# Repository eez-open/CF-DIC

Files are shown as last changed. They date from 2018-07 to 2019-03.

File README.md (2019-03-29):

Current-fed dual inductor converter (CF-DIC) project files

Inspired by article Filho, Barbi (1996), *[A comparison between two current-fed push-pull DC-DC converters-analysis, design and experimentation](https://www.researchgate.net/publication/3673781_A_comparison_between_two_current-fed_push-pull_DC-DC_converters-analysis_design_and_experimentation)* and made with great assistance of Dragoljub Aleksijević (aka *Macola*).

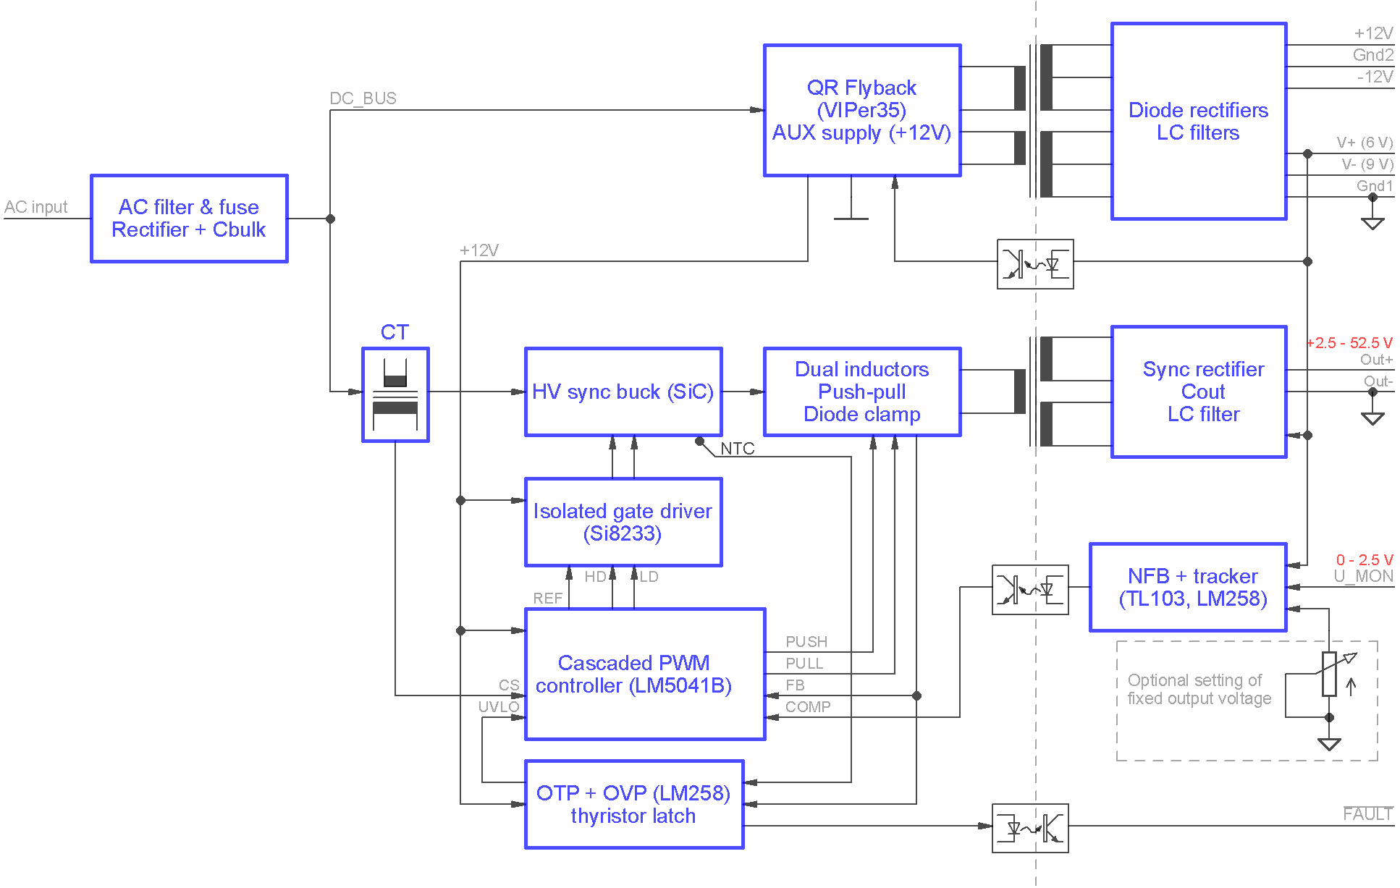
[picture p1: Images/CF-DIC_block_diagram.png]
Block diagram


### Feature list

* Wide range input: 85 – 265 Vac, 120 – 380 Vdc
* Wide range output: 2.5 – 52.5 Vdc 
* Max. current 3 A continuously, or 5 A with forced-air cooling (max. power up to ~260 W)
* Output voltage controlled by tracker circuit or optionally with multiturn trimpot if fixed output voltage is required
* Cascaded PWM Controller LM5041B (sync buck + push-pull stage)
* Isolated HV power ground and signal ground for improved noise immunity
* HV buck section with high performance SiC MOSFET switches
* High performance Vitroperm 500F core material for power transformer
* Synchronous rectifier with low R(ds,on) MOSFET switches
* Over-voltage (OVP), short circuit protection and over-temperature protection (OTP) with latched shutdown and opto-isolated open-collector "Fault" output
* Over-current protection (OCP)
* QR flyback as bias power supply (VIPer35)
* Four bias power supply outputs: +6.5 V, -8 V and "floating" +12 V / -12 V that can be further regulated with LDOs
* Compact size: 157 x 92 x 45 mm
* Weight (with enclosure): 0.49 kg

### r5B6 prototype

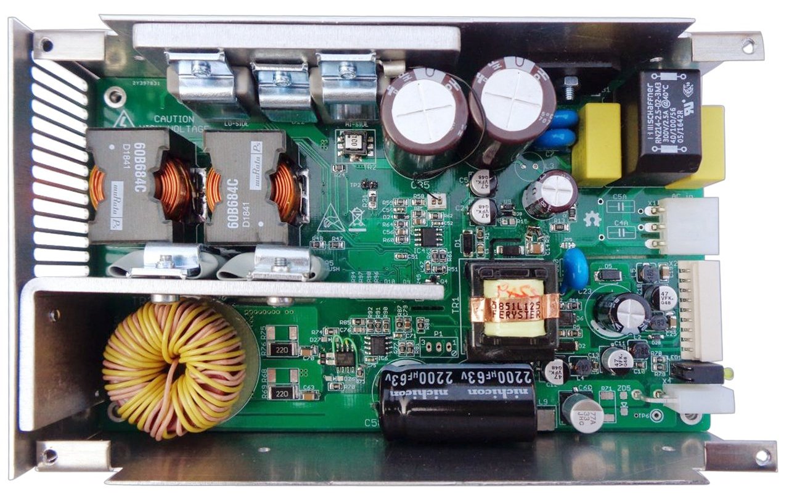
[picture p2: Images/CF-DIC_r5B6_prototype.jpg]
prototype


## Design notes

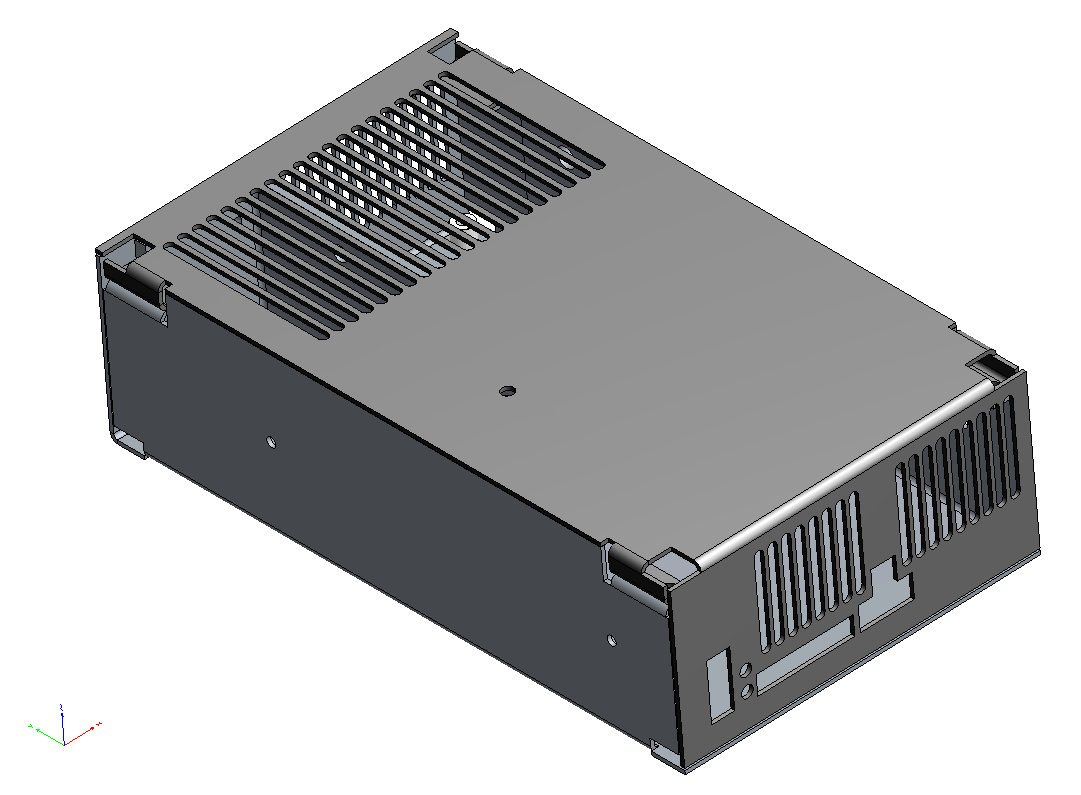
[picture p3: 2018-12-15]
Mechanical/EEZ CF-DIC enclosure prototype.png

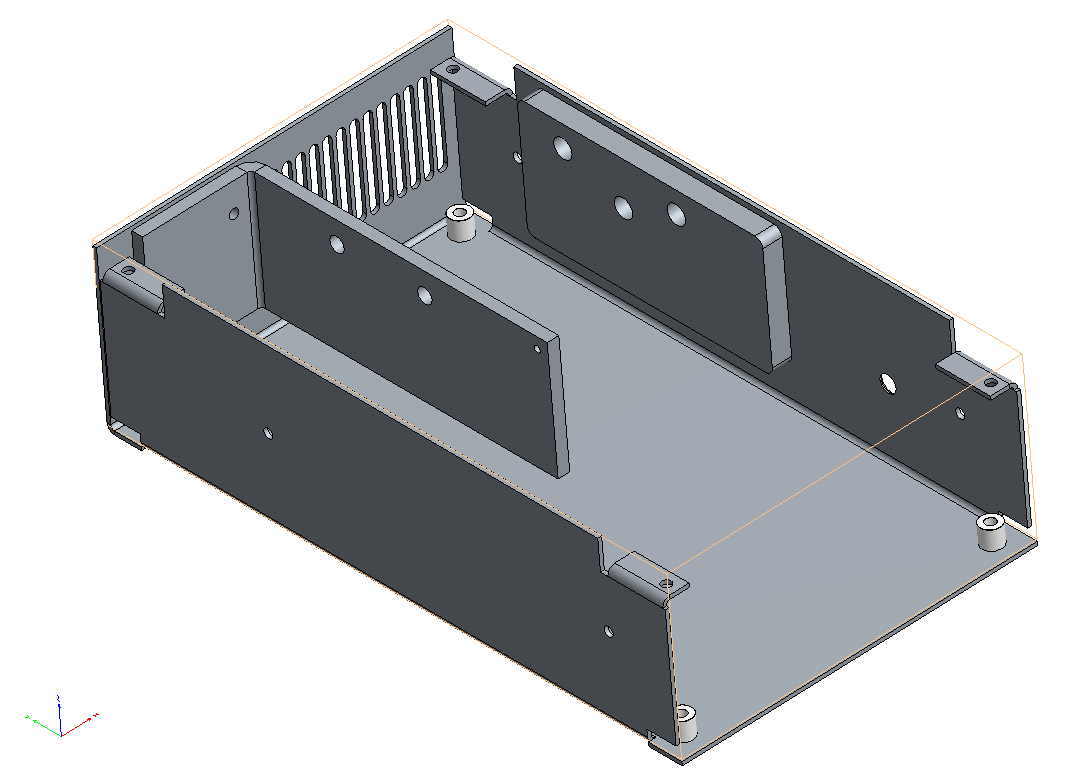
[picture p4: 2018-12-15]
Mechanical/EEZ CF-DIC enclosure prototype (without cover).png

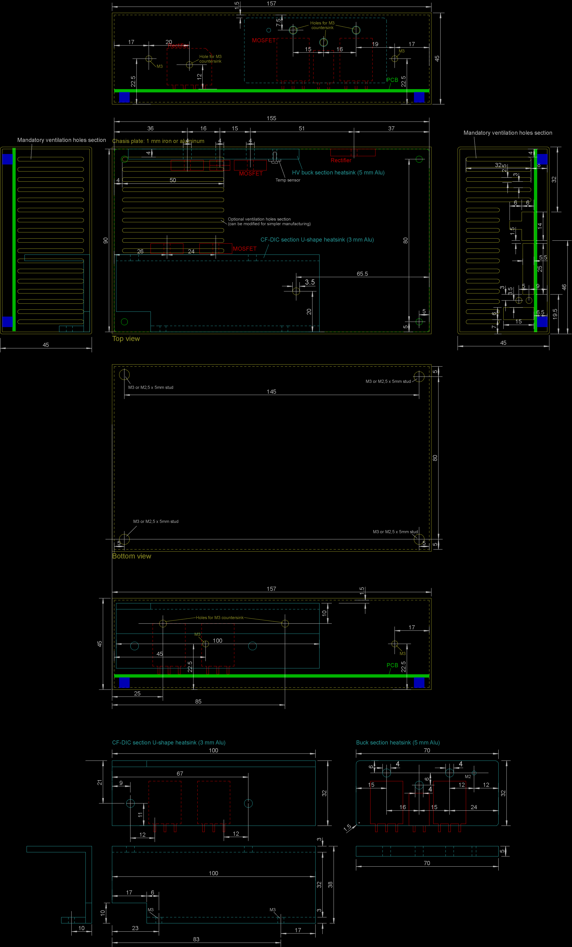
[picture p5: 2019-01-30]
Mechanical/CF-DIC enclosure r5B6.png

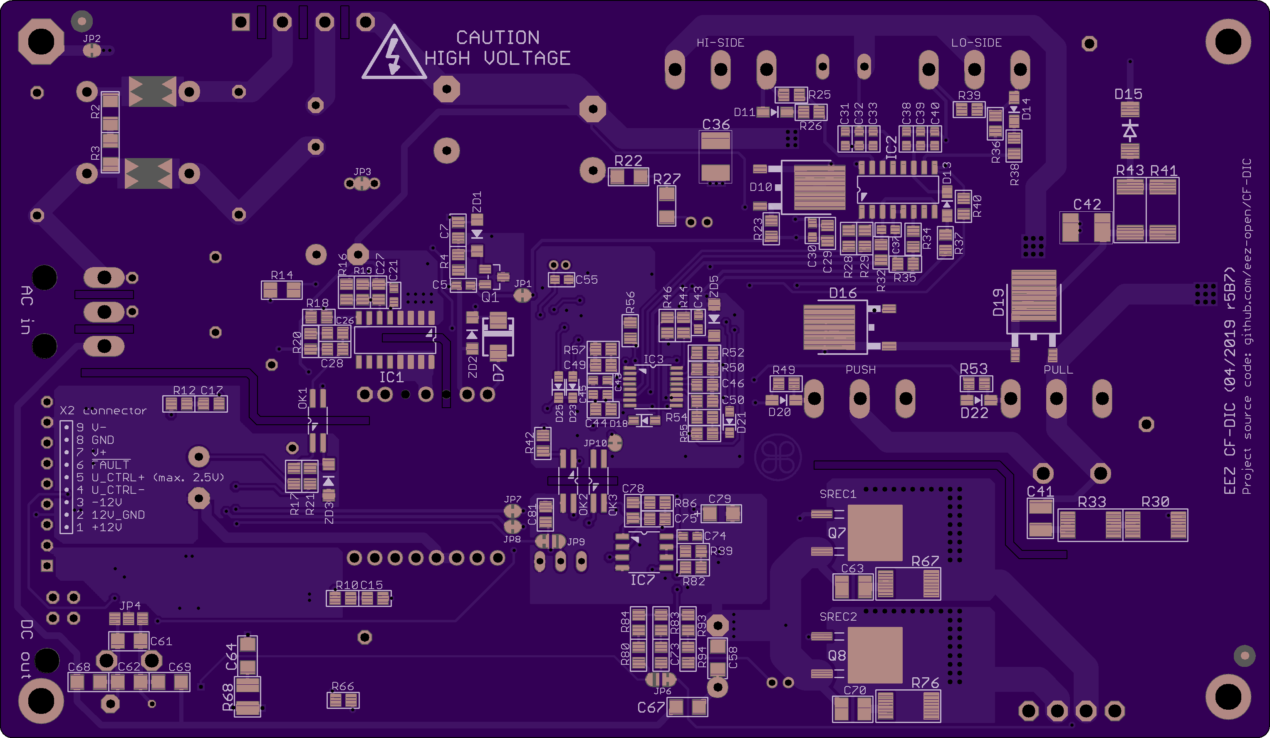
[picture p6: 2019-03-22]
Images/CF-DIC_PCB_bottom_layer.png

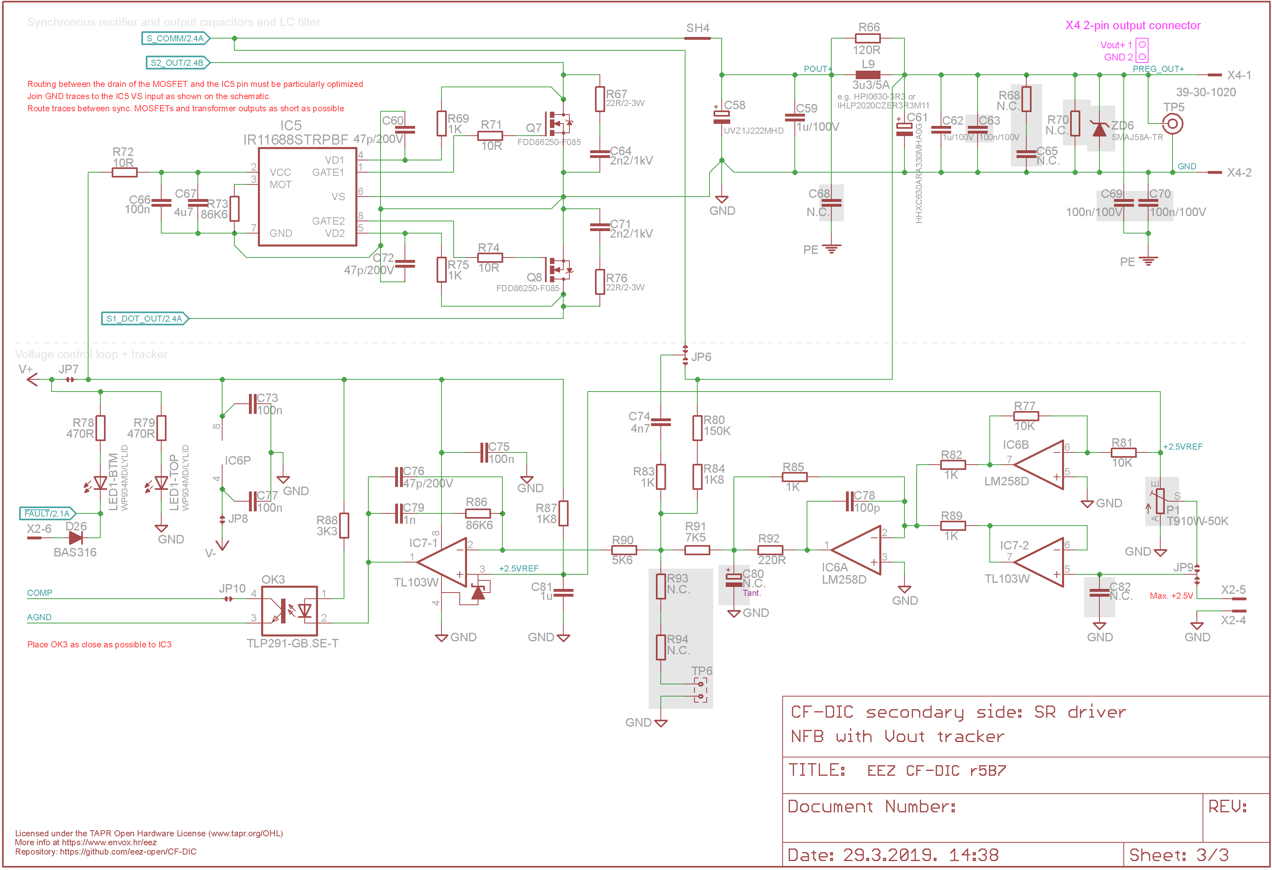
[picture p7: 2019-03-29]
EEZ CF-DIC r5B7 Sheet3of3.png

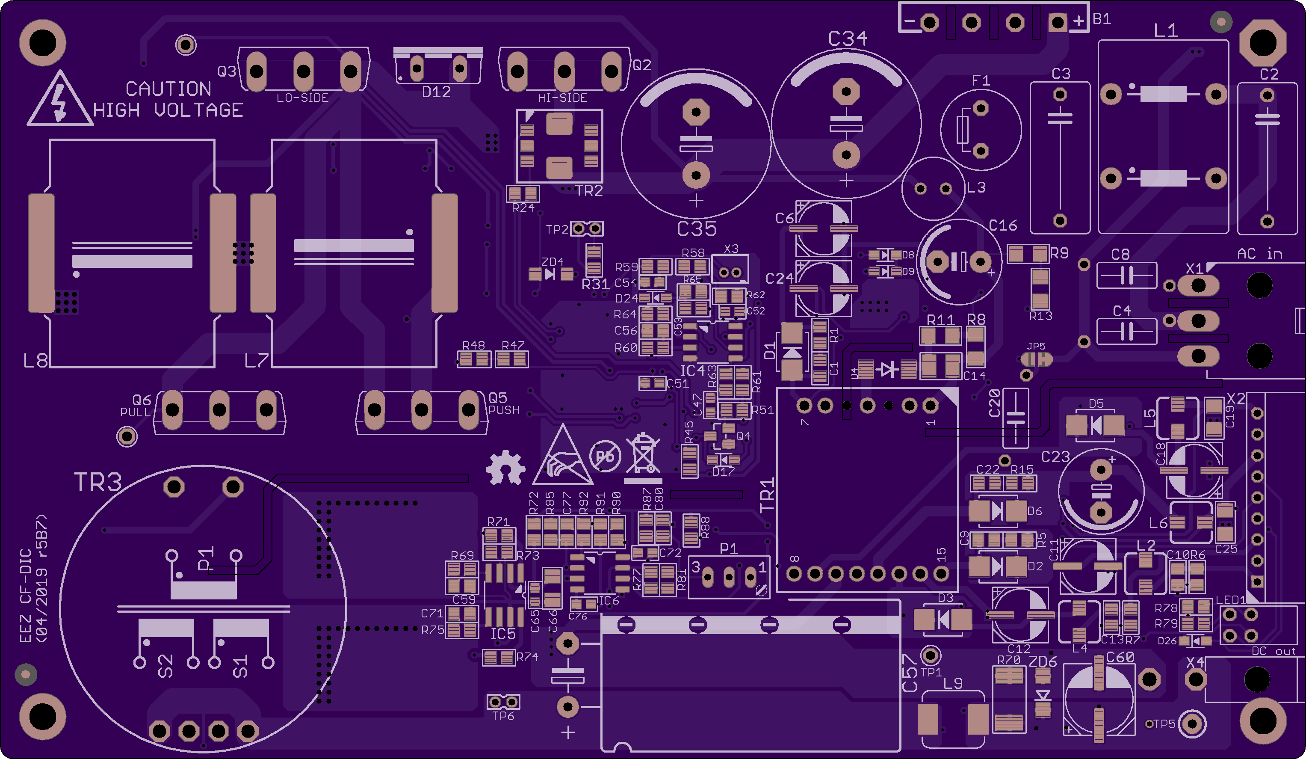
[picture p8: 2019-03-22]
Images/CF-DIC_PCB_top_layer.png

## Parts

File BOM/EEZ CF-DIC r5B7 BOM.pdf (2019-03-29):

EEZ CF-DIC BOM (r5B7, 2019-03-29) Project source code at https://github.com/eez-open/CF-DIC
Farnell / Element14 # Qty Part name Package Reference designator Code Part Number Unit price MOQ € | Digi-Key Part Number Unit price MOQ € | Mouser Part Number Unit price MOQ €
| ND
VJ0805Y332KXAC W1BC | | 80-C0805C332K5R
| | 885342209006
400BXC6R8MEFC 10X16 | | 647-UCY2G6R8MPD
| | 963-EMK316B7475M L-T
THT, PP X2, 18 x 12 x 6 mm, RM 15 | | 80-R463I322050L2K
| | 80-C0603C104M4R
16PK470MEFC8X1 1.5 | | 647-UVZ1C471MPD1 TD
| | 77-VJ0805Y333JXA PBC
| | 710-885342007006
| | 77-VJ0805Y222KXB AC
C0603C103K5RAC 7081 | | 80-C0603C103M5R 3121
| | 647-UPH2G151MHD
C1812C104KBRAC TU | | 810-C4532X7R2J104 M
| | 80-C941U472MYVD BAP
1210 or 1206 MC1210B222K102 CT | | 710-885342208019
| | 710-885012007038
THT, Ø18 x 35.5mm, RM 7.5 | | 647-UVZ1J222MHD
| | 963-HMK316B7105M LHT
Ø6.3 x 5.8 mm | | 667-EEE-FK1V470P
1 | 1 GBU4K | B1 | 2889169 | GBU4K-E3/45 | 1,150 | 5 | 0,750 | 1 | 833-GBU4K-BP | 0,748 | 1
2 | 5 3n3 | 0805 | C1, C9, C15, C17, C22 | 2896578 | 0,025 10 | 1276-1260-1-ND | 0,039 | 10 | 0,024 10
3 | 1 1n/1kV | C14 | 2812601 | 885342209006 | 0,580 | 5 | 732-12116-1-ND | 0,380 | 1 | 0,357 | 1
4 | 1 UCY2G6R8MPD | THT, Ø10.5mm, RM 5 | C16 | 1831309 | 0,868 | 1 | 493-13319-1-ND | 0,730 | 1 | 0,629 | 1
5 | 3 4u7 | 1206 | C19, C25, C67 | 1907356 | 0,240 | 5 | 1276-2970-1-ND | 0,199 | 10 | 0,129 10
6 | 2 MKP-X2-220NR15/310 | C2, C3 | 2446244 | R463I322050L2K | 0,337 | 1 | 399-12681-ND | 0,600 | 1 | 0,600 | 1
7 | 16 100n | 0603 | 2522597 | 0,011 10 | 490-4774-1-ND | 0,029 100 | 0,007 100
8 | 1 470u/16V | THT; Ø8; RM3.5 | C23 | 2346502 | 0,206 | 5 | 493-1286-ND | 0,215 | 10 | 0,194 10
9 | 1 33n | 0805 | C26 | 1414688 | 0,051 10 | 1276-1796-1-ND | 0,068 | 10 | 0,020 50
10 | 4 47p/200V | 0805, C0G | C27, C60, C72, C76 | 2812527 | 885342007006 | 0,081 10 | 885342007006 | 0,058 | 10 | 0,055 10
11 | 1 2n2 | 0805 | C28 | 2896572 | 0,028 10 | 720-1604-1-ND | 0,063 | 10 | 0,032 50
12 | 4 10n | 0603 | C31, C38, C47, C52 | 2522596 | 0,042 10 | 399-1092-1-ND | 0,040 | 10 | 0,031 10
13 | 2 UPH2G151MHD6 | THT, Ø18mm, RM 7.5 | C34, C35 | - | 493-16993-ND | 3,550 | 1 | 3,550 | 1
14 | 2 100n/500V | 1812 | C36, C41 | 2676599 | 0,600 | 1 | 445-2300-1-ND | 0,453 | 10 | 0,408 10
15 | 3 CY1Y-4N7 | C4, C8, C20 | 2440246 | 0,772 | 1 | 399-9504-1-ND | 0,293 | 10 | 0,215 10
16 | 4 2n2/1kV | C44, C48, C64, C71 | 1855965 | 0,496 | 5 | 490-12018-1-ND | 0,502 | 10 | 0,121 10
17 | 2 470p | 0805, C0G | C50, C51 | 1759217 | 0,061 10 | 732-7837-1-ND | 0,059 | 10 | 0,056 10
18 | 1 UVZ1J222MHD | C58 | 1822575 | UVZ1J222MHD | 3,430 | 1 | 493-1360-ND | 2,370 | 1 | 2,490 | 1
19 | 2 1u/100V | 1206 | C59, C62 | 2491179 | 0,374 | 5 | 1276-3094-1-ND | 0,240 | 10 | 0,306 10
20 | 5 EEEFK1V470P | C6, C11, C12, C18, C24 | 9695850 | EEEFK1V470P | 0,344 | 1 | PCE3842CT-ND | 0,312 | 10 | 0,238 10
THT, bridge rectifier 800V, 4A | GBU4K-BPMS-
1210 or 1206 | 710-

C3216X7R1E475K
160AC

C21, C30, C32, C33, C37,
C39, C40, C42, C45, C49,
C53, C55, C66, C73, C75,
C77

C0603C104K4RAC
7081

C0805C333K5RAC
TU

VJ0805Y222KXAC
W1BC
THT, Ceramic Y1, RM 10 | C951U472MVVDB A7317

MC0805N471J500
CT

C1206C105K1RAC
TU

# Qty Part name | RS Components | TME | Price calculation for 1 set

Code Part Number Unit price MOQ € | Code / Part Number Unit price MOQ € | THT SMD

1 1 GBU4K

2 5 3n3

3 1 1n/1kV

4 1 UCY2G6R8MPD

5 3 4u7

6 2 MKP-X2-220NR15/310

7 16 100n

8 1 470u/16V

9 1 33n

10 4 47p/200V

11 1 2n2

12 4 10n

13 2 UPH2G151MHD6

14 2 100n/500V

15 3 CY1Y-4N7

16 4 2n2/1kV

17 2 470p

18 1 UVZ1J222MHD

19 2 1u/100V

20 5 EEEFK1V470P

700-5437 GBU4K-E3/45 | 1,448 | 5 | GBU4K | 0,355 | 3 | 1 | TME | 0,355 € | 1 | 0,355
237-7009 | 0,060 50 | 0,023 100 | 5 | TME | 0,023 € | 5 | 0,116
500-2499 | 0,880 | 5 | 1210B102K102CT | 0,343 10 | 1 | TME | 0,343 € | 1 | 0,343
739-4551 UCA2G6R8MPD | 1,008 | 1 | UCY2G6R8MPD | 0,240 | 5 | 1 | TME | 0,240 € | 1 | 0,240
691-1221 | 0,232 25 | 0,381 10 | 3 | Mouser | 0,129 € | 3 | 0,387
875-2257 | 0,372 25 | MKP-X2-220NR15/310 | 0,116 10 | 2 | TME | 0,116 € | 2 | 0,231
393-6952 | 0,069 25 | CL10B104KA8NNNC | 0,098 100 | 16 | Mouser | 0,007 € 16 | 0,112
845-4666 UVZ1C471MPD | 0,215 25 | UVZ1C471MPD | 0,140 | 5 | 1 | TME | 0,140 € | 1 | 0,140
652-0982 | 0,066 25 | CL21B333KBANNNC | 0,035 100 | 1 | Mouser | 0,020 € | 1 | 0,020
535-2873 | 0,039 50 | 0805N470J201CT | 0,031 100 | 4 | TME | 0,031 € | 4 | 0,123
264-4359 | 0,031 25 | 0,020 100 | 1 | TME | 0,020 € | 1 | 0,020
264-4595 | 0,035 25 | C0603X103K5RACTU | 0,080 100 | 4 | Mouser | 0,031 € | 4 | 0,124
- | | | UPH2G151MHD6 | 1,950 | 1 | 2 | TME | 1,950 € | 2 | 3,900
371-6887 C4532JB2J104K | 0,460 10 | 1812B104K501CT | 0,663 10 | 2 | Mouser | 0,408 € | 2 | 0,816
- | CY1Y-4N7 | 0,153 10 | 3 | TME | 0,153 € | 3 | 0,458
723-6492 | 0,246 25 | 1206B222K102CT | 0,030 50 | 4 | TME | 0,030 € | 4 | 0,118
378-700 | 0,040 25 | 0,024 100 | 2 | TME | 0,024 € | 2 | 0,048
862-1759 UVZ1J222MHD | 2,440 | 1 | UVZ1J222MHD | 1,209 | 2 | 1 | TME | 1,209 € | 1 | 1,209
916-2977 | 0,290 20 | CL31B105KCHSNNE | 0,211 10 | 2 | TME | 0,211 € | 2 | 0,422
537-0657 EEEFK1V470P | 0,394 | 5 | EEEFK1V470P | 0,130 | 5 | 5 | TME | 0,130 € | 5 | 0,650

Best
Supplier

Lowest
unit price
€

Order
Qty Line Cost €

GRM216R71H3
32KA01D

VJ0805Y333KXACW1
BC
C1210C102JDG
ACTU

C1206C475K3R
ACTU

GCM31CR71E475KA5 5L

| R463I322050M2 K

VJ0603Y104KXJ
AT

VJ0805Y333KX
AAT

VJ0805A470JX CAC

| VJ0805Y222KXACW1 BC

C0603C103K5R ACTU

C0805C222K5R
ACTU

GRM31BR73A2 22KW01L

| CC0805JRNPO9BN47 1

0805CG471J9B
B

C3216X7R2A10
5K160AM

# Qty Part name Package Reference designator Code Part Number Unit price MOQ € | Part Number Unit price MOQ € | Part Number Unit price MOQ €

| | 0MHA0G
VJ0805Y104KXBT W1BC | | 810-C2012X7R2A104 K
| | 603-CC805MKX7R7B B105
24 | 1 4n7 0804 C74
| | | 80-C0805C101J5G
| VJ0805A102JXAC W1BC | | 710-885012007040
21 | 1 | C61 | - | 565-4788-1-ND | 0,890 | 1 | 0,770 | 1
22 | 1 100n/100V | 1206 | C63 | 2896560 | 0,070 10 | 1276-6840-1-ND | 0,068 | 10 | 0,065 10
23 | 9 1u | 0805 | 2896566 | 0,084 | 5 | 587-1283-1-ND | 0,090 | 10 | 0,062 10
25 | 1 100p | 0805, C0G | C78 | 2896466 | 0,041 10 | 399-1121-1-ND | 0,061 | 10 | 0,022 10
26 | 1 1n | 0805, C0G | C79 | 2896470 | 0,044 10 | 732-7858-1-ND | 0,055 | 10 | 0,052 10
27 | 6 SS110B | SMB | D1, D2, D3, D5, D6, D7 | 1861422 | SS110B | 0,097 | 5 | SS110-TPCT-ND | 0,350 | 1 | 833-SS110FL-TP | 0,323 | 1
28 | 3 C3D02065E | TO-252 (DPAK) | D10, D16, D19 | - | | | | C3D02065E-ND | 0,860 | 1 | 941-C3D02065E | 0,859 | 1
29 | 1 C3D03060A | THT, TO-220 | D12 | - | | | | C3D03060A-ND | 1,250 | 1 | 941-C3D03060A | 1,240 | 1
30 | 1 1N5819HW-7-F | SOD-323 | D13 | 2306459 | 1N5819HW-7-F | 0,183 10 | 0,310 | 10 | 0,281 10
31 | 2 US1K-DIO | DO-214AA | D4, D15 | 2306342 | US1K-13-F | 0,146 | 1 | US1K-FDICT-ND | 0,340 | 1 | 621-US1K-F | 0,366 | 1
32 | 9 BAS316 | SOD-323 | | 8734275 | BAS316,115 | 0,193 | 5 | 1727-7370-1-ND | 0,120 | 1 | 771-BAS316-T/R | 0,179 | 1
33 | 1 0031.7601 | | F1 | 4591999 | 0031.7601 | 0,628 | 1 | 486-1244-ND | 0,830 | 1 | 693-0031.7601 | 0,840 | 1
34 | 1 VIPer35L | SOIC-16 | IC1 | 2612169 | VIPER35LD | 1,130 | 1 | 497-16075-5-ND | 1,040 | 1 | 511-VIPER35LD | 1,040 | 1
35 | 1 SI8233BB-D-IS1 | SOIC-16 | IC2 | 2423138 | SI8233BB-D-IS1 | 2,460 | 1 | 336-3066-ND | 2,050 | 1 | | 2,410
36 | 1 LM5041B | TSSOP-16 | IC3 | - | | | | | 3,110 | 1 | | 3,090 | 1
37 | 2 LM258D | SOIC-8 | IC4, IC6 | 2323288 | LM258D | 0,274 | 5 | 296-14591-1-ND | 0,271 | 10 | 595-LM258DR | 0,248 10
38 | 1 IR11688STRPBF | SOIC-8 | IC5 | 2780950 | IR11688STRPBF | 1,520 | 1 | | 1,680 | 1 | | 1,550 | 1
39 | 1 TL103W | SOIC-8 | IC7 | 1755223 | TL103WID | 0,665 | 1 | 296-18862-1-ND | 0,610 | 1 | 595-TL103WID | 0,706 | 1
40 | 1 RN214-2.5-02-3M3 | | L1 | - | | | | 817-2186-ND | 1,550 | 1 | | 1,460 | 1
41 | 4 DLG-0403-180 | 0403 inductor | L2, L4, L5, L6 | SDR0403-180M | 0,404 | 5 | 0,424 | 10 | 0,272 10
42 | 2 60B684C | | L7, L8 | 2290311 | 60B684C | 5,140 | 1 | 811-2466-ND | 2,540 | 1 | 580-60B684C | 2,520 | 1
43 | 1 3u3/5A | | L9 | 1741325 | | 1,940 | 5 | 541-1237-1-ND | 2,040 | 1 | | 2,140 | 1
44 | 1 WP934MD/LYLID | THT, dual 3 mm LED | LED1 | - | | | | 754-2008-ND | 0,980 | 1 | | 0,800 | 1
45 | 3 TLP291-GB.SE-T | SOIC-4 | OK1, OK2, OK3 | 2524307 | TLP291(GB,SE | 0,196 | 1 | - | | | -
46 | 1 MMBT5551 | SOT-23 | Q1 | 1459109 | MMBT5551LT1G | 0,154 | 5 | | 0,180 | 1 | | 0,170 | 1
47 | 2 C3M0280090D | THT, TO-247 | Q2, Q3 | 2630827 | C3M0280090D | 3,710 | 1 | | 3,110 | 1 | | 2,950 | 1
48 | 1 NYC0102BLT1G | SOT-23 | Q4 | 2533159 | NYC0102BLT1G | 0,360 | 5 | | 0,430 | 1 | | 0,472 | 1

HHXC630ARA330MHA0
G
Ø8 x 10 mm | HHXC630ARA33

C7, C10, C13, C29, C43,
C46, C54, C57, C81

VJ0805Y105KXXT
W1BC

VJ0805A101JXAC
W1BC

1N5819HW-FDICT-ND

621-1N5819HW-F

D8, D9, D17, D18, D21, D23, D24, D25, D26
THT, TR5 fuse holder

634-SI8233BB-D-IS1

LM5041BMTC/N OPB-ND | 926-LM5041BMTC/N OPB

IR11688STRPBF
CT-ND

942-
IR11688STRPBF
THT, Common Mode Choke | | 631-RN214-2.5-02-3M3
| SDR0403-180MLCT-ND | 652-SDR0403-180ML

Murata power inductor 6000B
| | 70-IHLP2020CZER3 R3M1
| | 604-WP934MDLYLID

SDR0403-
180ML
Vishay power inductor | IHLP2020CZER3R 3M11
MMBT5551LT1G OSCT-ND | 863-MMBT5551LT1G
C3M0280090D-ND | 941-C3M0280090D
NYC0102BLT1G OSCT-ND | 863-NYC0102BLT1G

# Qty Part name

21 1

22 1 100n/100V

23 9 1u

24 1 4n7
| | VJ0805A101JXACW1 BC
| GRM2195C1H1 02JA01D

25 1 100p

26 1 1n

27 6 SS110B
28 3 C3D02065E
29 1 C3D03060A
30 1 1N5819HW-7-F

31 2 US1K-DIO
32 9 BAS316

33 1 0031.7601
34 1 VIPer35L
35 1 SI8233BB-D-IS1

36 1 LM5041B

37 2 LM258D
38 1 IR11688STRPBF

39 1 TL103W
40 1 RN214-2.5-02-3M3

41 4 DLG-0403-180

42 2 60B684C
43 1 3u3/5A

44 1 WP934MD/LYLID

45 3 TLP291-GB.SE-T

46 1 MMBT5551

47 2 C3M0280090D

48 1 NYC0102BLT1G

HHXC630ARA330MHA0
G
Code Part Number Unit price MOQ € | Code / Part Number Unit price MOQ € | THT SMD

Best
Supplier

Lowest
unit price
€

Order
| | | | | | | Qty | Line Cost €
- | | - | | 1 | Mouser | 0,770 € | 1 | 0,770
| 0,047 100 | CL21B104KCFSFNE | 0,071 10 | 1 | RS | 0,047 € | 1 | 0,047
451-5770 | 0,028 25 | CL21B105KOFNNNE | 0,010 100 | 9 | TME | 0,010 € | 9 | 0,094
461-3997 | 0,017 25 | 0,024 100 | 1 | RS | 0,017 € | 1 | 0,017
723-6408 | 0,031 100 | CL21C102JBCNNNC | 0,026 100 | 1 | TME | 0,026 € | 1 | 0,026
743-5992 SS110 R3 | 0,154 25 | SS110-JGD | 0,053 | 5 | 6 | TME | 0,053 € | 6 | 0,319
915-8846 C3D02065E | 0,869 10 | C3D02065 | 0,620 | 3 | 3 | TME | 0,620 € | 3 | 1,860
702-7447 C3D03060A | 1,260 | 1 | C3D03060A | 0,850 | 2 | 1 | TME | 0,850 € | 1 | 0,850
708-2197 1N5819HW-7-F | 0,252 25 | 1N5819HW-7-F | 0,086 10 | 1 | TME | 0,086 € | 1 | 0,086
751-5130 US1K-13-F | 0,106 25 | US1K-DIO | 0,067 10 | 2 | TME | 0,067 € | 2 | 0,135
397-2914 BAS316,115 | 0,122 50 | BAS316,115 | 0,026 25 | 9 | TME | 0,026 € | 9 | 0,238
866-4790 0031.7601 | 0,442 50 | 0031.7601 | 0,281 | 5 | 1 | TME | 0,281 € | 1 | 0,281
124-1146 VIPER35LDTR | 1,544 | 5 | - | 1 | Digikey | 1,040 € | 1 | 1,040
- | - | 1 | Digikey | 2,050 € | 1 | 2,050
- | - | 1 | Mouser | 3,090 € | 1 | 3,090
660-9555 LM258DGKR | 0,244 10 | LM258D-ST | 0,114 | 5 | 2 | TME | 0,114 € | 2 | 0,227
- | IR11688STRPBF | 1,580 | 1 | 1 | Farnell | 1,520 € | 1 | 1,520
809-5334 TL103WID | 0,692 | 5 | - | 1 | Digikey | 0,610 € | 1 | 0,610
133-6257 | 1,742 | 1 | - | | | 1 | Mouser | 1,460 € | 1 | 1,460
798-0938 | 0,336 | DLG-0403-180 | 0,129 10 | 4 | TME | 0,129 € | 4 | 0,514
749-6427 60B684C | 2,650 | 1 | - | 2 | Mouser | 2,520 € | 2 | 5,040
- | HPI0630-3R3 | 0,335 | 1 | 1 | TME | 0,335 € | 1 | 0,335
- | | | - | | | 1 | Mouser | 0,800 € | 1 | 0,800
144-5264 | 0,116 50 | TLP291-GB.SE-T | 0,126 | 5 | 3 | RS | 0,116 € | 3 | 0,348
545-0400 | 0,146 10 | MMBT5551 | 0,024 25 | 1 | TME | 0,024 € | 1 | 0,024
915-8842 C3M0280090D | 3,100 | 2 | - | | | 2 | Mouser | 2,950 € | 2 | 5,900
808-3993 NYC0102BLT1G | 0,268 50 | NYC0102BLT1G-LF | 0,166 | 3 | 1 | TME | 0,166 € | 1 | 0,166

C2012X7R2A10
4M125AA

C0805C105K4R
ACTU

CC0805JRNP09
BN101

RN214-2.5-02-
3M3
SDR0403-
180ML

TLP291(GB-TP,SE(T
MMBT5551LT1
G

# Qty Part name Package Reference designator Code Part Number Unit price MOQ € | Part Number Unit price MOQ € | Part Number Unit price MOQ €

| IRFP4332PBF-ND | 942-IRFP4332PBF
Option #1: FDD86250-F085 | FDD86250-F085OSCT-ND | 863-FDD86250-F085
| SUD80460E-GE3-ND | 78-SUD80460E-GE3
MCWR08X1200FT L | RMCF0805FT12 0RCT-ND | 71-CRCW0805120R FKEAC
| | 603-RC0805FR-0730KL
R17, R21, R40, R42, R56, R61, R64, R65, R69, R75, R82, R83, R85, R89 | RC0805FR-071KL | 603-RC0805FR-071KL
| RHM470KPCT-ND | 603-RV1206FR-07470KL
MCWR08X4702FT L | RHM47KKCT-ND | 603-RC0805FR-0747KL
| 311-10.0CRCT-ND | 603-RC1206FR-0710RL
RC0805FR-0710KL | 311-10.0KCRCT-ND | 603-RC0805FR-0710KL
| 311-100CRCT-ND | RC0805FR-07100RL
49 | 2 IRFP4332PBF | THT, TO-247 | Q5, Q6 | 1436966 | IRFP4332PBF | 3,820 | 1 | 4,280 | 1 | 3,670 | 1
50 | 2 | TO-252 (DPAK) | Q7, Q8 | 2895710 | FDD86250-F085 | 1,510 | 5 | 1,590 | 1 | 1,280 | 1
0 | TO-252 (DPAK) | Q7, Q8 | 2708325 | SUD80460E-GE3 | 1,010 | 5 | 0,970 | 1 | 0,840 | 1
51 | 6 120R | 0805 | R1, R5, R10, R12, R15, R66 2447561 | 0,009 10 | 0,020 | 10 | 0,037 10
52 | 3 30K | 0805 | R16, R32, R62 | 2303701 | ERJ6ENF3002V | 0,058 10 | P30.0KCCT-ND | 0,085 | 10 | 0,014 10
53 | 14 1K | 0805 | 1099800 | WCR0805-1K0FI | 0,019 10 | 0,039 | 10 | 0,015 10
54 | 2 470K | R2, R3 | 2826395 | 0,060 10 | 0,115 | 10 | 0,184 10
55 | 2 47K | 0805 | R20, R37 | 2447664 | 0,009 10 | 0,036 | 10 | 0,014 10
56 | 11 10R | 0805 | 9236643 | 0,050 10 | 0,071 | 10 | 0,034 10
57 | 4 10K | 0805 | R24, R63, R77, R81 | 9237755 | 0,022 10 | 0,039 | 10 | 0,014 10
58 | 2 100R | 0805 | R28, R29 | 2447552 | 0,094 10 | 0,039 | 10 | 0,014 10
59 | 3 22R/2-3W | 2512 | R39, R67, R76 | 2116456 | RLP73K3AR22JTE | 0,380 | 5 | A126461CT-ND | 0,409 | 10 | 279-352122RFT | 0,122 10
60 | 6 86K6 | 0805 | 2303750RL ERJ6ENF8662V | 0,058 10 | 0,036 | 10 | 0,056 10
61 | 2 1R | 0805 | R33, R38 | 2447598 | 0,012 10 | 0,071 | 10 | 0,020 10
62 | 4 1K8 | 0805 | R4, R18, R84, R87 | 2447595 | 0,009 10 | A129752CT-ND | 0,028 | 10 | 0,008 10
63 | 1 8K2 | 0805 | R44 | 2447732 | 0,010 10 | 0,037 | 10 | 0,013 10
65 | 1 15K | 0805 | R49 | 1099808 | WCR0805-15KFI | 0,019 10 | A126341CT-ND | 0,041 | 10 | 0,013 10
66 | 1 68K | 0805 | R51 | 2861918 | CRGCQ0805J68K | 0,010 10 | A126382CT-ND | 0,045 | 10 | 0,013 10
67 | 2 220R | 0805 | R52, R92 | 1099795 | WCR0805-220RFI | 0,019 10 | | 0,020 | 10 | 0,020 10
68 | 1 6R2 | 0805 | R55 | 2447714 | | 0,012 10 | | 0,070 | 10 | 0,020 10
69 | 2 7K5 | 0805 | R57, R91 | 2447722 | | 0,010 10 | | 0,040 | 10 | 0,040 10
70 | 2 5K6 | 0805 | R59, R90 | 2447693 | | 0,010 10 | | 0,040 | | 0,027
71 | 5 4K7 | 0805 | R6, R7, R19, R50, R58 | 2861530 | CRGCQ0805F4K7 | 0,012 10 | | 0,040 | 10 | 0,027 10

Option #2: SUD80460E-GE

1206, High Voltage | MCHVR06JTEV47
| 03

R23, R25, R31, R34, R35,
R43, R47, R53, R71, R72,
R74

RC1206FR-0710RL

MCWR08X1000FT
L

R30, R45, R46, R60, R73,
R86
311-86.6KCRCT-ND | 603-RT0805FRE0786 K6L
MCWR08W1R00F TL | 311-1.00CRCT-ND | 603-RC0805FR-131RL
| | 652-CR0805JW-182ELF
MCWR08X8201FT L | 311-8.20KCRCT-ND | 652-CR0805FX-8201ELF
64 | 2 47R/2-3W 2512 R48, R54
| | | 71-CRCW080515K0 FKEBC
| | | 652-CR0805FX-6802ELF
| | RMCF0805FT22 0RCT-ND | 603-RC0805FR-13220RL
| | 311-6.20CRCT-ND | 603-RC0805FR-076R2L
| MCWR08X7501FT L | 311-7.50KCRCT-ND | 667-ERJ-6ENF7501V
| | RC0805FR-075K6L | RC0805FR-075K6L
| | 311-4.70KCRCT-ND | 603-RC0805FR-074K7L

MCWR08X1801FT
L

MCWR08W6R20F
TL

MCWR08X5601FT
L

# Qty Part name

49 2 IRFP4332PBF

50 2

0

51 6 120R

52 3 30K

53 14 1K

54 2 470K

55 2 47K

56 11 10R

57 4 10K

58 2 100R

59 3 22R/2-3W
60 6 86K6

61 2 1R

62 4 1K8

63 1 8K2

64 2 47R/2-3W
65 1 15K

66 1 68K

67 2 220R

68 1 6R2

69 2 7K5

70 2 5K6

71 5 4K7

Option #1: FDD86250-
F085
Option #2: SUD80460E-GE
Code Part Number Unit price MOQ € | Code / Part Number Unit price MOQ € | THT SMD

Best
Supplier

Lowest
unit price
€

Order
Qty | Line Cost €
- | IRFP4332PBF | 1,790 | 1 | 2 | TME | 1,790 € | 2 | 3,580
- | - | 2 | Mouser | 1,280 € | 2 | 2,560
- | - | Mouser | 0,840 € | 0 | 0,000
223-0304 CRG0805F120R | 0,035 50 | SMD0805-120R-1% | 0,022 100 | 6 | Farnell | 0,009 € | 6 | 0,056
- | SMD0805-30K-1% | 0,022 100 | 3 | Mouser | 0,014 € | 3 | 0,042
223-0427 CRG0805F1K0 | 0,017 50 | RC0805FR-071K | 0,022 100 | 14 | Mouser | 0,015 € 14 | 0,210
- | - | 2 | Farnell | 0,060 € | 2 | 0,121
679-1434 | 0,036 50 | RC0805FR-0747K | 0,022 100 | 2 | Farnell | 0,009 € | 2 | 0,019
740-9085 | 0,036 50 | 0,031 100 | 11 | TME | 0,031 € 11 | 0,341
125-1189 CRG0805F10K | 0,002 100 | RC0805FR-0710K | 0,022 100 | 4 | RS | 0,002 € | 4 | 0,008
679-0807 | 0,043 50 | SMD0805-100R-1% | 0,022 100 | 2 | Mouser | 0,014 € | 2 | 0,028
224-0187 352022RJT | 0,128 10 | WF25P-22R-5% | 0,072 50 | 3 | TME | 0,072 € | 3 | 0,215
- | 0,025 100 | 6 | TME | 0,025 € | 6 | 0,150
740-9151 | 0,027 50 | SMD0805-1R-1% | 0,032 100 | 2 | Farnell | 0,012 € | 2 | 0,023
223-0461 CRG0805F1K8 | 0,022 50 | SMD0805-1K8-1% | 0,022 100 | 4 | Mouser | 0,008 € | 4 | 0,032
223-0556 CRG0805F8K2 | 0,021 50 | SMD0805-8K2-1% | 0,014 100 | 1 | Farnell | 0,010 € | 1 | 0,010
2 | Farnell | 0,000 € | 2 | 0,000
223-0584 CRG0805F15K | 0,023 50 | SMD0805-15K | 0,013 100 | 1 | Mouser | 0,013 € | 1 | 0,013
223-0663 CRG0805F68K | 0,027 50 | SMD0805-68K-1% | 0,014 100 | 1 | Farnell | 0,010 € | 1 | 0,010
223-0332 CRG0805F220R | 0,018 50 | SMD0805-220R-1% | 0,022 100 | 2 | RS | 0,018 € | 2 | 0,036
- | RC0805JR-076R2 | 0,034 100 | 1 | Farnell | 0,012 € | 1 | 0,012
679-1686 | 0,038 50 | SMD0805-7K5-1% | 0,023 100 | 2 | Farnell | 0,010 € 10 | 0,097
679-1572 | 0,029 50 | SMD0805-5K6-1% | 0,023 100 | 2 | Farnell | 0,010 € | 2 | 0,019
223-0528 CRG0805F4K7 | 0,023 50 | SMD0805-4K7-1% | 0,023 100 | 5 | Farnell | 0,012 € | 5 | 0,059

CRCW080547K 0FKEA

| CRCW120610R0FKTA BC

CR1206-FX-10R0ELF

CRCW0805100
RFKEA

CRCW080586K6FKTA BC

| CR0805-J/-1R0ELF

CRCW08057K5
0FKEA
CRCW08055K6
0FKEA

# Qty Part name Package Reference designator Code Part Number Unit price MOQ € | Part Number Unit price MOQ € | Part Number Unit price MOQ €

| 311-470CRCT-ND | 71-CRCW0805470R FKEB
1206, High Voltage R8, R9, R11, R13, R14, R22, MCHVR06JTEV10 R27 03 | RHM100KPCT-ND | 603-RV1206FR-07100KL
| 311-150KCRCT-ND | 667-ERJ-6ENF1503V
MCWR08X3301FT L | 311-3.30KCRCT-ND | 652-CR0805-FX3301GLF
72 | 2 470R | 0805 | R78, R79 | 1099798 | WCR0805-470RFI | 0,019 10 | 0,039 | 10 | 0,041 10
73 | 7 100K | 2826380 | 0,060 10 | 0,115 | 10 | 0,217 10
74 | 1 150K | 0805 | R80 | 2447573 | 0,010 10 | 0,037 | 10 | 0,040 10
75 | 1 3K3 | 0805 | R88 | 2447651 | 0,009 10 | 0,039 | 10 | 0,013 10
76 | 1 53100C | TR2 | 2840104 | 53100C | 2,380 | 1 | 811-1193-1-ND | 1,500 | 1 | 580-53100C | 1,500 | 1
77 | 1 39-30-3035 | X1 | 9963545 | 39303035 | 0,572 10 | WM18446-ND | 0,670 | 1 | 538-39-30-3035 | 0,672 | 1
78 | 1 22-05-7095 | X2 | - | WM18907-ND | 1,090 | 1 | 538-22-05-7095 | 0,781 10
79 | 1 B2B-ZR | X3 | 9491775 | B2B-ZR(LF)(SN) | 0,071 100 | 455-1657-ND | 0,150 | 1 | -
80 | 1 39-30-1020 | X4 | 9732080 | 39-28-1023 | 0,367 | 1 | WM3800-ND | 0,530 | 1 | 538-39-28-1023 | 0,530 | 1
81 | 1 BZT52C13 | ZD1 | 2306055 | BZT52C13-7-F | 0,106 10 | 0,178 | 10 | 0,118 10
82 | 1 BZT52C20-DC | ZD2 | 2824935 | | 0,047 | 5 | 1727-8128-1-ND | 0,180 | 1 | | 0,170 | 1
83 | 1 MMSZ5V1T1G | ZD3 | 1431291 | MMSZ5V1T1G | 0,158 | 5 | | 0,140 | 1 | | 0,170 | 1
84 | 1 BZT52C6V2 | ZD4 | 1902438 | BZT52C6V2 | 0,106 25 | 1727-7698-1-ND | 0,166 | 10 | 0,151 10
1 NTCALUG03A103HC | NTC1 | 2885270 | 1,960 | 1 | BC2382-ND | 2,340 | 1 | 1,550 | 1
4 | -
5 | -

3

8 | -
2 | -
1 | TR1

MCWR08X1503FT
L

Murata 5300 current
transformer 1:100
THT, Minifit Jr. 3-pin, right angle
THT, SPOX, socket 9-pin,
right angle
THT, 2-pin, 1.5mm
THT, Minifit Jr. 2-pin, right
angle
Zener SOD-123 | BZT52C13-TPMSCT-ND | 621-BZT52C13-7-F
| | 621-BZT52C20-13-F
Zener SOD-123 | MM3Z5V1ST1G OSCT-ND | 621-DDZ5V1BSF-7
Zener SOD-123 | SZMMSZ5250BT1 G
Zener SOD-123 | 771-BZT52- C6V2X

Custom made components and accessories NTC 10K 3%, mini Lug with
connector

NTCALUG03A103
HC
| 594-NTCALUG03A10 3HC
1 TO-220 insulation cover Insulation cover for D12 --or tube | - | -

TO-247 insulation cover
or tube

Insulation cover for Q2, Q3, Q5, Q6
Heatsink clamp | Clamp with M3 for D12, Q2, Q3, Q5, Q6
Countersunk head screw M3x12mm | Clamp fixing for D12, Q2, Q3
Cheese head screw M3x5 | Clamp fixing for Q5, Q6, spacer sleeve fixing (2 of 4), top cover fixing
Countersunk head screw M3x5mm | L-profile thermnal bridge fixing
Custom QR Flyback | 85-265V AC, AUX+4 outputs, EF-20 bobbin, Feryster TI- EF20-6-7-2x12-8W

http://www.dokumentacja.feryster.pl/rysuj.php?lang=en&indeks=34866d690a7c2963cfec1b9c23eb8bca

# Qty Part name

72 2 470R

73 7 100K

74 1 150K

75 1 3K3

76 1 53100C

77 1 39-30-3035

78 1 22-05-7095

79 1 B2B-ZR
80 1 39-30-1020

81 1 BZT52C13

82 1 BZT52C20-DC

83 1 MMSZ5V1T1G

84 1 BZT52C6V2

1 NTCALUG03A103HC

1

4

5 Heatsink clamp

| M3X12/D965B 0,014 100

8 Cheese head screw M3x5

3

2

1 (http://www.dokumentacja.feryster.pl/rysuj.php?lang=en&indeks=34866d690a7c2963cfec1b9c23eb8bca)

Custom made components and accessories

TO-220 insulation cover
or tube
TO-247 insulation cover
or tube

Countersunk head screw
M3x12mm

Countersunk head screw
M3x5mm
Custom (http://www.dokumentacja.feryster.pl/rysuj.php?lang=en&indeks=34866d690a7c2963cfec1b9c23eb8bca) QR Flyback
Code Part Number Unit price MOQ € | Code / Part Number Unit price MOQ € | THT SMD

Best
Supplier

Lowest
unit price
€

Order
| | | | | | | | | Qty | Line Cost €
223-0376 CRG0805F470R | 0,021 50 | RC0805FR-07470R | 0,022 100 | 2 | Farnell | 0,019 € | 2 | 0,038
- | - | 7 | Farnell | 0,060 € | 7 | 0,422
223-0714 CRG0805F150K | 0,023 50 | SMD0805-150K-1% | 0,023 100 | 1 | Farnell | 0,010 € 10 | 0,097
223-0499 CRG0805F3K3 | 0,027 50 | SMD0805-3K3-1% | 0,022 100 | 1 | Farnell | 0,009 € | 1 | 0,009
715-7037 53100C | 1,480 | 1 | - | 1 | RS | 1,480 € | 1 | 1,480
670-5849 39-30-3035 | 0,536 | 5 | MX-5569-03A4 | 0,555 | 1 | 1 | RS | 0,536 € | 1 | 0,536
687-8118 22-05-7095 | 0,227 10 | - | 1 | RS | 0,227 € | 1 | 0,227
762-0800 | 0,520 | 5 | B2B-ZR | 0,214 | 5 | 1 | Farnell | 0,071 € | 1 | 0,071
484-1883 39-28-102 | 0,354 | 5 | MX-5566-02A | 0,104 | 5 | 1 | TME | 0,104 € | 1 | 0,104
822-2194 BZT52C13-7-F | 0,067 200 | BZT52C13-7-F | 0,022 25 | 1 | TME | 0,022 € | 1 | 0,022
822-2214 BZT52C20S-7-F | 0,093 100 | BZT52C20-DC | 0,052 10 | 1 | Farnell | 0,047 € | 1 | 0,047
544-9753 MMSZ5V1T1G | 0,109 50 | MMSZ5V1T1G | 0,023 25 | 1 | TME | 0,023 € | 1 | 0,023
751-3806 | 0,044 100 | BZT52C6V2-7-F | 0,022 25 | 1 | TME | 0,022 € | 1 | 0,022
23 | 197 | 48,41 €
179-3922 | 1,670 10 | - | Mouser | 1,550 € | 1 | 1,550
- | TO-220 | 0,374 | 1 | TME | 0,374 € | 1 | 0,374
| WSC-247 | 0,290 | 5 | TME | 0,290 € | 4 | 1,160
TRK-2 | 0,114 10 | TME | 0,114 € | 5 | 0,569
M3X5/D7985-A2 | 0,009 100 | TME | 0,009 € | 8 | 0,073
M3X5/D965 | 0,010 100 | TME | 0,010 € | 2 | 0,019
| | Feryster | 2,700 € | 1 | 2,700

B2B-ZR(LF)
(SN)

BZT52C6V2-7-F

NTCALUG03A1
03HC

MOQ | MOQ | MOQ
Qty | Part name | Package | Reference designator | Code | Part Number | Unit price €
Part Number | Unit price
€

Part Number Unit price
€
1 | TR3
1 | -
1 | -
1 37213150431 | - | 9516182 | 37213150431 | 1,070 | 1 | WK6321-ND | 0,770 | 1 | 576-3721315000 | 0,770 | 1
2 100n | 0603 | C5, C56 | 2522597 | 0,011 10 | 490-4774-1-ND | 0,029 100 | 0,007 100
1 N.C. | 1206 | C65, C68
1 4u7 | C80 | 2321209 | T491A475K006AT | 0,421 | 5 | 399-9717-1-ND | 0,259 | 10 | 0,184 10
1 N.C. | 0805 | C82
4 N.C. SOD-323 D11, D14, D20, D22
| ND | 652-RLB0812-471KL

1 T910W-50K THT, multiturn potentiometer P1

1 RLB0812-471KL | L3 | - | 0,136 | 1 | 0,238 | 1
4 N.C. | 0805 | R26, R38, R93, R94
1 N.C. | 1210 | R68
2 N.C. | 2512 | R41, R70
1 Test pin THT, test pin TP1
| OSCT-ND | 621-DDZ5V1BSF-7

1 SMAJ58A-TR DO-214AC ZD6

1 MMSZ5V1T1G | ZD4 | 1431291 | MMSZ5V1T1G | 0,158 | 5 | 0,140 | 1 | 0,170 | 1

Custom CF-DIC
transformer

Dual secondary transformer with VAC T60006-L2025-
W380 core, Feryster TI-RTN-27-28-2X14
PCB 2-layer 155 x 90
mm

ALLPCB.com

Metal enclosure | Custom made enclosure with two heatsink plates 3.15 A subminature TR5 fuse

Not installed / optional
C0603C104K4RAC
7081
| 80-C0603C104M4R

3 N.C. 1206 C63, C69, C70

1206, tant. | 80- T491A475K006A T
SMD; 470 uH | RLB0812-471KL-
Zener SOD-123 | MM3Z5V1ST1G

All prices are net prices (without VAT)

Please note that BOM does not contain ordering number for parts on reels or that which includes re-reeling fee (e.g. Farnell). Take also into account that total cost is higher because min. quantity (MOQ) for many parts is larger then what is needed for single unit.

All resistors are 1% 0805 if not otherwise specified.

# Qty Part name

1

1

1

1 37213150431

2 100n

3 N.C.
1 N.C.
1 4u7

1 N.C.
4 N.C.
1 RLB0812-471KL

1 T910W-50K
4 N.C.
1 N.C.
2 N.C.
1
1 MMSZ5V1T1G

1 SMAJ58A-TR

Custom CF-DIC
transformer

PCB 2-layer 155 x 90
mm
Metal enclosure

Not installed / optional

Test pin

Code Part Number Unit price MOQ € | Code / Part Number Unit price MOQ € | THT SMD

Best
Supplier

Lowest
unit price
€

Order
| | Qty | Line Cost €
Feryster | 5,600 € | 1 | 5,600
| | | | ALLPCB | 4,800 € | 1 | 4,800
| | | | | | 1 | 0,000
- | 37213150431 | 0,480 | 2 | TME | 0,480 € | 1 | 0,480
| | | | | | | 17,32 €
393-6952 | 0,069 25 | CL10B104KA8NNNC | 0,098 100 | 2 | Mouser | 0,007 € | 2 | 0,014
| | | | 3 | Farnell | 0,000 € | 3 | 0,000
| | | | 1 | Farnell | 0,000 € | 1 | 0,000
538-2335 | 0,337 10 | T491A475K006AT | 0,094 10 | 1 | TME | 0,094 € | 1 | 0,094
| | | | 1 | Farnell | 0,000 € | 1 | 0,000
| | | | 4 | Farnell | 0,000 € | | 0,000
- | COIL0608-0.47 | 0,174 10 | 1 | Digikey | 0,136 € | 1 | 0,136
T910W-50K | 0,252 | 5 | 1 | TME | 0,252 € | 0,000
| | | | 4 | Farnell | 0,000 € | 4 | 0,000
| | | | 1
| | | | 2 | Farnell | 0,000 € | 2 | 0,000
TEST-5 | 0,082 10 | 7 | TME | 0,082 € | 0,000
544-9753 MMSZ5V1T1G | 0,109 50 | MMSZ5V1T1G | 0,023 25 | 1 | TME | 0,023 € | 1 | 0,023
| | | | 1 | Farnell | 0,000 € | | 0,000

65,74 €

Varisom

VJ0603Y104KXJ
AT

T491A475K006
AT

Total

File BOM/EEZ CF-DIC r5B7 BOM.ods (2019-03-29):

 |  |  |  |  | Farnell / Element14 |  |  |  | Digi-Key |  |  | Mouser |  |  | RS Components |  |  |  | TME |  |  |  |  | Price calculation for 1 set
# | Qty | Part name | Package | Reference designator | Code | Part Number | Unit price € | MOQ | Part Number | Unit price € | MOQ | Part Number | Unit price € | MOQ | Code | Part Number | Unit price € | MOQ | Code / Part Number | Unit price € | MOQ | THT | SMD | Best Supplier | Lowest unit price € | Order Qty | Line Cost €
1 | 1 | GBU4K | THT, bridge rectifier 800V, 4A | B1 | 2889169 | GBU4K-E3/45 | 1,150 | 5 | GBU4K-BPMS-ND | 0,750 | 1 | 833-GBU4K-BP | 0,748 | 1 | 700-5437 | GBU4K-E3/45 | 1,448 | 5 | GBU4K | 0,355 | 3 | 1 |  | TME | 0,355 € | 1 | 0,355
2 | 5 | 3n3 | 0805 | C1, C9, C15, C17, C22 | 2896578 | VJ0805Y332KXACW1BC | 0,025 | 10 | 1276-1260-1-ND | 0,039 | 10 | 80-C0805C332K5R | 0,024 | 10 | 237-7009 | GRM216R71H332KA01D | 0,060 | 50 | VJ0805Y333KXACW1BC | 0,023 | 100 |  | 5 | TME | 0,023 € | 5 | 0,116
3 | 1 | 1n/1kV | 1210 or 1206 | C14 | 2812601 | 885342209006 | 0,580 | 5 | 732-12116-1-ND | 0,380 | 1 | 710-885342209006 | 0,357 | 1 | 500-2499 | C1210C102JDGACTU | 0,880 | 5 | 1210B102K102CT | 0,343 | 10 |  | 1 | TME | 0,343 € | 1 | 0,343
4 | 1 | UCY2G6R8MPD | THT, Ø10.5mm, RM 5 | C16 | 1831309 | 400BXC6R8MEFC10X16 | 0,868 | 1 | 493-13319-1-ND | 0,730 | 1 | 647-UCY2G6R8MPD | 0,629 | 1 | 739-4551 | UCA2G6R8MPD | 1,008 | 1 | UCY2G6R8MPD | 0,240 | 5 | 1 |  | TME | 0,240 € | 1 | 0,240
5 | 3 | 4u7 | 1206 | C19, C25, C67 | 1907356 | C3216X7R1E475K160AC | 0,240 | 5 | 1276-2970-1-ND | 0,199 | 10 | 963-EMK316B7475ML-T | 0,129 | 10 | 691-1221 | C1206C475K3RACTU | 0,232 | 25 | GCM31CR71E475KA55L | 0,381 | 10 |  | 3 | Mouser | 0,129 € | 3 | 0,387
6 | 2 | MKP-X2-220NR15/310 | THT, PP X2, 18 x 12 x 6 mm, RM 15 | C2, C3 | 2446244 | R463I322050L2K | 0,337 | 1 | 399-12681-ND | 0,600 | 1 | 80-R463I322050L2K | 0,600 | 1 | 875-2257 | R463I322050M2K | 0,372 | 25 | MKP-X2-220NR15/310 | 0,116 | 10 | 2 |  | TME | 0,116 € | 2 | 0,231
7 | 16 | 100n | 0603 | C21, C30, C32, C33, C37, C39, C40, C42, C45, C49, C53, C55, C66, C73, C75, C77 | 2522597 | C0603C104K4RAC7081 | 0,011 | 10 | 490-4774-1-ND | 0,029 | 100 | 80-C0603C104M4R | 0,007 | 100 | 393-6952 | VJ0603Y104KXJAT | 0,069 | 25 | CL10B104KA8NNNC | 0,098 | 100 |  | 16 | Mouser | 0,007 € | 16 | 0,112
8 | 1 | 470u/16V | THT; Ø8; RM3.5 | C23 | 2346502 | 16PK470MEFC8X11.5 | 0,206 | 5 | 493-1286-ND | 0,215 | 10 | 647-UVZ1C471MPD1TD | 0,194 | 10 | 845-4666 | UVZ1C471MPD | 0,215 | 25 | UVZ1C471MPD | 0,140 | 5 | 1 |  | TME | 0,140 € | 1 | 0,140
9 | 1 | 33n | 0805 | C26 | 1414688 | C0805C333K5RACTU | 0,051 | 10 | 1276-1796-1-ND | 0,068 | 10 | 77-VJ0805Y333JXAPBC | 0,020 | 50 | 652-0982 | VJ0805Y333KXAAT | 0,066 | 25 | CL21B333KBANNNC | 0,035 | 100 |  | 1 | Mouser | 0,020 € | 1 | 0,020
10 | 4 | 47p/200V | 0805, C0G | C27, C60, C72, C76 | 2812527 | 885342007006 | 0,081 | 10 | 885342007006 | 0,058 | 10 | 710-885342007006 | 0,055 | 10 | 535-2873 | VJ0805A470JXCAC | 0,039 | 50 | 0805N470J201CT | 0,031 | 100 |  | 4 | TME | 0,031 € | 4 | 0,123
11 | 1 | 2n2 | 0805 | C28 | 2896572 | VJ0805Y222KXACW1BC | 0,028 | 10 | 720-1604-1-ND | 0,063 | 10 | 77-VJ0805Y222KXBAC | 0,032 | 50 | 264-4359 | C0805C222K5RACTU | 0,031 | 25 | VJ0805Y222KXACW1BC | 0,020 | 100 |  | 1 | TME | 0,020 € | 1 | 0,020
12 | 4 | 10n | 0603 | C31, C38, C47, C52 | 2522596 | C0603C103K5RAC7081 | 0,042 | 10 | 399-1092-1-ND | 0,040 | 10 | 80-C0603C103M5R3121 | 0,031 | 10 | 264-4595 | C0603C103K5RACTU | 0,035 | 25 | C0603X103K5RACTU | 0,080 | 100 |  | 4 | Mouser | 0,031 € | 4 | 0,124
13 | 2 | UPH2G151MHD6 | THT, Ø18mm, RM 7.5 | C34, C35 | - |  |  |  | 493-16993-ND | 3,550 | 1 | 647-UPH2G151MHD | 3,550 | 1 | - |  |  |  | UPH2G151MHD6 | 1,950 | 1 | 2 |  | TME | 1,950 € | 2 | 3,900
14 | 2 | 100n/500V | 1812 | C36, C41 | 2676599 | C1812C104KBRACTU | 0,600 | 1 | 445-2300-1-ND | 0,453 | 10 | 810-C4532X7R2J104M | 0,408 | 10 | 371-6887 | C4532JB2J104K | 0,460 | 10 | 1812B104K501CT | 0,663 | 10 |  | 2 | Mouser | 0,408 € | 2 | 0,816
15 | 3 | CY1Y-4N7 | THT, Ceramic Y1, RM 10 | C4, C8, C20 | 2440246 | C951U472MVVDBA7317 | 0,772 | 1 | 399-9504-1-ND | 0,293 | 10 | 80-C941U472MYVDBAP | 0,215 | 10 | - |  |  |  | CY1Y-4N7 | 0,153 | 10 | 3 |  | TME | 0,153 € | 3 | 0,458
16 | 4 | 2n2/1kV | 1210 or 1206 | C44, C48, C64, C71 | 1855965 | MC1210B222K102CT | 0,496 | 5 | 490-12018-1-ND | 0,502 | 10 | 710-885342208019 | 0,121 | 10 | 723-6492 | GRM31BR73A222KW01L | 0,246 | 25 | 1206B222K102CT | 0,030 | 50 |  | 4 | TME | 0,030 € | 4 | 0,118
17 | 2 | 470p | 0805, C0G | C50, C51 | 1759217 | MC0805N471J500CT | 0,061 | 10 | 732-7837-1-ND | 0,059 | 10 | 710-885012007038 | 0,056 | 10 | 378-700 | 0805CG471J9BB | 0,040 | 25 | CC0805JRNPO9BN471 | 0,024 | 100 |  | 2 | TME | 0,024 € | 2 | 0,048
18 | 1 | UVZ1J222MHD | THT, Ø18 x 35.5mm, RM 7.5 | C58 | 1822575 | UVZ1J222MHD | 3,430 | 1 | 493-1360-ND | 2,370 | 1 | 647-UVZ1J222MHD | 2,490 | 1 | 862-1759 | UVZ1J222MHD | 2,440 | 1 | UVZ1J222MHD | 1,209 | 2 | 1 |  | TME | 1,209 € | 1 | 1,209
19 | 2 | 1u/100V | 1206 | C59, C62 | 2491179 | C1206C105K1RACTU | 0,374 | 5 | 1276-3094-1-ND | 0,240 | 10 | 963-HMK316B7105MLHT | 0,306 | 10 | 916-2977 | C3216X7R2A105K160AM | 0,290 | 20 | CL31B105KCHSNNE | 0,211 | 10 |  | 2 | TME | 0,211 € | 2 | 0,422
20 | 5 | EEEFK1V470P | Ø6.3 x 5.8 mm | C6, C11, C12, C18, C24 | 9695850 | EEEFK1V470P | 0,344 | 1 | PCE3842CT-ND | 0,312 | 10 | 667-EEE-FK1V470P | 0,238 | 10 | 537-0657 | EEEFK1V470P | 0,394 | 5 | EEEFK1V470P | 0,130 | 5 |  | 5 | TME | 0,130 € | 5 | 0,650
21 | 1 | HHXC630ARA330MHA0G | Ø8 x 10 mm | C61 | - |  |  |  | 565-4788-1-ND | 0,890 | 1 | HHXC630ARA330MHA0G | 0,770 | 1 | - |  |  |  | - |  |  |  | 1 | Mouser | 0,770 € | 1 | 0,770
22 | 1 | 100n/100V | 1206 | C63 | 2896560 | VJ0805Y104KXBTW1BC | 0,070 | 10 | 1276-6840-1-ND | 0,068 | 10 | 810-C2012X7R2A104K | 0,065 | 10 |  | C2012X7R2A104M125AA | 0,047 | 100 | CL21B104KCFSFNE | 0,071 | 10 |  | 1 | RS | 0,047 € | 1 | 0,047
23 | 9 | 1u | 0805 | C7, C10, C13, C29, C43, C46, C54, C57, C81 | 2896566 | VJ0805Y105KXXTW1BC | 0,084 | 5 | 587-1283-1-ND | 0,090 | 10 | 603-CC805MKX7R7BB105 | 0,062 | 10 | 451-5770 | C0805C105K4RACTU | 0,028 | 25 | CL21B105KOFNNNE | 0,010 | 100 |  | 9 | TME | 0,010 € | 9 | 0,094
24 | 1 | 4n7 | 0804 | C74
25 | 1 | 100p | 0805, C0G | C78 | 2896466 | VJ0805A101JXACW1BC | 0,041 | 10 | 399-1121-1-ND | 0,061 | 10 | 80-C0805C101J5G | 0,022 | 10 | 461-3997 | CC0805JRNP09BN101 | 0,017 | 25 | VJ0805A101JXACW1BC | 0,024 | 100 |  | 1 | RS | 0,017 € | 1 | 0,017
26 | 1 | 1n | 0805, C0G | C79 | 2896470 | VJ0805A102JXACW1BC | 0,044 | 10 | 732-7858-1-ND | 0,055 | 10 | 710-885012007040 | 0,052 | 10 | 723-6408 | GRM2195C1H102JA01D | 0,031 | 100 | CL21C102JBCNNNC | 0,026 | 100 |  | 1 | TME | 0,026 € | 1 | 0,026
27 | 6 | SS110B | SMB | D1, D2, D3, D5, D6, D7 | 1861422 | SS110B | 0,097 | 5 | SS110-TPCT-ND | 0,350 | 1 | 833-SS110FL-TP | 0,323 | 1 | 743-5992 | SS110 R3 | 0,154 | 25 | SS110-JGD | 0,053 | 5 |  | 6 | TME | 0,053 € | 6 | 0,319
28 | 3 | C3D02065E | TO-252 (DPAK) | D10, D16, D19 | - |  |  |  | C3D02065E-ND | 0,860 | 1 | 941-C3D02065E | 0,859 | 1 | 915-8846 | C3D02065E | 0,869 | 10 | C3D02065 | 0,620 | 3 |  | 3 | TME | 0,620 € | 3 | 1,860
29 | 1 | C3D03060A | THT, TO-220 | D12 | - |  |  |  | C3D03060A-ND | 1,250 | 1 | 941-C3D03060A | 1,240 | 1 | 702-7447 | C3D03060A | 1,260 | 1 | C3D03060A | 0,850 | 2 | 1 |  | TME | 0,850 € | 1 | 0,850
30 | 1 | 1N5819HW-7-F | SOD-323 | D13 | 2306459 | 1N5819HW-7-F | 0,183 | 10 | 1N5819HW-FDICT-ND | 0,310 | 10 | 621-1N5819HW-F | 0,281 | 10 | 708-2197 | 1N5819HW-7-F | 0,252 | 25 | 1N5819HW-7-F | 0,086 | 10 |  | 1 | TME | 0,086 € | 1 | 0,086
31 | 2 | US1K-DIO | DO-214AA | D4, D15 | 2306342 | US1K-13-F | 0,146 | 1 | US1K-FDICT-ND | 0,340 | 1 | 621-US1K-F | 0,366 | 1 | 751-5130 | US1K-13-F | 0,106 | 25 | US1K-DIO | 0,067 | 10 |  | 2 | TME | 0,067 € | 2 | 0,135
32 | 9 | BAS316 | SOD-323 | D8, D9, D17, D18, D21, D23, D24, D25, D26 | 8734275 | BAS316,115 | 0,193 | 5 | 1727-7370-1-ND | 0,120 | 1 | 771-BAS316-T/R | 0,179 | 1 | 397-2914 | BAS316,115 | 0,122 | 50 | BAS316,115 | 0,026 | 25 |  | 9 | TME | 0,026 € | 9 | 0,238
33 | 1 | 0031.7601 | THT, TR5 fuse holder | F1 | 4591999 | 0031.7601 | 0,628 | 1 | 486-1244-ND | 0,830 | 1 | 693-0031.7601 | 0,840 | 1 | 866-4790 | 0031.7601 | 0,442 | 50 | 0031.7601 | 0,281 | 5 | 1 |  | TME | 0,281 € | 1 | 0,281
34 | 1 | VIPer35L | SOIC-16 | IC1 | 2612169 | VIPER35LD | 1,130 | 1 | 497-16075-5-ND | 1,040 | 1 | 511-VIPER35LD | 1,040 | 1 | 124-1146 | VIPER35LDTR | 1,544 | 5 | - |  |  |  | 1 | Digikey | 1,040 € | 1 | 1,040
35 | 1 | SI8233BB-D-IS1 | SOIC-16 | IC2 | 2423138 | SI8233BB-D-IS1 | 2,460 | 1 | 336-3066-ND | 2,050 | 1 | 634-SI8233BB-D-IS1 | 2,410 |  | - |  |  |  | - |  |  |  | 1 | Digikey | 2,050 € | 1 | 2,050
36 | 1 | LM5041B | TSSOP-16 | IC3 | - |  |  |  | LM5041BMTC/NOPB-ND | 3,110 | 1 | 926-LM5041BMTC/NOPB | 3,090 | 1 | - |  |  |  | - |  |  |  | 1 | Mouser | 3,090 € | 1 | 3,090
37 | 2 | LM258D | SOIC-8 | IC4, IC6 | 2323288 | LM258D | 0,274 | 5 | 296-14591-1-ND | 0,271 | 10 | 595-LM258DR | 0,248 | 10 | 660-9555 | LM258DGKR | 0,244 | 10 | LM258D-ST | 0,114 | 5 |  | 2 | TME | 0,114 € | 2 | 0,227
38 | 1 | IR11688STRPBF | SOIC-8 | IC5 | 2780950 | IR11688STRPBF | 1,520 | 1 | IR11688STRPBFCT-ND | 1,680 | 1 | 942-IR11688STRPBF | 1,550 | 1 | - |  |  |  | IR11688STRPBF | 1,580 | 1 |  | 1 | Farnell | 1,520 € | 1 | 1,520
39 | 1 | TL103W | SOIC-8 | IC7 | 1755223 | TL103WID | 0,665 | 1 | 296-18862-1-ND | 0,610 | 1 | 595-TL103WID | 0,706 | 1 | 809-5334 | TL103WID | 0,692 | 5 | - |  |  |  | 1 | Digikey | 0,610 € | 1 | 0,610
40 | 1 | RN214-2.5-02-3M3 | THT, Common Mode Choke | L1 | - |  |  |  | 817-2186-ND | 1,550 | 1 | 631-RN214-2.5-02-3M3 | 1,460 | 1 | 133-6257 | RN214-2.5-02-3M3 | 1,742 | 1 | - |  |  | 1 |  | Mouser | 1,460 € | 1 | 1,460
41 | 4 | DLG-0403-180 | 0403 inductor | L2, L4, L5, L6 | SDR0403-180ML | SDR0403-180M | 0,404 | 5 | SDR0403-180MLCT-ND | 0,424 | 10 | 652-SDR0403-180ML | 0,272 | 10 | 798-0938 | SDR0403-180ML | 0,336 |  | DLG-0403-180 | 0,129 | 10 |  | 4 | TME | 0,129 € | 4 | 0,514
42 | 2 | 60B684C | Murata power inductor 6000B | L7, L8 | 2290311 | 60B684C | 5,140 | 1 | 811-2466-ND | 2,540 | 1 | 580-60B684C | 2,520 | 1 | 749-6427 | 60B684C | 2,650 | 1 | - |  |  |  | 2 | Mouser | 2,520 € | 2 | 5,040
43 | 1 | 3u3/5A | Vishay power inductor | L9 | 1741325 | IHLP2020CZER3R3M11 | 1,940 | 5 | 541-1237-1-ND | 2,040 | 1 | 70-IHLP2020CZER3R3M1 | 2,140 | 1 | - |  |  |  | HPI0630-3R3 | 0,335 | 1 |  | 1 | TME | 0,335 € | 1 | 0,335
44 | 1 | WP934MD/LYLID | THT, dual 3 mm LED | LED1 | - |  |  |  | 754-2008-ND | 0,980 | 1 | 604-WP934MDLYLID | 0,800 | 1 | - |  |  |  | - |  |  | 1 |  | Mouser | 0,800 € | 1 | 0,800
45 | 3 | TLP291-GB.SE-T | SOIC-4 | OK1, OK2, OK3 | 2524307 | TLP291(GB,SE | 0,196 | 1 | - |  |  | - |  |  | 144-5264 | TLP291(GB-TP,SE(T | 0,116 | 50 | TLP291-GB.SE-T | 0,126 | 5 |  | 3 | RS | 0,116 € | 3 | 0,348
46 | 1 | MMBT5551 | SOT-23 | Q1 | 1459109 | MMBT5551LT1G | 0,154 | 5 | MMBT5551LT1GOSCT-ND | 0,180 | 1 | 863-MMBT5551LT1G | 0,170 | 1 | 545-0400 | MMBT5551LT1G | 0,146 | 10 | MMBT5551 | 0,024 | 25 |  | 1 | TME | 0,024 € | 1 | 0,024
47 | 2 | C3M0280090D | THT, TO-247 | Q2, Q3 | 2630827 | C3M0280090D | 3,710 | 1 | C3M0280090D-ND | 3,110 | 1 | 941-C3M0280090D | 2,950 | 1 | 915-8842 | C3M0280090D | 3,100 | 2 | - |  |  | 2 |  | Mouser | 2,950 € | 2 | 5,900
48 | 1 | NYC0102BLT1G | SOT-23 | Q4 | 2533159 | NYC0102BLT1G | 0,360 | 5 | NYC0102BLT1GOSCT-ND | 0,430 | 1 | 863-NYC0102BLT1G | 0,472 | 1 | 808-3993 | NYC0102BLT1G | 0,268 | 50 | NYC0102BLT1G-LF | 0,166 | 3 |  | 1 | TME | 0,166 € | 1 | 0,166
49 | 2 | IRFP4332PBF | THT, TO-247 | Q5, Q6 | 1436966 | IRFP4332PBF | 3,820 | 1 | IRFP4332PBF-ND | 4,280 | 1 | 942-IRFP4332PBF | 3,670 | 1 | - |  |  |  | IRFP4332PBF | 1,790 | 1 | 2 |  | TME | 1,790 € | 2 | 3,580
50 | 2 | Option #1: FDD86250-F085 | TO-252 (DPAK) | Q7, Q8 | 2895710 | FDD86250-F085 | 1,510 | 5 | FDD86250-F085OSCT-ND | 1,590 | 1 | 863-FDD86250-F085 | 1,280 | 1 | - |  |  |  | - |  |  |  | 2 | Mouser | 1,280 € | 2 | 2,560
 | 0 | Option #2: SUD80460E-GE | TO-252 (DPAK) | Q7, Q8 | 2708325 | SUD80460E-GE3 | 1,010 | 5 | SUD80460E-GE3-ND | 0,970 | 1 | 78-SUD80460E-GE3 | 0,840 | 1 | - |  |  |  | - |  |  |  |  | Mouser | 0,840 € | 0 | 0,000
51 | 6 | 120R | 0805 | R1, R5, R10, R12, R15, R66 | 2447561 | MCWR08X1200FTL | 0,009 | 10 | RMCF0805FT120RCT-ND | 0,020 | 10 | 71-CRCW0805120RFKEAC | 0,037 | 10 | 223-0304 | CRG0805F120R | 0,035 | 50 | SMD0805-120R-1% | 0,022 | 100 |  | 6 | Farnell | 0,009 € | 6 | 0,056
52 | 3 | 30K | 0805 | R16, R32, R62 | 2303701 | ERJ6ENF3002V | 0,058 | 10 | P30.0KCCT-ND | 0,085 | 10 | 603-RC0805FR-0730KL | 0,014 | 10 | - |  |  |  | SMD0805-30K-1% | 0,022 | 100 |  | 3 | Mouser | 0,014 € | 3 | 0,042
53 | 14 | 1K | 0805 | R17, R21, R40, R42, R56, R61, R64, R65, R69, R75, R82, R83, R85, R89 | 1099800 | WCR0805-1K0FI | 0,019 | 10 | RC0805FR-071KL | 0,039 | 10 | 603-RC0805FR-071KL | 0,015 | 10 | 223-0427 | CRG0805F1K0 | 0,017 | 50 | RC0805FR-071K | 0,022 | 100 |  | 14 | Mouser | 0,015 € | 14 | 0,210
54 | 2 | 470K | 1206, High Voltage | R2, R3 | 2826395 | MCHVR06JTEV4703 | 0,060 | 10 | RHM470KPCT-ND | 0,115 | 10 | 603-RV1206FR-07470KL | 0,184 | 10 | - |  |  |  | - |  |  |  | 2 | Farnell | 0,060 € | 2 | 0,121
55 | 2 | 47K | 0805 | R20, R37 | 2447664 | MCWR08X4702FTL | 0,009 | 10 | RHM47KKCT-ND | 0,036 | 10 | 603-RC0805FR-0747KL | 0,014 | 10 | 679-1434 | CRCW080547K0FKEA | 0,036 | 50 | RC0805FR-0747K | 0,022 | 100 |  | 2 | Farnell | 0,009 € | 2 | 0,019
56 | 11 | 10R | 0805 | R23, R25, R31, R34, R35, R43, R47, R53, R71, R72, R74 | 9236643 | RC1206FR-0710RL | 0,050 | 10 | 311-10.0CRCT-ND | 0,071 | 10 | 603-RC1206FR-0710RL | 0,034 | 10 | 740-9085 | CR1206-FX-10R0ELF | 0,036 | 50 | CRCW120610R0FKTABC | 0,031 | 100 |  | 11 | TME | 0,031 € | 11 | 0,341
57 | 4 | 10K | 0805 | R24, R63, R77, R81 | 9237755 | RC0805FR-0710KL | 0,022 | 10 | 311-10.0KCRCT-ND | 0,039 | 10 | 603-RC0805FR-0710KL | 0,014 | 10 | 125-1189 | CRG0805F10K | 0,002 | 100 | RC0805FR-0710K | 0,022 | 100 |  | 4 | RS | 0,002 € | 4 | 0,008
58 | 2 | 100R | 0805 | R28, R29 | 2447552 | MCWR08X1000FTL | 0,094 | 10 | 311-100CRCT-ND | 0,039 | 10 | RC0805FR-07100RL | 0,014 | 10 | 679-0807 | CRCW0805100RFKEA | 0,043 | 50 | SMD0805-100R-1% | 0,022 | 100 |  | 2 | Mouser | 0,014 € | 2 | 0,028
59 | 3 | 22R/2-3W | 2512 | R39, R67, R76 | 2116456 | RLP73K3AR22JTE | 0,380 | 5 | A126461CT-ND | 0,409 | 10 | 279-352122RFT | 0,122 | 10 | 224-0187 | 352022RJT | 0,128 | 10 | WF25P-22R-5% | 0,072 | 50 |  | 3 | TME | 0,072 € | 3 | 0,215
60 | 6 | 86K6 | 0805 | R30, R45, R46, R60, R73, R86 | 2303750RL | ERJ6ENF8662V | 0,058 | 10 | 311-86.6KCRCT-ND | 0,036 | 10 | 603-RT0805FRE0786K6L | 0,056 | 10 | - |  |  |  | CRCW080586K6FKTABC | 0,025 | 100 |  | 6 | TME | 0,025 € | 6 | 0,150
61 | 2 | 1R | 0805 | R33, R38 | 2447598 | MCWR08W1R00FTL | 0,012 | 10 | 311-1.00CRCT-ND | 0,071 | 10 | 603-RC0805FR-131RL | 0,020 | 10 | 740-9151 | CR0805-J/-1R0ELF | 0,027 | 50 | SMD0805-1R-1% | 0,032 | 100 |  | 2 | Farnell | 0,012 € | 2 | 0,023
62 | 4 | 1K8 | 0805 | R4, R18, R84, R87 | 2447595 | MCWR08X1801FTL | 0,009 | 10 | A129752CT-ND | 0,028 | 10 | 652-CR0805JW-182ELF | 0,008 | 10 | 223-0461 | CRG0805F1K8 | 0,022 | 50 | SMD0805-1K8-1% | 0,022 | 100 |  | 4 | Mouser | 0,008 € | 4 | 0,032
63 | 1 | 8K2 | 0805 | R44 | 2447732 | MCWR08X8201FTL | 0,010 | 10 | 311-8.20KCRCT-ND | 0,037 | 10 | 652-CR0805FX-8201ELF | 0,013 | 10 | 223-0556 | CRG0805F8K2 | 0,021 | 50 | SMD0805-8K2-1% | 0,014 | 100 |  | 1 | Farnell | 0,010 € | 1 | 0,010
64 | 2 | 47R/2-3W | 2512 | R48, R54 |  |  |  |  |  |  |  |  |  |  |  |  |  |  |  |  |  |  | 2 | Farnell | 0,000 € | 2 | 0,000
65 | 1 | 15K | 0805 | R49 | 1099808 | WCR0805-15KFI | 0,019 | 10 | A126341CT-ND | 0,041 | 10 | 71-CRCW080515K0FKEBC | 0,013 | 10 | 223-0584 | CRG0805F15K | 0,023 | 50 | SMD0805-15K | 0,013 | 100 |  | 1 | Mouser | 0,013 € | 1 | 0,013
66 | 1 | 68K | 0805 | R51 | 2861918 | CRGCQ0805J68K | 0,010 | 10 | A126382CT-ND | 0,045 | 10 | 652-CR0805FX-6802ELF | 0,013 | 10 | 223-0663 | CRG0805F68K | 0,027 | 50 | SMD0805-68K-1% | 0,014 | 100 |  | 1 | Farnell | 0,010 € | 1 | 0,010
67 | 2 | 220R | 0805 | R52, R92 | 1099795 | WCR0805-220RFI | 0,019 | 10 | RMCF0805FT220RCT-ND | 0,020 | 10 | 603-RC0805FR-13220RL | 0,020 | 10 | 223-0332 | CRG0805F220R | 0,018 | 50 | SMD0805-220R-1% | 0,022 | 100 |  | 2 | RS | 0,018 € | 2 | 0,036
68 | 1 | 6R2 | 0805 | R55 | 2447714 | MCWR08W6R20FTL | 0,012 | 10 | 311-6.20CRCT-ND | 0,070 | 10 | 603-RC0805FR-076R2L | 0,020 | 10 | - |  |  |  | RC0805JR-076R2 | 0,034 | 100 |  | 1 | Farnell | 0,012 € | 1 | 0,012
69 | 2 | 7K5 | 0805 | R57, R91 | 2447722 | MCWR08X7501FTL | 0,010 | 10 | 311-7.50KCRCT-ND | 0,040 | 10 | 667-ERJ-6ENF7501V | 0,040 | 10 | 679-1686 | CRCW08057K50FKEA | 0,038 | 50 | SMD0805-7K5-1% | 0,023 | 100 |  | 2 | Farnell | 0,010 € | 10 | 0,097
70 | 2 | 5K6 | 0805 | R59, R90 | 2447693 | MCWR08X5601FTL | 0,010 | 10 | RC0805FR-075K6L | 0,040 |  | RC0805FR-075K6L | 0,027 |  | 679-1572 | CRCW08055K60FKEA | 0,029 | 50 | SMD0805-5K6-1% | 0,023 | 100 |  | 2 | Farnell | 0,010 € | 2 | 0,019
71 | 5 | 4K7 | 0805 | R6, R7, R19, R50, R58 | 2861530 | CRGCQ0805F4K7 | 0,012 | 10 | 311-4.70KCRCT-ND | 0,040 | 10 | 603-RC0805FR-074K7L | 0,027 | 10 | 223-0528 | CRG0805F4K7 | 0,023 | 50 | SMD0805-4K7-1% | 0,023 | 100 |  | 5 | Farnell | 0,012 € | 5 | 0,059
72 | 2 | 470R | 0805 | R78, R79 | 1099798 | WCR0805-470RFI | 0,019 | 10 | 311-470CRCT-ND | 0,039 | 10 | 71-CRCW0805470RFKEB | 0,041 | 10 | 223-0376 | CRG0805F470R | 0,021 | 50 | RC0805FR-07470R | 0,022 | 100 |  | 2 | Farnell | 0,019 € | 2 | 0,038
73 | 7 | 100K | 1206, High Voltage | R8, R9, R11, R13, R14, R22, R27 | 2826380 | MCHVR06JTEV1003 | 0,060 | 10 | RHM100KPCT-ND | 0,115 | 10 | 603-RV1206FR-07100KL | 0,217 | 10 | - |  |  |  | - |  |  |  | 7 | Farnell | 0,060 € | 7 | 0,422
74 | 1 | 150K | 0805 | R80 | 2447573 | MCWR08X1503FTL | 0,010 | 10 | 311-150KCRCT-ND | 0,037 | 10 | 667-ERJ-6ENF1503V | 0,040 | 10 | 223-0714 | CRG0805F150K | 0,023 | 50 | SMD0805-150K-1% | 0,023 | 100 |  | 1 | Farnell | 0,010 € | 10 | 0,097
75 | 1 | 3K3 | 0805 | R88 | 2447651 | MCWR08X3301FTL | 0,009 | 10 | 311-3.30KCRCT-ND | 0,039 | 10 | 652-CR0805-FX3301GLF | 0,013 | 10 | 223-0499 | CRG0805F3K3 | 0,027 | 50 | SMD0805-3K3-1% | 0,022 | 100 |  | 1 | Farnell | 0,009 € | 1 | 0,009
76 | 1 | 53100C | Murata 5300 current transformer 1:100 | TR2 | 2840104 | 53100C | 2,380 | 1 | 811-1193-1-ND | 1,500 | 1 | 580-53100C | 1,500 | 1 | 715-7037 | 53100C | 1,480 | 1 | - |  |  |  | 1 | RS | 1,480 € | 1 | 1,480
77 | 1 | 39-30-3035 | THT, Minifit Jr. 3-pin, right angle | X1 | 9963545 | 39303035 | 0,572 | 10 | WM18446-ND | 0,670 | 1 | 538-39-30-3035 | 0,672 | 1 | 670-5849 | 39-30-3035 | 0,536 | 5 | MX-5569-03A4 | 0,555 | 1 | 1 |  | RS | 0,536 € | 1 | 0,536
78 | 1 | 22-05-7095 | THT, SPOX, socket 9-pin, right angle | X2 | - |  |  |  | WM18907-ND | 1,090 | 1 | 538-22-05-7095 | 0,781 | 10 | 687-8118 | 22-05-7095 | 0,227 | 10 | - |  |  | 1 |  | RS | 0,227 € | 1 | 0,227
79 | 1 | B2B-ZR | THT, 2-pin, 1.5mm | X3 | 9491775 | B2B-ZR(LF)(SN) | 0,071 | 100 | 455-1657-ND | 0,150 | 1 | - |  |  | 762-0800 | B2B-ZR(LF)(SN) | 0,520 | 5 | B2B-ZR | 0,214 | 5 | 1 |  | Farnell | 0,071 € | 1 | 0,071
80 | 1 | 39-30-1020 | THT, Minifit Jr. 2-pin, right angle | X4 | 9732080 | 39-28-1023 | 0,367 | 1 | WM3800-ND | 0,530 | 1 | 538-39-28-1023 | 0,530 | 1 | 484-1883 | 39-28-102 | 0,354 | 5 | MX-5566-02A | 0,104 | 5 | 1 |  | TME | 0,104 € | 1 | 0,104
81 | 1 | BZT52C13 | Zener SOD-123 | ZD1 | 2306055 | BZT52C13-7-F | 0,106 | 10 | BZT52C13-TPMSCT-ND | 0,178 | 10 | 621-BZT52C13-7-F | 0,118 | 10 | 822-2194 | BZT52C13-7-F | 0,067 | 200 | BZT52C13-7-F | 0,022 | 25 |  | 1 | TME | 0,022 € | 1 | 0,022
82 | 1 | BZT52C20-DC | Zener SOD-123 | ZD2 | 2824935 | SZMMSZ5250BT1G | 0,047 | 5 | 1727-8128-1-ND | 0,180 | 1 | 621-BZT52C20-13-F | 0,170 | 1 | 822-2214 | BZT52C20S-7-F | 0,093 | 100 | BZT52C20-DC | 0,052 | 10 |  | 1 | Farnell | 0,047 € | 1 | 0,047
83 | 1 | MMSZ5V1T1G | Zener SOD-123 | ZD3 | 1431291 | MMSZ5V1T1G | 0,158 | 5 | MM3Z5V1ST1GOSCT-ND | 0,140 | 1 | 621-DDZ5V1BSF-7 | 0,170 | 1 | 544-9753 | MMSZ5V1T1G | 0,109 | 50 | MMSZ5V1T1G | 0,023 | 25 |  | 1 | TME | 0,023 € | 1 | 0,023
84 | 1 | BZT52C6V2 | Zener SOD-123 | ZD4 | 1902438 | BZT52C6V2 | 0,106 | 25 | 1727-7698-1-ND | 0,166 | 10 | 771-BZT52-C6V2X | 0,151 | 10 | 751-3806 | BZT52C6V2-7-F | 0,044 | 100 | BZT52C6V2-7-F | 0,022 | 25 |  | 1 | TME | 0,022 € | 1 | 0,022
 |  |  |  |  |  |  |  |  |  |  |  |  |  |  |  |  |  |  |  |  |  | 23 | 197 |  |  |  | 48,41 €
 |  | Custom made components and accessories
 | 1 | NTCALUG03A103HC | NTC 10K 3%, mini Lug with connector | NTC1 | 2885270 | NTCALUG03A103HC | 1,960 | 1 | BC2382-ND | 2,340 | 1 | 594-NTCALUG03A103HC | 1,550 | 1 | 179-3922 | NTCALUG03A103HC | 1,670 | 10 | - |  |  |  |  | Mouser | 1,550 € | 1 | 1,550
 | 1 | TO-220 insulation cover or tube | Insulation cover for D12 | - | - |  |  |  | - |  |  | - |  |  | - |  |  |  | TO-220 | 0,374 | 1 |  |  | TME | 0,374 € | 1 | 0,374
 | 4 | TO-247 insulation cover or tube | Insulation cover for Q2, Q3, Q5, Q6 | - |  |  |  |  |  |  |  |  |  |  |  |  |  |  | WSC-247 | 0,290 | 5 |  |  | TME | 0,290 € | 4 | 1,160
 | 5 | Heatsink clamp | Clamp with M3 for D12, Q2, Q3, Q5, Q6 | - |  |  |  |  |  |  |  |  |  |  |  |  |  |  | TRK-2 | 0,114 | 10 |  |  | TME | 0,114 € | 5 | 0,569
 | 3 | Countersunk head screw M3x12mm | Clamp fixing for D12, Q2, Q3 |  |  |  |  |  |  |  |  |  |  |  |  |  |  |  | M3X12/D965B | 0,014 | 100
 | 8 | Cheese head screw M3x5 | Clamp fixing for Q5, Q6, spacer sleeve fixing (2 of 4), top cover fixing | - |  |  |  |  |  |  |  |  |  |  |  |  |  |  | M3X5/D7985-A2 | 0,009 | 100 |  |  | TME | 0,009 € | 8 | 0,073
 | 2 | Countersunk head screw M3x5mm | L-profile thermnal bridge fixing | - |  |  |  |  |  |  |  |  |  |  |  |  |  |  | M3X5/D965 | 0,010 | 100 |  |  | TME | 0,010 € | 2 | 0,019
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

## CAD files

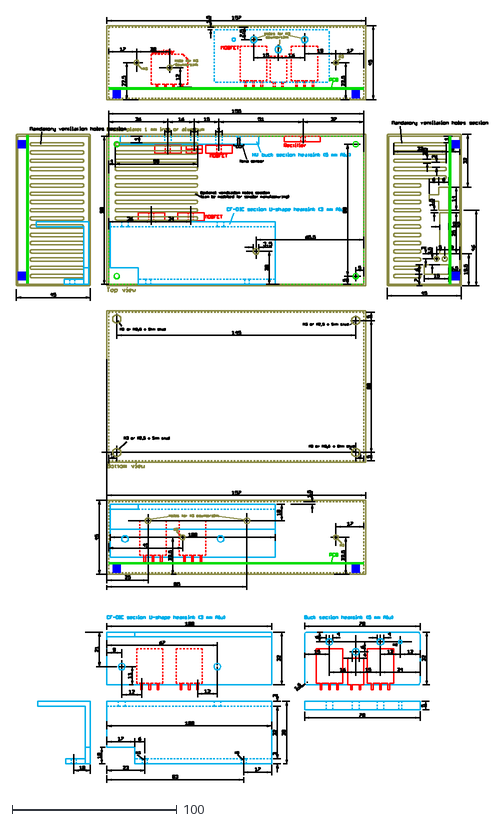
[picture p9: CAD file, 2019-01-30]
Mechanical/CF-DIC enclosure r5B6.dxf
286.1 x 465.1

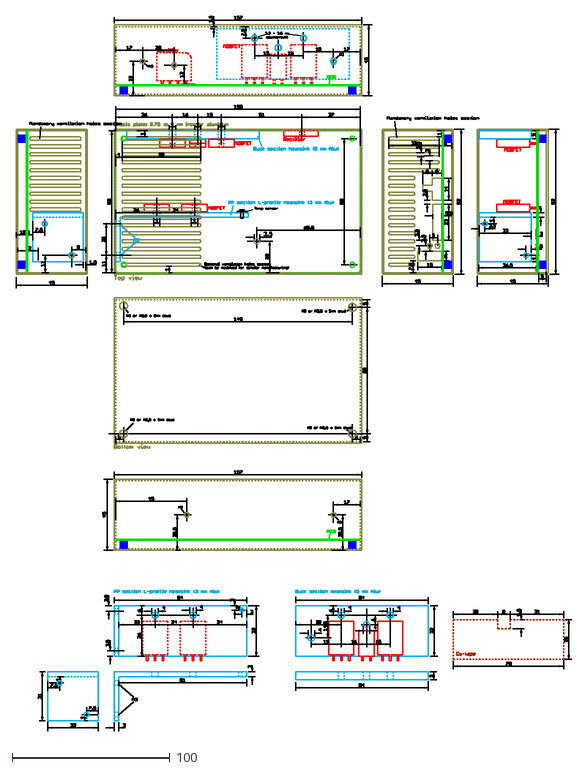
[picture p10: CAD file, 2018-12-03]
Mechanical/CF-DIC enclosure r5B5.dxf
352.0 x 453.1

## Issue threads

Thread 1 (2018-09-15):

Layout Discussion

Rerouter, 2018-09-15:
For the dual inductor section, it seems like you would have a shorter routing by rotating both transformers, was there a reason behind the current orientation?

Equally it appears the diode / capacitor for both inductors could be placed on a far shorter loop.

I have to admit at this point Its hard for me to visualize all the current loops for this converter, just working on your footnote to keep the trace lengths even and as close as possible.
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

prasimix, 2018-09-15:
You're right. Rotating power inductors make sense, indeed. I'll try to rearrange that section and commit a new version soon.

prasimix, 2018-12-03:
PCB layout is completely redesigned in r5B4 that works as intended, therefore this issue can be closed.

Closed 2018-12-03.

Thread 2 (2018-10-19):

OVP on primary side

prasimix, 2018-10-19:
Add fast OVP circuit by monitoring Vclamp voltage on the primary side to avoid output voltage rise above max. value in case of failure in tracker circuit or if control signal (U_MON) rise above 2.5 V. Reuse a half of LM258 (IC4) currently used for NTC signal buffering and add voltage divider on FB (e.g. 750R + 130K).

prasimix, 2018-10-22:
Fixed on r5B1

Closed 2018-10-22.

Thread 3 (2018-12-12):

Move ULVO capacitor before 1K hysteresis resistor

prasimix, 2018-12-12:
External capactior directly connected to ULVO pin affect softstart sequence. Therefore it has to be moved before 1K hysteresis resistor.

prasimix, 2019-01-05:
Fixed

Closed 2019-01-05.

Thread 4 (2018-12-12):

Replace Push-Pull SiC MOSFETs with Si type

prasimix, 2018-12-12:
Push-Pull MOSFETs can be replaced with cheaper Si type for lower cost.

prasimix, 2019-02-27:
Fixed

Closed 2019-02-27.

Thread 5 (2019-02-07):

Add VD inputs filtering

prasimix, 2019-02-07:
VD1 i VD2 inputs require filtering to avoid false triggering caused by ringing.

prasimix, 2019-02-27:
Fixed

Closed 2019-02-27.

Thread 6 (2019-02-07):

PCB routing optimization for SR secion

prasimix, 2019-02-07:
PCB layout should be optimized for SR (sync rec.) section taking into consideration manufacturers guidelines with special attention to:
* power decoupling
* MOT resistor position and ground connection
* gate drive loops
* source outputs loop
* VS and GND connection
* VD inputs RC filter placement and GND connection

prasimix, 2019-02-27:
Fixed

Closed 2019-02-27.

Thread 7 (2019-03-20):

On-board sub-miniature fuse

prasimix, 2019-03-20:
For additional safety an on-board fuse (e.g. TR5 size) has to be added.

prasimix, 2019-03-22:
Fixed

Closed 2019-03-22.

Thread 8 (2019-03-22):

CT input filtering adjustment and duty limitation

prasimix, 2019-03-22:
CT input filter is too big and introduce unacceptably huge delay. Therefore a control loop was not work properly and for higher Vin (230 Vac) duty was different then for lower Vin and active duty limiter is added to fix that problem.

prasimix, 2019-03-22:
Fixed

Closed 2019-03-22.

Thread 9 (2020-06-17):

Wrong package for item no. 22 (C63)

solariiknight, 2020-06-17:
In the BOM document, the package size stated is 1206, but you have ordered 0805 component size and the component size on the PCB is 0805 also. Please check.

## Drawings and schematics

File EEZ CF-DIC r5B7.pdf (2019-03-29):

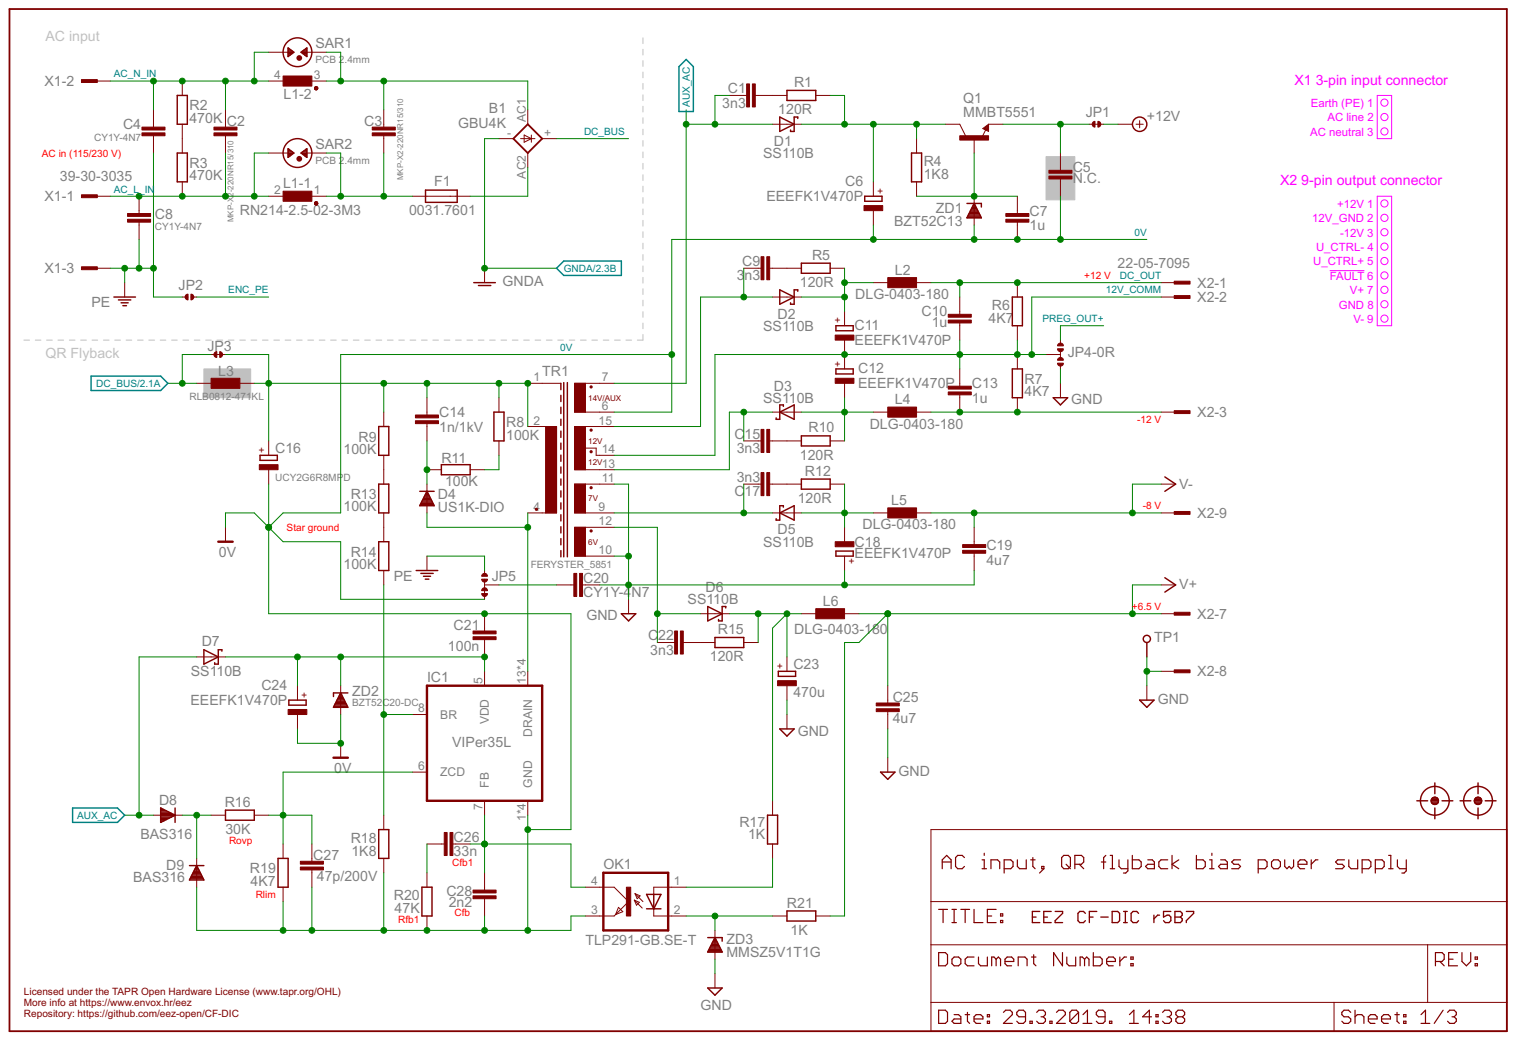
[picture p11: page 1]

Earth (PE) 1 AC line 2 AC neutral 3 X1 3-pin input connector

Licensed under the TAPR Open Hardware License (www.tapr.org/OHL) Repository: https://github.com/eez-open/CF-DIC More info at https://www.envox.hr/eez

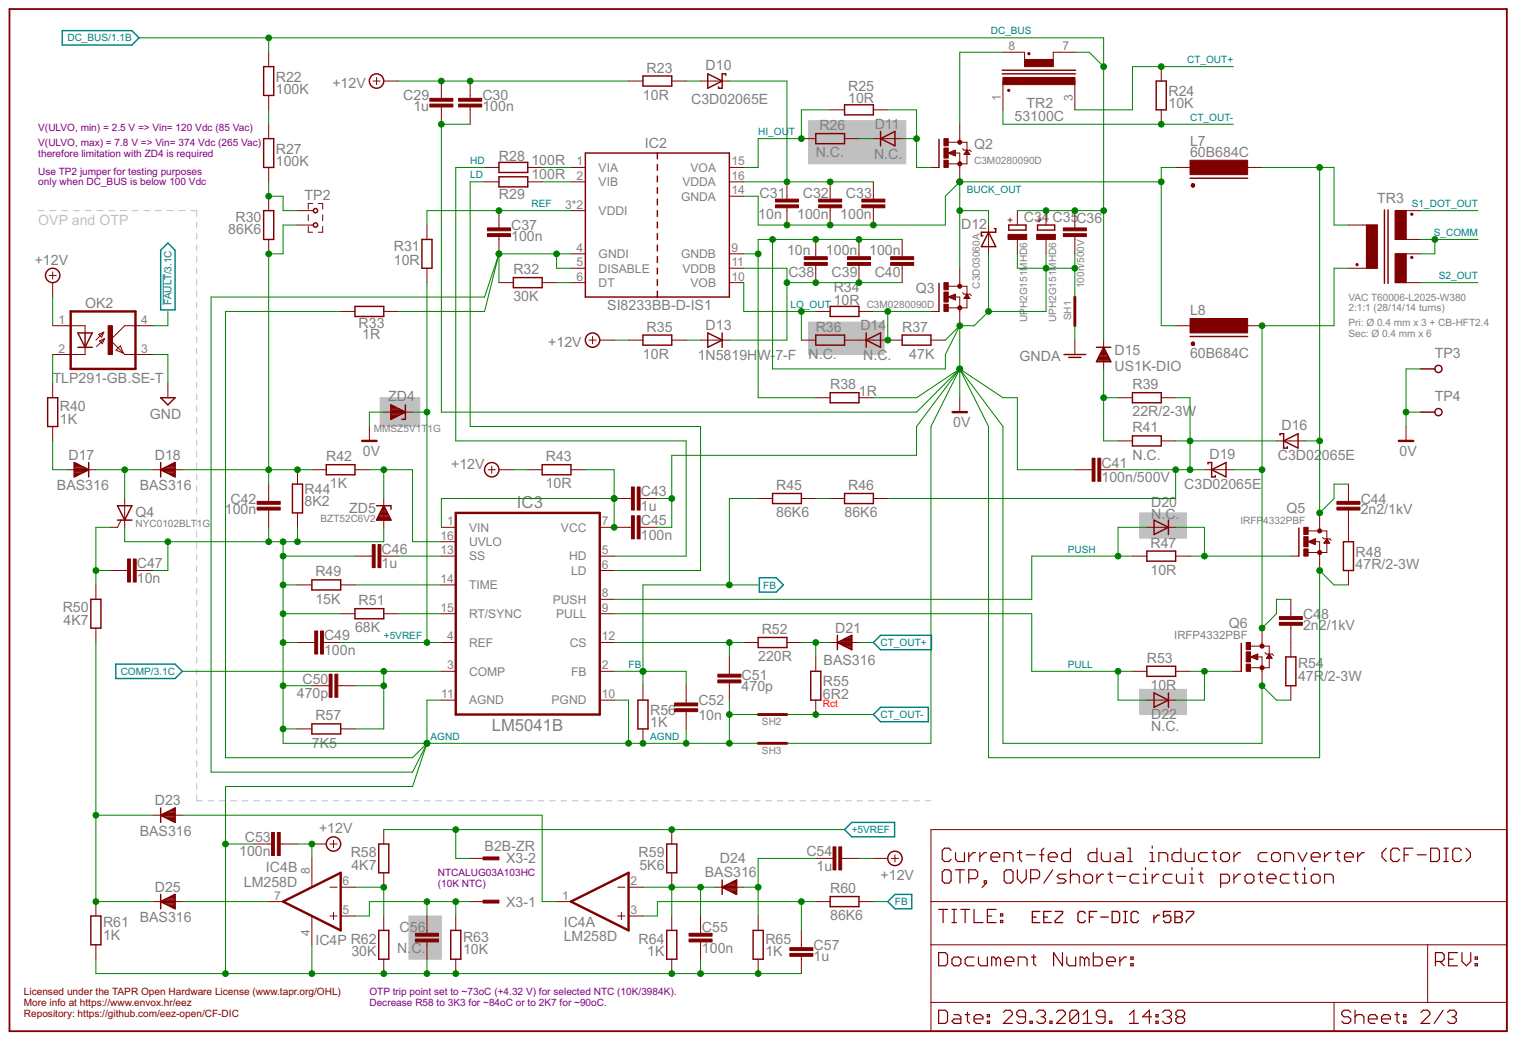
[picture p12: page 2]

CT_OUT- V(ULVO, min) = 2.5 V => Vin= 120 Vdc (85 Vac) V(ULVO, max) = 7.8 V => Vin= 374 Vdc (265 Vac)

therefore limitation with ZD4 is required Use TP2 jumper for testing purposes only when DC_BUS is below 100 Vdc

VAC T60006-L2025-W380
2:1:1 (28/14/14 turns) Pri: Ø 0.4 mm x 3 + CB-HFT2.4 Sec: Ø 0.4 mm x 6

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

OTP trip point set to ~73oC (+4.32 V) for selected NTC (10K/3984K). Decrease R58 to 3K3 for ~84oC or to 2K7 for ~90oC.

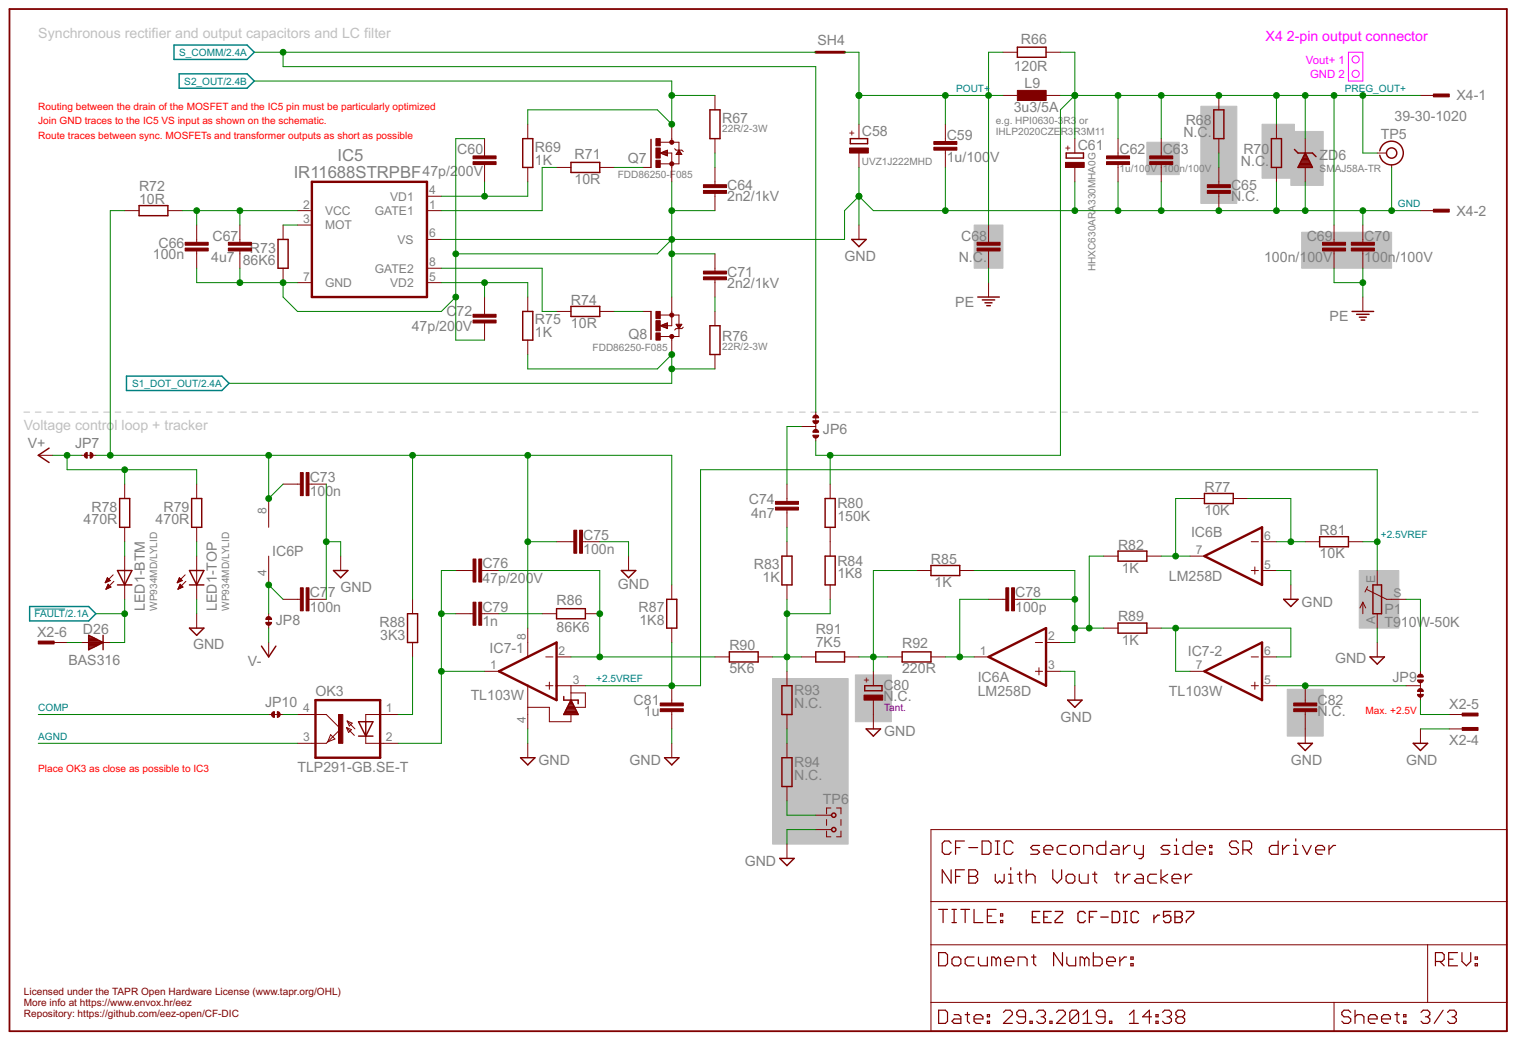
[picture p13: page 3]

Synchronous rectifier and output capacitors and LC filter

Routing between the drain of the MOSFET and the IC5 pin must be particularly optimized Route traces between sync. MOSFETs and transformer outputs as short as possible

Voltage control loop + tracker

Place OK3 as close as possible to IC3

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

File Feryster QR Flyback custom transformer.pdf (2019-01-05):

TI-EF20-6-7-2x12-8W | Marking:5851YMDD

## FERYSTER

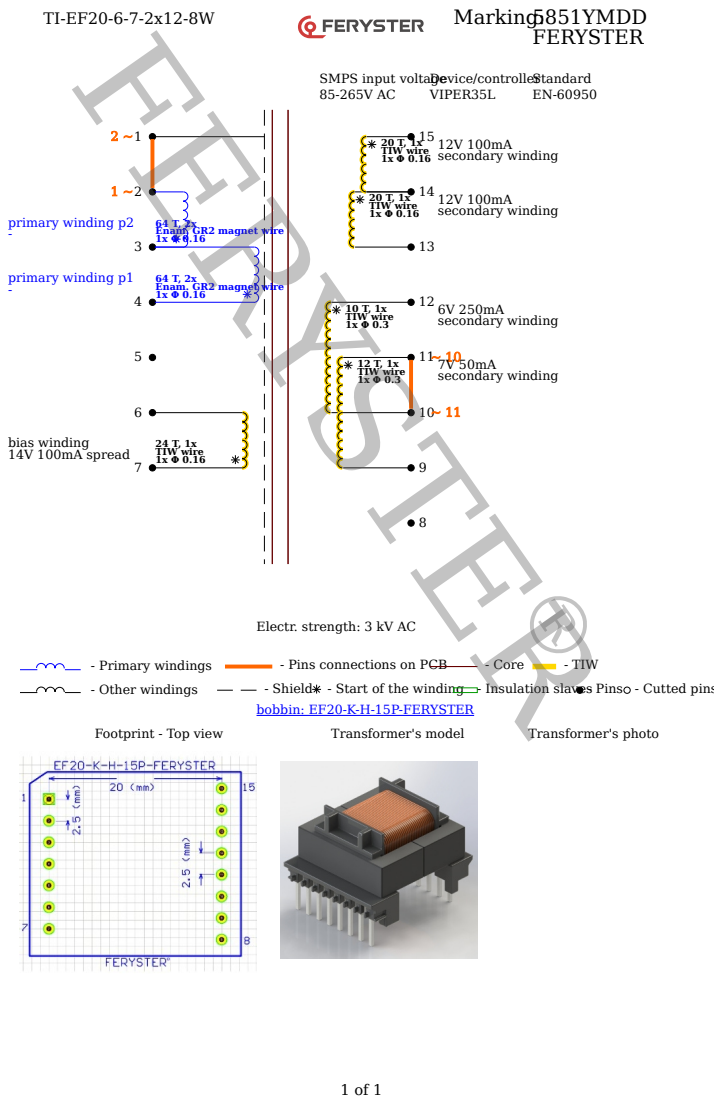
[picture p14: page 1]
- Primary windings; - Other windings; - Pins connections on PCB; - Core; - TIW; - Shield; - Start of the winding - Insulation slaves- Pins - Cutted pins; Footprint - Top view; Transformer's model; Transformer's photo; 64 T, 2x Enam. GR2 magnet wire 1x Φ 0.16 -; primary winding p1; TIW wire 14V 100mA spread; bias winding; 10 T, 1x TIW wire 1x Φ 0.3; 6V 250mA secondary winding; 12 T, 1x TIW wire 1x Φ 0.3; 7V 50mA secondary winding; 20 T, 1x TIW wire 1x Φ 0.16; 12V 100mA secondary winding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

SMPS input voltage

Electr. strength: 3 kV AC

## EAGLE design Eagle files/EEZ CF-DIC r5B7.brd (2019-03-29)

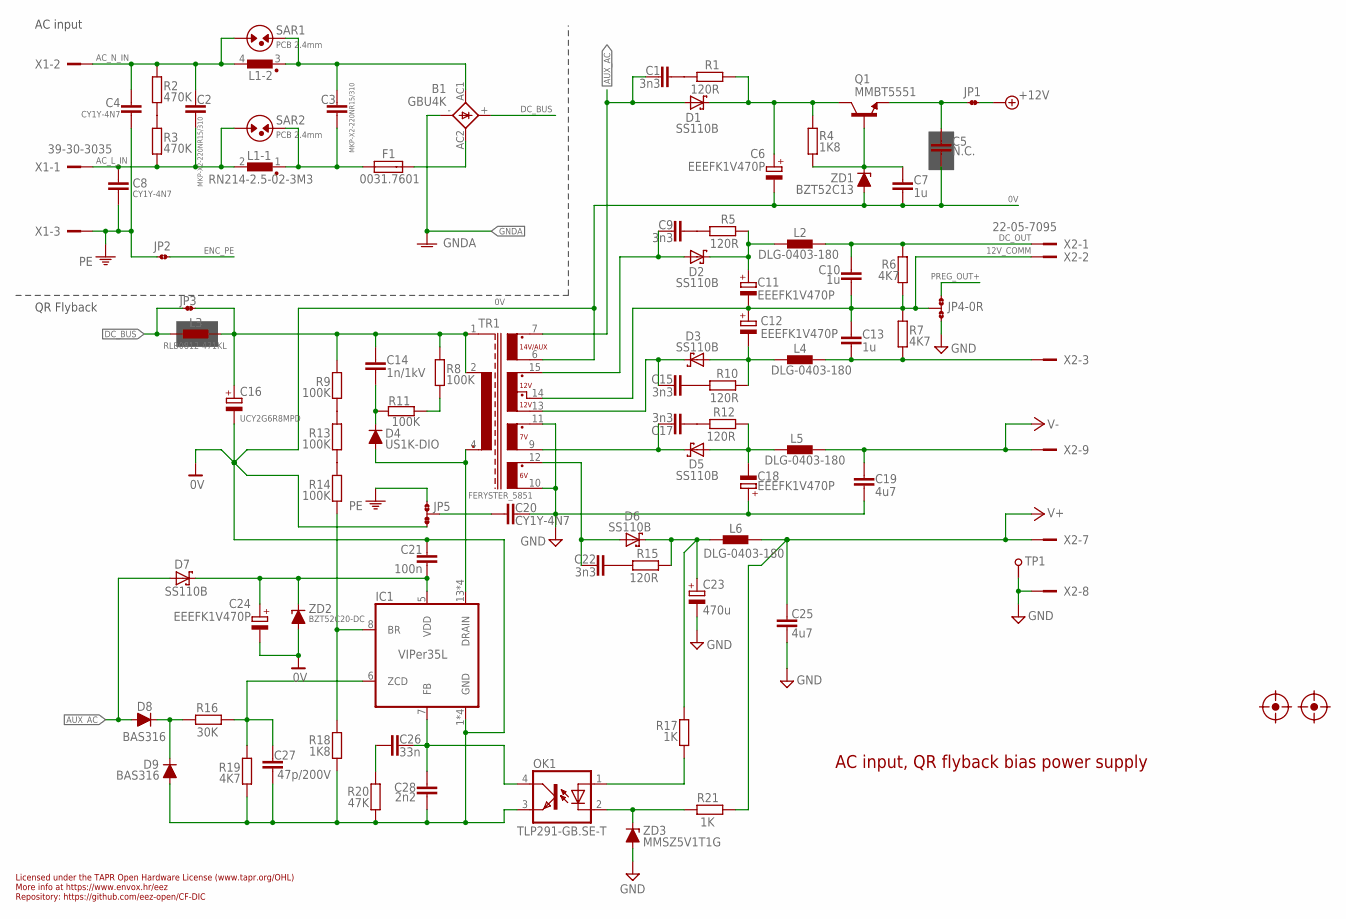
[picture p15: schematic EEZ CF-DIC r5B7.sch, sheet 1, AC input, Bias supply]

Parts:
B1: GBU4K; GBU4K_CRE
C1, C9, C15, C17, C22: 3n3; C0805
C2, C3: MKP-X2-220NR15/310; C150-072X183
C4, C8, C20: CY1Y-4N7; CY075-032X103
C5: N.C.; C0603
C6, C11, C12, C18, C24: EEEFK1V470P; CAPAE660X610N
C7, C10, C13: 1u; C0805
C14: 1n/1kV; C1210
C16: UCY2G6R8MPD; ECAP5/10.5
C19, C25: 4u7; C1206
C21: 100n; C0603
C23: 470u; ECAP5/10.5
C26: 33n; C0805
C27: 47p/200V; C0805
C28: 2n2; C0805
D1, D2, D3, D5, D6: SS110B; SMB
D4: US1K-DIO; DO214AA
D7: SS110B; SMA
D8, D9: BAS316; SOD323-R
F1: 0031.7601; FUSE_TR5
FM1, FM2: FIDUCIAL_2; FIDUCIAL_DUAL
IC1: VIPer35L; SOIC-16
JP1, JP3: JP2-NOCUT
JP2: JP2-CUT
JP4: 0R-JUMPA; A0R-JMP
JP5: JP3-CUT
L1: RN214-2.5-02-3M3; RN214; FARNELL 1191518
L2, L4, L5, L6: DLG-0403-180; DE0403
L3: RLB0812-471KL; FERSYTER_DSZ6
OK1: TLP291-GB.SE-T; SO4
Q1: MMBT5551; SOT23-BEC
R1, R5, R10, R12, R15: 120R; R0805
R2, R3: 470K; R1206
R4, R18: 1K8; R0805
R6, R7, R19: 4K7; R0805
R8, R9, R11, R13, R14: 100K; R1206
R16: 30K; R0805
R17, R21: 1K; R0805
R20: 47K; R0805
SAR1, SAR2: PCB 2.4mm; PCB-SAR_2.4MM
TP1: PCB_TEST_TABSHIELD; PCB_SHIELD_TAB
TR1: FERYSTER_5851; FERYSTER_5572
X1: 39-30-3035; MINIFIT_6659-3_CRE
X2: 22-05-7095; SPOX_22-05-7095
ZD1: BZT52C13; SOD123
ZD2: BZT52C20-DC; SOD123
ZD3: MMSZ5V1T1G; SOD123

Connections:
0V: C5.2, C6.2 (-), C7.2, C16.-, C21.1, C24.2 (-), C27.2, C28.2, D9.A, IC1.1 (GND), IC1.2 (GND), IC1.3 (GND), IC1.4 (GND), JP5.NC, OK1.3 (EMIT), R18.2, R19.1, R20.2, TR1.6 (S_AUX), ZD1.A, ZD2.A; also elsewhere on the board
6VAC: C22.2, D6.A, TR1.12 (6V_DOT)
7VAC: C17.2, D5.C, TR1.9 (7V)
12VAC1: C9.2, D2.A, TR1.15 (12V_DOT2)
12VAC2: C15.2, D3.C, TR1.13 (12V)
12V_COMM: C10.2, C11.2 (-), C12.1 (+), C13.1, JP4.2, R6.2, R7.1, TR1.14 (12V_DOT), X2.2
+6V_REC: C23.+, D6.C, L6.1, R15.1, R17.1
+12V: JP1.2; also elsewhere on the board
+12V_REC: C11.1 (+), D2.C, L2.1, R5.1
-7V_REC: C18.2 (-), D5.A, L5.1, R12.1
-12V: C13.2, L4.2, R7.2, X2.3
-12V_REC: C12.2 (-), D3.A, L4.1, R10.1
AC_L_IN: C2.2, C8.2, L1.2, R3.2, SAR2.1, X1.1
AC_N_IN: C2.1, C4.2, L1.4 (2), R2.1, SAR1.1, X1.2
AUX_AC: C1.2, D1.A, D7.A, D8.A, TR1.7 (S_AUX_DOT)
AUX_REC: C6.1 (+), D1.C, Q1.C, R1.1, R4.1
DC_BUS: B1.+, JP3.1, L3.P$1 (1); also elsewhere on the board
DC_OUT: C10.1, L2.2, R6.1, X2.1
ENC_PE: JP2.2
FB2: OK1.2 (C), R21.1, ZD3.C
GND: C18.1 (+), C19.1, C20.2, C23.-, C25.2, JP4.3, TP1.1, TR1.10 (6V), TR1.11 (7V_DOT), X2.8, ZD3.A; also elsewhere on the board
GNDA: B1.-; also elsewhere on the board
unnamed: C20.1, JP5.COM
unnamed: IC1.8 (BR), R14.2, R18.1
unnamed: C5.1, JP1.1, Q1.E
unnamed: C21.2, C24.1 (+), D7.C, IC1.5 (VDD), ZD2.C
unnamed: R2.2, R3.1
unnamed: B1.AC1, C3.1, L1.3 (1), SAR1.2
unnamed: C3.2, F1.1, L1.1, SAR2.2
unnamed: R13.2, R14.1
unnamed: R9.2, R13.1
unnamed: B1.AC2, F1.2
unnamed: C15.1, R10.2
unnamed: R8.2, R11.2
unnamed: C7.1, Q1.B, R4.2, ZD1.C
unnamed: OK1.1 (A), R17.2
unnamed: C14.2, D4.C, R11.1
unnamed: C26.2, C28.1, IC1.7 (FB), OK1.4 (COL)
unnamed: C9.1, R5.2
unnamed: C1.1, R1.2
unnamed: C27.1, IC1.6 (ZCD), R16.1, R19.2
unnamed: C17.1, R12.2
unnamed: C22.1, R15.2
unnamed: C26.1, R20.1
unnamed: D8.C, D9.C, R16.2
PE: C4.1, C8.1, JP2.1, JP5.NO, X1.3; also elsewhere on the board
PREG_OUT+: JP4.1; also elsewhere on the board
V+: C25.1, L6.2, R21.2, X2.7; also elsewhere on the board
V-: C19.2, L5.2, X2.9; also elsewhere on the board
VIPER+: C14.1, C16.+, JP3.2, L3.P$2 (2), R8.1, R9.1, TR1.1 (SHIELD), TR1.2
VIPER_D: D4.A, IC1.13 (DRAIN), IC1.14 (DRAIN), IC1.15 (DRAIN), IC1.16 (DRAIN), TR1.4 (P2_DOT)

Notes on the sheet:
Licensed under the TAPR Open Hardware License (www.tapr.org/OHL)
Repository: https://github.com/eez-open/CF-DIC
More info at https://www.envox.hr/eez
AC input, QR flyback bias power supply
QR Flyback
AC input

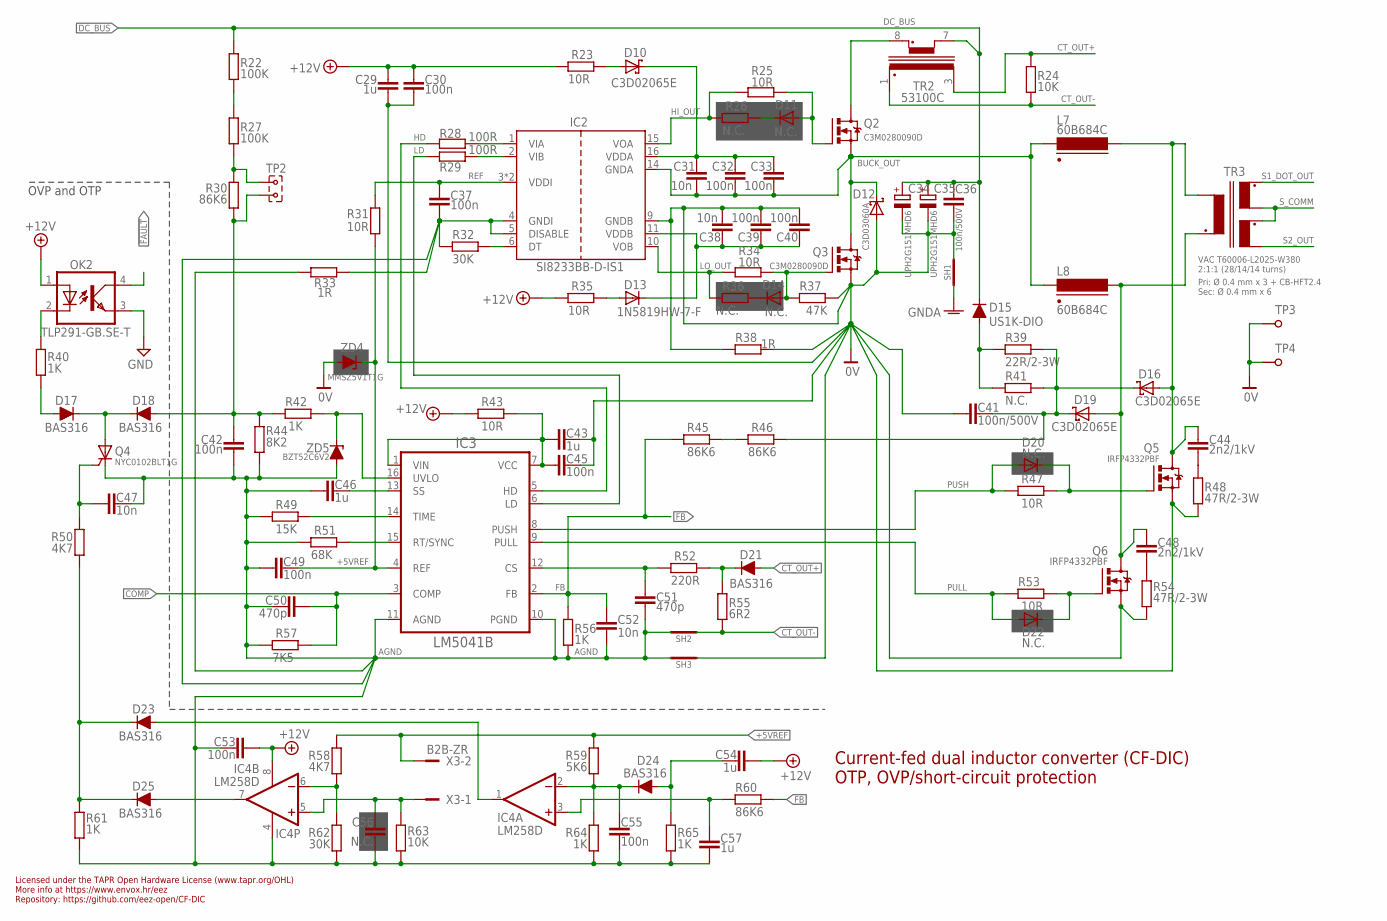
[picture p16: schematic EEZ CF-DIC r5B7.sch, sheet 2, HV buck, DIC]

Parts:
C29, C43, C46, C54, C57: 1u; C0805
C30, C32, C33, C37, C39, C40, C42, C45, C49, C53, C55: 100n; C0603
C31, C38, C47, C52: 10n; C0603
C34, C35: UPH2G151MHD6; ECAP7.5/18
C36, C41: 100n/500V; C1812
C44, C48: 2n2/1kV; C1210
C50, C51: 470p; C0805
C56: N.C.; C0603
D10, D16, D19: C3D02065E; TO252-L
D11, D14, D20, D22: N.C.; SOD323-W
D12: C3D03060A; TO220-2
D13: 1N5819HW-7-F; SOD323-W
D15: US1K-DIO; DO214AA
D17, D18, D21, D23, D24, D25: BAS316; SOD323-R
IC2: SI8233BB-D-IS1; SOIC-16
IC3: LM5041B; MTC16
IC4: LM258D; SOIC127P600X173-8N
L7, L8: 60B684C; MURATA_6000B
OK2: TLP291-GB.SE-T; SO4
Q2, Q3: C3M0280090D; TO247BV
Q4: NYC0102BLT1G; SOT23
Q5, Q6: IRFP4332PBF; TO247BV
R22, R27: 100K; R1206
R23, R25, R31, R34, R35, R43, R47, R53: 10R; R0805
R24, R63: 10K; R0805
R26, R36: N.C.; R0805
R28, R29: 100R; R0805
R30, R45, R46, R60: 86K6; R0805
R32, R62: 30K; R0805
R33, R38: 1R; R0805
R37: 47K; R0805
R39: 22R/2-3W; R2512
R40, R42, R56, R61, R64, R65: 1K; R0805
R41: N.C.; R2512
R44: 8K2; R0805
R48, R54: 47R/2-3W; R2512
R49: 15K; R0805
R50, R58: 4K7; R0805
R51: 68K; R0805
R52: 220R; R0805
R55: 6R2; R0805
R57: 7K5; R0805
R59: 5K6; R0805
SH1, SH2, SH3: SHORTNOHOLE; SHORT_NOHOLE
TP2: JUMPER-2PIN-2MM; 2MM-2
TP3, TP4: TEST-PIN1.2; TEST-PIN_1.2MM
TR2: 53100C; MURATA_5300
TR3: VAC T60006-L2025-W380; VAC_DUAL_SEC
X3: B2B-ZR
ZD4: MMSZ5V1T1G; SOD123
ZD5: BZT52C6V2; SOD123

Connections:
0V: C29.1, C30.1, C34.-, C35.-, C36.2, C38.2, C39.2, C40.2, C41.1, C43.2, C45.2, D12.2 (A), IC2.9 (GNDB), Q3.S, Q5.S, Q6.S, R37.2, R38.1, R38.2, R48.2, R54.2, SH1.P$2 (GND_B), SH3.P$1 (GND_A), TP3.1, TP4.1, ZD4.A; also elsewhere on the board
!FAULT: OK2.4 (COL); also elsewhere on the board
+5VREF: C49.2, IC3.4 (REF), R31.1, R58.2, R59.2, X3.2, ZD4.C
+12V: C29.2, C30.2, C53.1, C54.1, IC4.8 (V+), OK2.1 (A), R23.2, R35.2, R43.2; also elsewhere on the board
AGND: C37.1, C42.2, C46.1, C47.2, C49.1, C50.1, C51.1, C52.2, C53.2, C55.2, C56.1, C57.1, IC2.4 (GNDI), IC2.5 (DISABLE), IC3.10 (PGND), IC3.11 (AGND), IC4.4 (V-), Q4.1 (C), R32.1, R33.1, R33.2, R44.2, R49.2, R51.2, R56.2, R57.2, R61.2, R62.2, R63.2, R64.2, R65.2, SH2.P$2 (GND_B), SH3.P$2 (GND_B), ZD5.A; also elsewhere on the board
BUCK_OUT: C31.2, C32.2, C33.2, D12.1 (C), IC2.14 (GNDA), L7.2, L8.2, Q2.S, Q3.D
CLAMP_C: C41.2, D16.1 (C), D16.3 (C), D19.1 (C), D19.3 (C), R39.1, R41.1, R46.2
COMP: C50.2, IC3.3 (COMP), R57.1; also elsewhere on the board
CT_OUT+: D21.A, R24.1, TR2.3 (S)
CT_OUT-: R24.2, R55.2, SH2.P$1 (GND_A), TR2.1 (S_DOT)
DC_BUS: C34.+, C35.+, C36.1, D15.C, R22.1, TR2.7; also elsewhere on the board
FB: C52.1, IC3.2 (FB), R45.1, R56.1, R60.1
GND: OK2.3 (EMIT); also elsewhere on the board
GNDA: SH1.P$1 (GND_A); also elsewhere on the board
HD: IC3.5 (HD), R28.2
HI_OUT: IC2.15 (VOA), R25.2, R26.2
LD: IC3.6 (LD), R29.2
LO_OUT: IC2.10 (VOB), R34.1, R36.1
L_PULL: C48.2, D19.2 (A), L8.1, Q6.D, TR3.P1_DOT (P_DOT)
L_PUSH: C44.2, D16.2 (A), L7.1, Q5.D, TR3.P1
unnamed: R27.2, R30.1, TP2.1
unnamed: C31.1, C32.1, C33.1, D10.1 (C), D10.3 (C), IC2.16 (VDDA)
unnamed: C48.1, R54.1
unnamed: R22.2, R27.1
unnamed: C55.1, D24.C, IC4.2 (-IN), R59.1, R64.1
unnamed: D20.C, Q5.G, R47.1
unnamed: D22.C, Q6.G, R53.1
unnamed: Q2.D, TR2.8 (P_DOT)
unnamed: IC3.15 (RT/SYNC), R51.1
unnamed: D11.A, Q2.G, R25.1
unnamed: IC3.14 (TIME), R49.1
unnamed: C46.2, IC3.13 (SS)
unnamed: IC3.16 (UVLO), R42.1, ZD5.C
unnamed: IC4.6 (-IN), R58.1, R62.1
unnamed: D14.A, Q3.G, R34.2, R37.1
unnamed: R45.2, R46.1
unnamed: D10.2 (A), R23.1
unnamed: OK2.2 (C), R40.1
unnamed: C57.2, IC4.3 (+IN), R60.2
unnamed: D15.A, R39.2, R41.2
unnamed: IC2.1 (VIA), R28.1
unnamed: C51.2, IC3.12 (CS), R52.2
unnamed: D23.A, IC4.1 (OUT)
unnamed: IC2.2 (VIB), R29.1
unnamed: C56.2, IC4.5 (+IN), R63.1, X3.1
unnamed: D11.C, R26.1
unnamed: D25.A, IC4.7 (OUT)
unnamed: IC2.6 (DT), R32.2
unnamed: D23.C, D25.C, R50.2, R61.1
unnamed: D14.C, R36.2
unnamed: C43.1, C45.1, IC3.1 (VIN), IC3.7 (VCC), R43.1
unnamed: C38.1, C39.1, C40.1, D13.C, IC2.11 (VDDB)
unnamed: D21.C, R52.1, R55.1
unnamed: C54.2, D24.A, R65.1
unnamed: D13.A, R35.1
unnamed: C44.1, R48.1
unnamed: C47.1, Q4.2 (G), R50.1
unnamed: D17.C, D18.C, Q4.3 (A)
unnamed: D17.A, R40.2
PULL: D22.A, IC3.9 (PULL), R53.2
PUSH: D20.A, IC3.8 (PUSH), R47.2
REF: C37.2, IC2.3 (VDDI), IC2.8 (VDDI), R31.2
S1_DOT_OUT: TR3.S1_DOT; also elsewhere on the board
S2_OUT: TR3.S2; also elsewhere on the board
S_COMM: TR3.S1, TR3.S2_DOT; also elsewhere on the board
UVLO: C42.1, D18.A, R30.2, R42.2, R44.1, TP2.2

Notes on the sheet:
Licensed under the TAPR Open Hardware License (www.tapr.org/OHL)
Repository: https://github.com/eez-open/CF-DIC
More info at https://www.envox.hr/eez
Current-fed dual inductor converter (CF-DIC) OTP, OVP/short-circuit protection
OVP and OTP
2:1:1 (28/14/14 turns)
Pri: Ø 0.4 mm x 3 + CB-HFT2.4
Sec: Ø 0.4 mm x 6

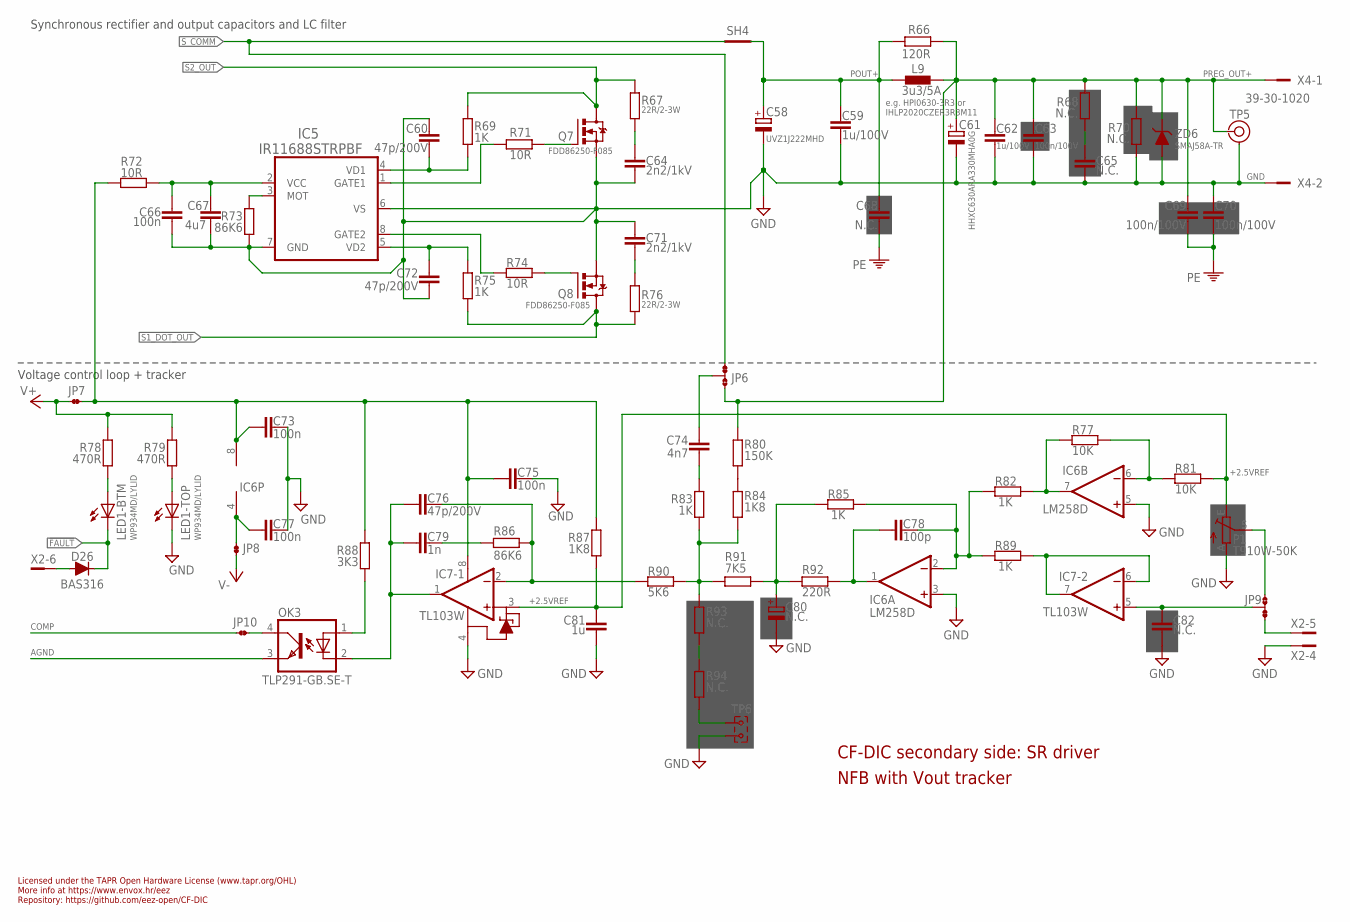
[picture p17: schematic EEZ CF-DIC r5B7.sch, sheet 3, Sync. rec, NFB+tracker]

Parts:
C58: UVZ1J222MHD; ECAP7.5/18-H35.5A
C59, C62: 1u/100V; C1206
C60, C72, C76: 47p/200V; C0805
C61: HHXC630ARA330MHA0G; CAPAE830X1050N
C63, C69, C70: 100n/100V; C1206
C64, C71: 2n2/1kV; C1210
C65, C68: N.C.; C1206
C66, C73, C75, C77: 100n; C0603
C67: 4u7; C1206
C74: 4n7; C0805
C78: 100p; C0805
C79: 1n; C0805
C80: N.C.; EC1206
C81: 1u; C0805
C82: N.C.; C0805
D26: BAS316; SOD323-R
IC5: IR11688STRPBF; SO8
IC6: LM258D; SOIC127P600X173-8N
IC7: TL103W; SOIC127P600X173-8N
JP6, JP9: JP3-CUT
JP7, JP8, JP10: JP2-NOCUT
L9: 3u3/5A; COILCRAFT_HPI0630
LED1: WP934MD/LYLID; WP934MD
OK3: TLP291-GB.SE-T; SO4
P1: T910W-50K; S64W
Q7, Q8: FDD86250-F085; TO229P990X239-3N
R66: 120R; R0805
R67, R76: 22R/2-3W; R2512
R68: N.C.; R1210
R69, R75, R82, R83, R85, R89: 1K; R0805
R70: N.C.; R2512
R71, R72, R74: 10R; R0805
R73, R86: 86K6; R0805
R77, R81: 10K; R0805
R78, R79: 470R; R0805
R80: 150K; R0805
R84, R87: 1K8; R0805
R88: 3K3; R0805
R90: 5K6; R0805
R91: 7K5; R0805
R92: 220R; R0805
R93, R94: N.C.; R0805
SH4: SHORTNOHOLE; SHORT_NOHOLE
TP5: TEST_POINT-2; TP_1.1MM_2
TP6: JUMPER-2PIN-2MM; 2MM-2
X2: 22-05-7095; SPOX_22-05-7095
X4: 39-30-1020; MINIFIT_39301020
ZD6: SMAJ58A-TR; DO214AC

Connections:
!FAULT: D26.C, LED1.BC (C); also elsewhere on the board
+2.5VREF: C81.1, IC7.3 (+IN1), P1.E, R81.2, R87.1
AGND: OK3.3 (EMIT); also elsewhere on the board
COMP: JP10.1; also elsewhere on the board
G1_OUT: Q7.1 (G), R71.1
G2_OUT: Q8.1 (G), R74.1
GATE1: IC5.1 (GATE1), R71.2
GATE2: IC5.8 (GATE2), R74.2
GND: C58.-, C59.2, C60.1, C61.-, C62.2, C63.2, C64.2, C65.1, C66.2, C67.2, C70.1, C71.2, C72.1, C73.2, C75.2, C77.2, C80.-, C81.2, C82.2, IC5.6 (VS), IC5.7 (GND), IC6.3 (+IN), IC6.5 (+IN), IC7.4 (VCC-), LED1.TC (C), P1.A, Q7.3 (S), Q8.3 (S), R70.1, R73.2, TP5.GND, TP6.2, X2.4, X4.2, ZD6.A; also elsewhere on the board
unnamed: D26.A, X2.6
unnamed: C65.2, R68.1
unnamed: C79.2, R86.2
unnamed: C76.2, IC7.2 (-IN1), R86.1, R90.1
unnamed: LED1.TA (A), R79.2
unnamed: R80.1, R84.2
unnamed: LED1.BA (A), R78.2
unnamed: IC5.3 (MOT), R73.1
unnamed: C74.2, R83.2
unnamed: C77.1, IC6.4 (V-), JP8.1
unnamed: JP10.2, OK3.4 (COL)
unnamed: C73.1, C75.1, IC6.8 (V+), IC7.8 (VCC+), JP7.2, R72.1, R87.2, R88.2
unnamed: R83.1, R84.1, R90.2, R91.2, R93.2
unnamed: IC6.7 (OUT), R77.1, R82.2
unnamed: C82.1, IC7.5 (+IN), JP9.COM
unnamed: JP9.NO, P1.S
unnamed: C78.2, IC6.2 (-IN), R82.1, R85.2, R89.1
unnamed: C71.1, R76.2
unnamed: C64.1, R67.2
unnamed: C74.1, JP6.COM
unnamed: R93.1, R94.2
unnamed: C76.1, C79.1, IC7.1 (OUT1), OK3.2 (C)
unnamed: R94.1, TP6.1
unnamed: IC6.6 (-IN), R77.2, R81.1
unnamed: C78.1, IC6.1 (OUT), R92.2
NFB_OFFSET: C80.+, R85.1, R91.1, R92.1
OK_A: OK3.1 (A), R88.1
PE: C68.2, C69.2, C70.2; also elsewhere on the board
POUT+: C58.+, C59.1, C68.1, L9.1, R66.1, SH4.P$2 (GND_B)
PREG_OUT+: C61.+, C62.1, C63.1, C69.1, JP6.NO, L9.2, R66.2, R68.2, R70.2, R80.2, TP5.TIP, X4.1, ZD6.C; also elsewhere on the board
S1_DOT_OUT: Q8.2 (D), R75.1, R76.1; also elsewhere on the board
S2_OUT: Q7.2 (D), R67.1, R69.2; also elsewhere on the board
SYNC_VCC: C66.1, C67.1, IC5.2 (VCC), R72.2
S_COMM: JP6.NC, SH4.P$1 (GND_A); also elsewhere on the board
U_CTRL: JP9.NC, X2.5
U_MON1: IC7.6 (-IN), IC7.7 (OUT), R89.2
V+: JP7.1, R78.1, R79.1; also elsewhere on the board
V-: JP8.2; also elsewhere on the board
VD1: C60.2, IC5.4 (VD1), R69.1
VD2: C72.2, IC5.5 (VD2), R75.2

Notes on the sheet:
Licensed under the TAPR Open Hardware License (www.tapr.org/OHL)
Repository: https://github.com/eez-open/CF-DIC
More info at https://www.envox.hr/eez
CF-DIC secondary side: SR driver
NFB with Vout tracker
Voltage control loop + tracker
Synchronous rectifier and output capacitors and LC filter
e.g. HPI0630-3R3 or IHLP2020CZER3R3M11

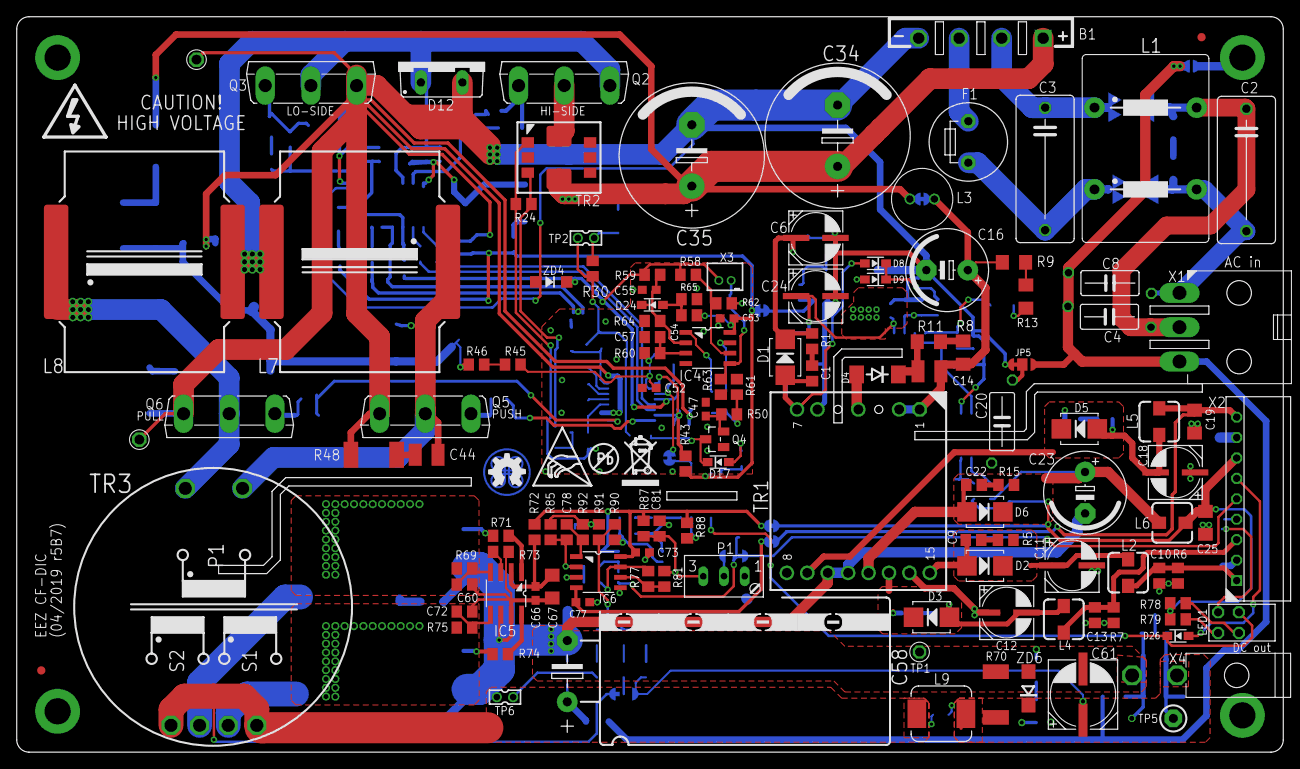
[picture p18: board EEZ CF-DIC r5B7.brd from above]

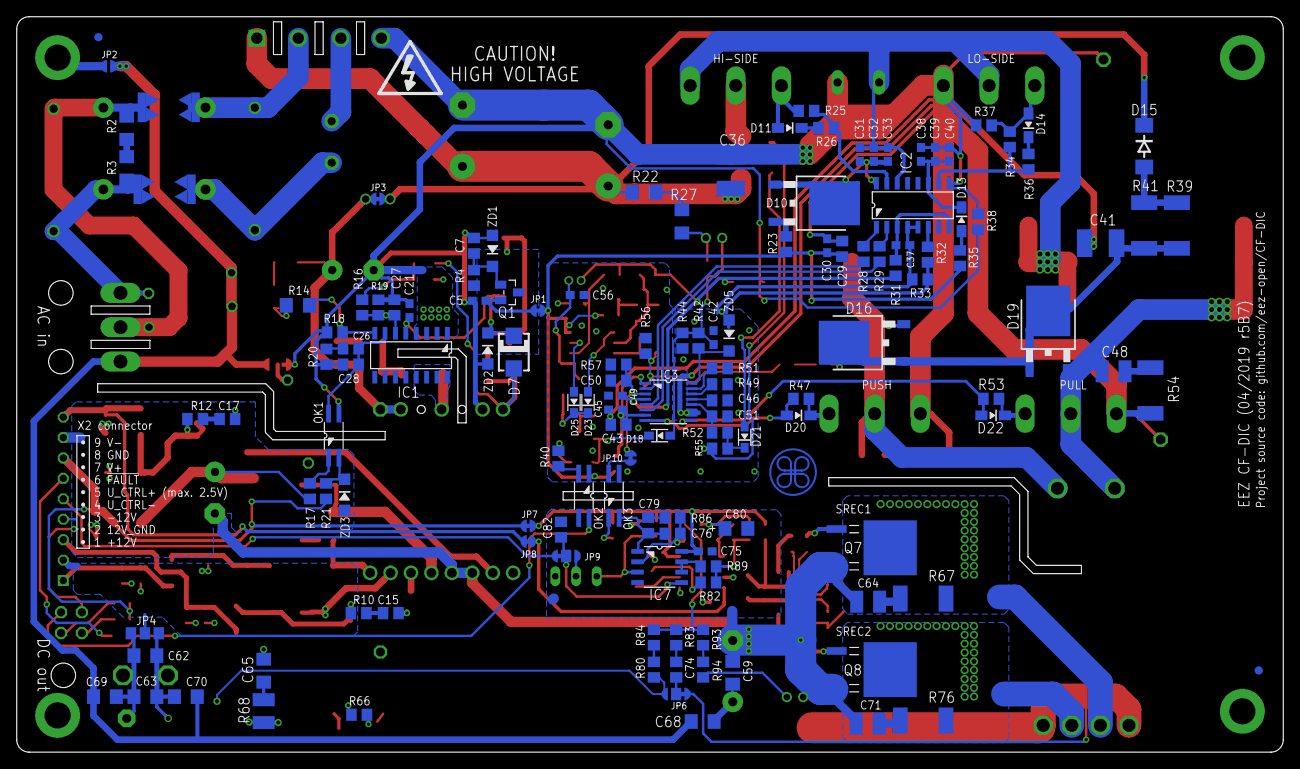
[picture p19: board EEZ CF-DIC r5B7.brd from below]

Board: 2 copper layers, 155.0 x 90.0 mm, 274 parts (136 on the bottom side), 149 nets.

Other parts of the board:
EEZ_SIGNATURE: SIGNATURESMALL; SIGNATURE_5MM
U$2: RECYCLE_BIN1/8
U$4: ESD_SYMBOL
U$7: PB_SMALL

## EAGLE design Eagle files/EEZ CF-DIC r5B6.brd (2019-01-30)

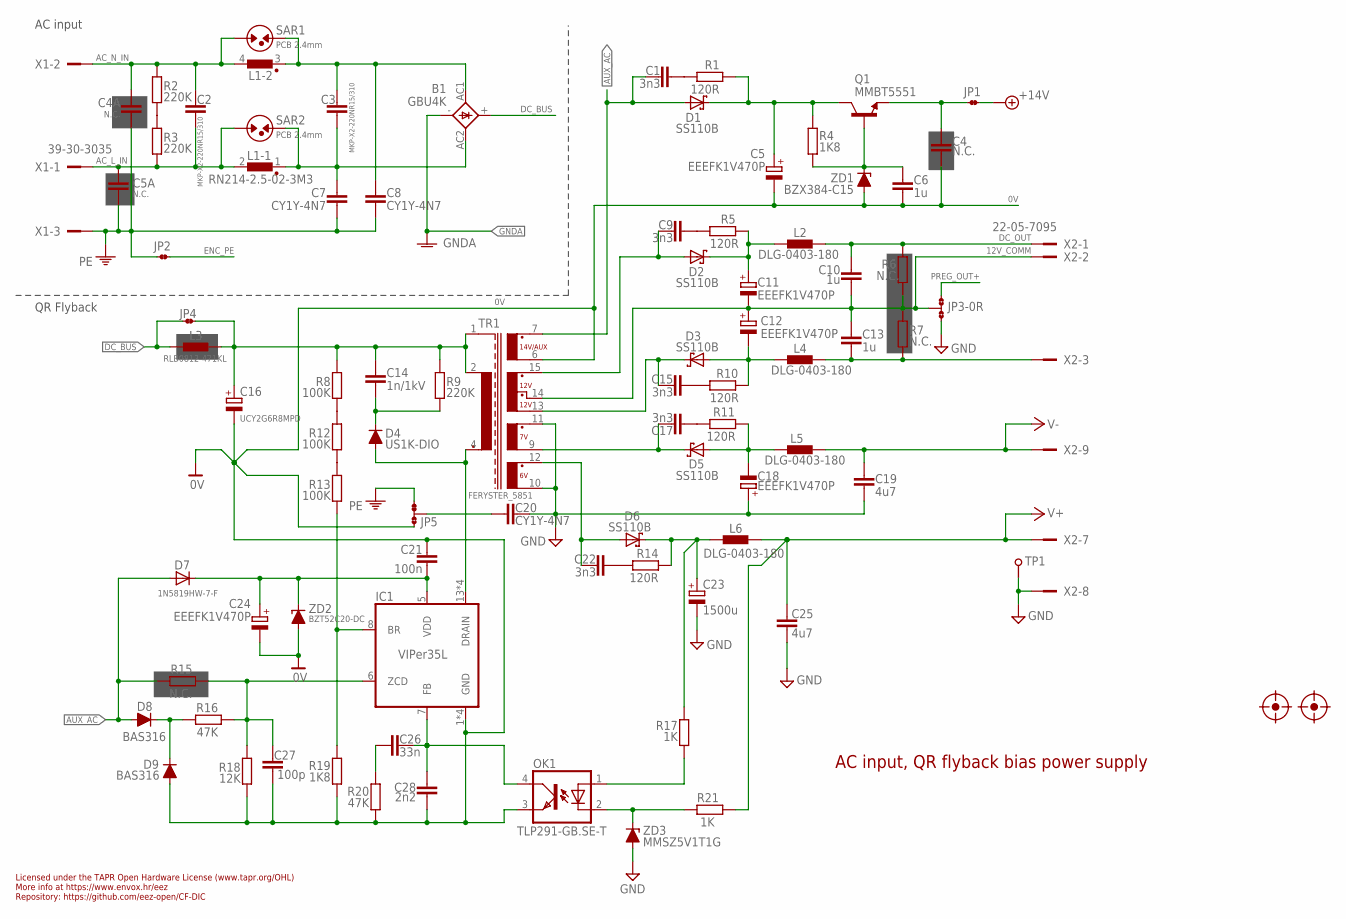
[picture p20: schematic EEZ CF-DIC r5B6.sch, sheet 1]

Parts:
B1: GBU4K; GBU4K_CRE
C1, C9, C15, C17, C22: 3n3; C0805
C2, C3: MKP-X2-220NR15/310; C150-072X183
C4: N.C.; C0603
C4A: N.C.; CY075-032X103-ROTATED
C5, C11, C12, C18, C24: EEEFK1V470P; CAPAE660X610N
C5A: N.C.; CY075-032X103
C6, C10, C13: 1u; C0805
C7, C8, C20: CY1Y-4N7; CY075-032X103
C14: 1n/1kV; C1210
C16: UCY2G6R8MPD; ECAP5/10.5
C19, C25: 4u7; C1206
C21: 100n; C0603
C23: 1500u; ECAP5/13
C26: 33n; C0805
C27: 100p; C0805
C28: 2n2; C0805
D1, D2, D3, D5, D6: SS110B; SMB
D4: US1K-DIO; DO214AA
D7: 1N5819HW-7-F; SOD323-W
D8, D9: BAS316; SOD323-R
FM1, FM2: FIDUCIAL_2; FIDUCIAL_DUAL
IC1: VIPer35L; SOIC-16
JP1, JP2, JP4: JP2-NOCUT
JP3: 0R-JUMPA; A0R-JMP
JP5: JP3-CUT
L1: RN214-2.5-02-3M3; RN214; FARNELL 1191518
L2, L4, L5, L6: DLG-0403-180; DE0403
L3: RLB0812-471KL; FERSYTER_DSZ6
OK1: TLP291-GB.SE-T; SO4
Q1: MMBT5551; SOT23-BEC
R1, R5, R10, R11, R14: 120R; R0805
R2, R3, R9: 220K; R1206
R4, R19: 1K8; R0805
R6, R7, R15: N.C.; R0805
R8, R12, R13: 100K; R1206
R16, R20: 47K; R0805
R17, R21: 1K; R0805
R18: 12K; R0805
SAR1, SAR2: PCB 2.4mm; PCB-SAR_2.4MM
TP1: PCB_TEST_TABSHIELD; PCB_SHIELD_TAB
TR1: FERYSTER_5851; FERYSTER_5572
X1: 39-30-3035; MINIFIT_6659-3_CRE
X2: 22-05-7095; SPOX_22-05-7095
ZD1: BZX384-C15; SOD323-W
ZD2: BZT52C20-DC; SOD123
ZD3: MMSZ5V1T1G; SOD323-W

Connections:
0V: C4.2, C5.2 (-), C6.2, C16.-, C21.1, C24.2 (-), C27.2, C28.2, D9.A, IC1.1 (GND), IC1.2 (GND), IC1.3 (GND), IC1.4 (GND), JP5.NO, OK1.3 (EMIT), R18.1, R19.2, R20.2, TR1.6 (S_AUX), ZD1.A, ZD2.A; also elsewhere on the board
6VAC: C22.2, D6.A, TR1.12 (6V_DOT)
7VAC: C17.2, D5.C, TR1.9 (7V)
12VAC1: C9.2, D2.A, TR1.15 (12V_DOT2)
12VAC2: C15.2, D3.C, TR1.13 (12V)
12V_COMM: C10.2, C11.2 (-), C12.1 (+), C13.1, JP3.2, R6.2, R7.1, TR1.14 (12V_DOT), X2.2
+6V_REC: C23.+, D6.C, L6.1, R14.1, R17.1
+12V_REC: C11.1 (+), D2.C, L2.1, R5.1
+14V: JP1.2; also elsewhere on the board
-7V_REC: C18.2 (-), D5.A, L5.1, R11.1
-12V: C13.2, L4.2, R7.2, X2.3
-12V_REC: C12.2 (-), D3.A, L4.1, R10.1
AC_L_IN: C2.2, C5A.2, L1.2, R3.2, SAR2.1, X1.1
AC_N_IN: C2.1, C4A.2, L1.4 (2), R2.1, SAR1.1, X1.2
AUX_AC: C1.2, D1.A, D7.A, D8.A, R15.2, TR1.7 (S_AUX_DOT)
AUX_REC: C5.1 (+), D1.C, Q1.C, R1.1, R4.1
DC_BUS: B1.+, JP4.1, L3.P$1 (1); also elsewhere on the board
DC_OUT: C10.1, L2.2, R6.1, X2.1
ENC_PE: JP2.2
FB2: OK1.2 (C), R21.1, ZD3.C
GND: C18.1 (+), C19.1, C20.2, C23.-, C25.2, JP3.3, TP1.1, TR1.10 (6V), TR1.11 (7V_DOT), X2.8, ZD3.A; also elsewhere on the board
GNDA: B1.-; also elsewhere on the board
unnamed: C20.1, JP5.COM
unnamed: IC1.8 (BR), R13.2, R19.1
unnamed: C4.1, JP1.1, Q1.E
unnamed: C21.2, C24.1 (+), D7.C, IC1.5 (VDD), ZD2.C
unnamed: R2.2, R3.1
unnamed: B1.AC1, C3.1, C8.2, L1.3 (1), SAR1.2
unnamed: B1.AC2, C3.2, C7.2, L1.1, SAR2.2
unnamed: R12.2, R13.1
unnamed: R8.2, R12.1
unnamed: C15.1, R10.2
unnamed: C6.1, Q1.B, R4.2, ZD1.C
unnamed: OK1.1 (A), R17.2
unnamed: C14.2, D4.C, R9.2
unnamed: C26.2, C28.1, IC1.7 (FB), OK1.4 (COL)
unnamed: C9.1, R5.2
unnamed: C1.1, R1.2
unnamed: C27.1, IC1.6 (ZCD), R15.1, R16.1, R18.2
unnamed: C17.1, R11.2
unnamed: C22.1, R14.2
unnamed: C26.1, R20.1
unnamed: D8.C, D9.C, R16.2
PE: C4A.1, C5A.1, C7.1, C8.1, JP2.1, JP5.NC, X1.3; also elsewhere on the board
PREG_OUT+: JP3.1; also elsewhere on the board
V+: C25.1, L6.2, R21.2, X2.7; also elsewhere on the board
V-: C19.2, L5.2, X2.9; also elsewhere on the board
VIPER+: C14.1, C16.+, JP4.2, L3.P$2 (2), R8.1, R9.1, TR1.1 (SHIELD), TR1.2
VIPER_D: D4.A, IC1.13 (DRAIN), IC1.14 (DRAIN), IC1.15 (DRAIN), IC1.16 (DRAIN), TR1.4 (P2_DOT)

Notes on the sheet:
Licensed under the TAPR Open Hardware License (www.tapr.org/OHL)
Repository: https://github.com/eez-open/CF-DIC
More info at https://www.envox.hr/eez
AC input, QR flyback bias power supply
QR Flyback
AC input

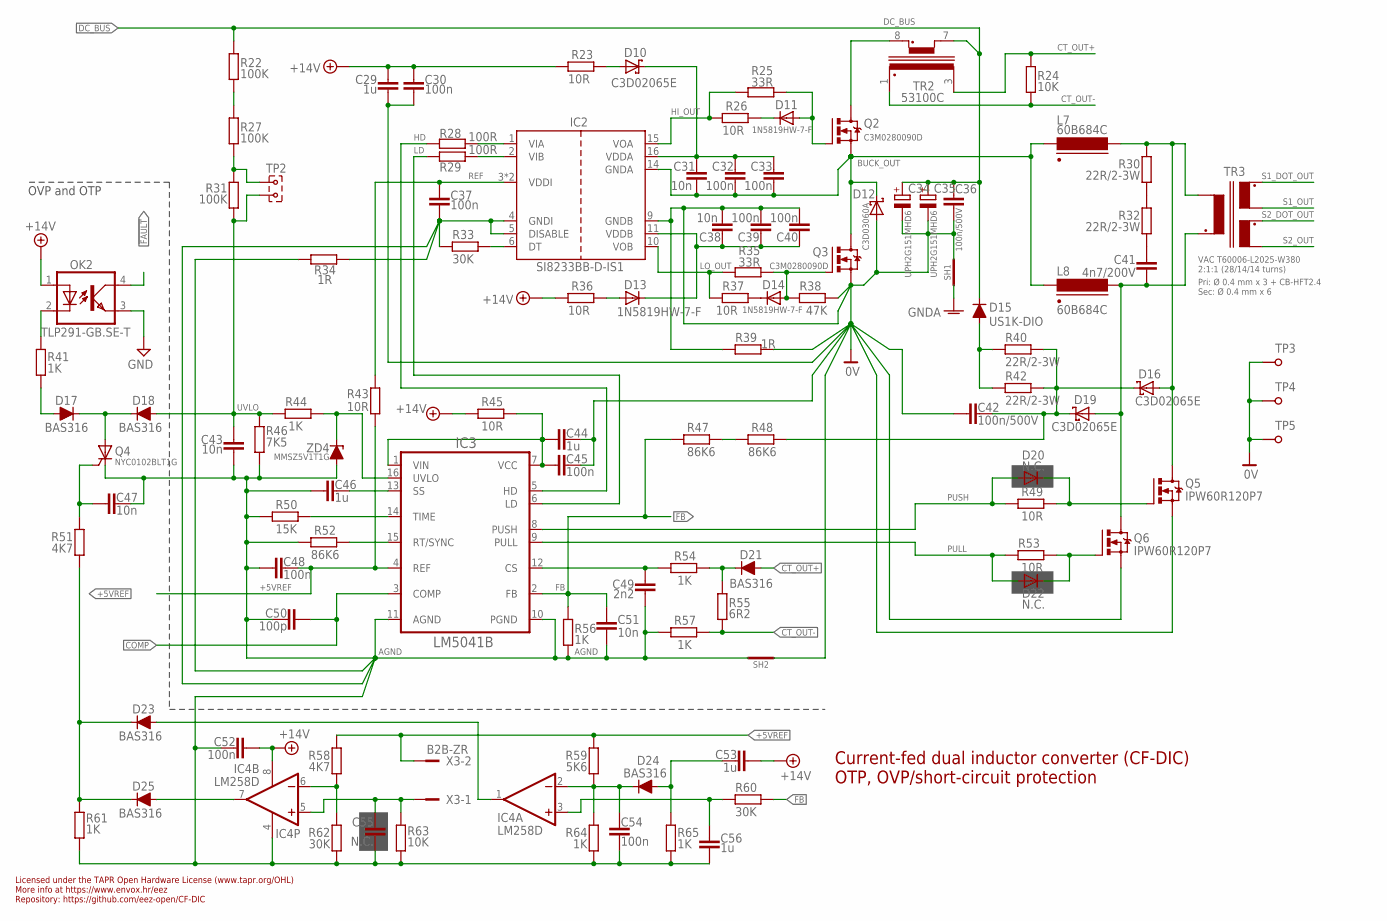
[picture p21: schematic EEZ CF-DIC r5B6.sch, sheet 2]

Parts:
C29, C44, C46, C53, C56: 1u; C0805
C30, C32, C33, C37, C39, C40, C45, C48, C52, C54: 100n; C0603
C31, C38, C43, C47, C51: 10n; C0603
C34, C35: UPH2G151MHD6; ECAP7.5/18
C36, C42: 100n/500V; C1812
C41: 4n7/200V; C1210
C49: 2n2; C0805
C50: 100p; C0805
C55: N.C.; C0603
D10, D16, D19: C3D02065E; TO252-L
D11, D13, D14: 1N5819HW-7-F; SOD323-W
D12: C3D03060A; TO220-2
D15: US1K-DIO; DO214AA
D17, D18, D21, D23, D24, D25: BAS316; SOD323-R
D20, D22: N.C.; SOD323-W
IC2: SI8233BB-D-IS1; SOIC-16
IC3: LM5041B; MTC16
IC4: LM258D; SOIC127P600X173-8N
L7, L8: 60B684C; MURATA_6000B
OK2: TLP291-GB.SE-T; SO4
Q2, Q3: C3M0280090D; TO247BV
Q4: NYC0102BLT1G; SOT23
Q5, Q6: IPW60R120P7; TO247BV
R22, R27, R31: 100K; R1206
R23, R26, R36, R37, R43, R45, R49, R53: 10R; R0805
R24, R63: 10K; R0805
R25, R35: 33R; R0805
R28, R29: 100R; R0805
R30, R32, R40, R42: 22R/2-3W; R2512
R33, R60, R62: 30K; R0805
R34, R39: 1R; R0805
R38: 47K; R0805
R41, R44, R54, R56, R57, R61, R64, R65: 1K; R0805
R46: 7K5; R0805
R47, R48, R52: 86K6; R0805
R50: 15K; R0805
R51, R58: 4K7; R0805
R55: 6R2; R0805
R59: 5K6; R0805
SH1, SH2: SHORTNOHOLE; SHORT_NOHOLE
TP2: JUMPER-2PIN-2MM; 2MM-2
TP3, TP4, TP5: TEST-PIN1.2; TEST-PIN_1.2MM
TR2: 53100C; MURATA_5300
TR3: VAC T60006-L2025-W380; VAC_DUAL_SEC
X3: B2B-ZR
ZD4: MMSZ5V1T1G; SOD323-W

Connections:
0V: C29.1, C30.1, C34.-, C35.-, C36.2, C38.2, C39.2, C40.2, C42.1, C44.2, C45.2, D12.2 (A), IC2.9 (GNDB), Q3.S, Q5.S, Q6.S, R38.2, R39.1, R39.2, SH1.P$2 (GND_B), SH2.P$1 (GND_A), TP3.1, TP4.1, TP5.1; also elsewhere on the board
!FAULT: OK2.4 (COL); also elsewhere on the board
+5VREF: C48.2, IC3.4 (REF), R43.1, R58.2, R59.2, X3.2; also elsewhere on the board
+14V: C29.2, C30.2, C52.1, C53.1, IC4.8 (V+), OK2.1 (A), R23.2, R36.2, R45.2; also elsewhere on the board
AGND: C37.1, C43.2, C46.1, C47.2, C48.1, C49.1, C50.1, C51.2, C52.2, C54.2, C55.1, C56.1, IC2.4 (GNDI), IC2.5 (DISABLE), IC3.10 (PGND), IC3.11 (AGND), IC4.4 (V-), Q4.1 (C), R33.1, R34.1, R34.2, R46.2, R50.2, R52.2, R56.2, R57.2, R61.2, R62.2, R63.2, R64.2, R65.2, SH2.P$2 (GND_B), ZD4.A; also elsewhere on the board
BUCK_OUT: C31.2, C32.2, C33.2, D12.1 (C), IC2.14 (GNDA), L7.2, L8.2, Q2.S, Q3.D
CLAMP_C: C42.2, D16.1 (C), D16.3 (C), D19.1 (C), D19.3 (C), R40.1, R42.1, R48.2
COMP: C50.2, IC3.3 (COMP); also elsewhere on the board
CT_OUT+: D21.A, R24.1, TR2.3 (S)
CT_OUT-: R24.2, R55.2, R57.1, TR2.1 (S_DOT)
DC_BUS: C34.+, C35.+, C36.1, D15.C, R22.1, TR2.7; also elsewhere on the board
FB: C51.1, IC3.2 (FB), R47.1, R56.1, R60.1
GND: OK2.3 (EMIT); also elsewhere on the board
GNDA: SH1.P$1 (GND_A); also elsewhere on the board
HD: IC3.5 (HD), R28.2
HI_OUT: IC2.15 (VOA), R25.2, R26.2
LD: IC3.6 (LD), R29.2
LO_OUT: IC2.10 (VOB), R35.1, R37.1
L_PULL: C41.2, D19.2 (A), L8.1, Q6.D, TR3.P1_DOT (P_DOT)
L_PUSH: D16.2 (A), L7.1, Q5.D, R30.2, TR3.P1
unnamed: R27.2, R31.1, TP2.1
unnamed: C31.1, C32.1, C33.1, D10.1 (C), D10.3 (C), IC2.16 (VDDA)
unnamed: R30.1, R32.2
unnamed: R22.2, R27.1
unnamed: C54.1, D24.C, IC4.2 (-IN), R59.1, R64.1
unnamed: D20.C, Q5.G, R49.1
unnamed: D22.C, Q6.G, R53.1
unnamed: Q2.D, TR2.8 (P_DOT)
unnamed: C41.1, R32.1
unnamed: IC3.15 (RT/SYNC), R52.1
unnamed: D11.A, Q2.G, R25.1
unnamed: IC3.14 (TIME), R50.1
unnamed: C46.2, IC3.13 (SS)
unnamed: IC3.16 (UVLO), R44.1, ZD4.C
unnamed: IC4.6 (-IN), R58.1, R62.1
unnamed: D14.A, Q3.G, R35.2, R38.1
unnamed: R47.2, R48.1
unnamed: D10.2 (A), R23.1
unnamed: OK2.2 (C), R41.1
unnamed: C56.2, IC4.3 (+IN), R60.2
unnamed: D15.A, R40.2, R42.2
unnamed: IC2.1 (VIA), R28.1
unnamed: C49.2, IC3.12 (CS), R54.2
unnamed: D23.A, IC4.1 (OUT)
unnamed: IC2.2 (VIB), R29.1
unnamed: C55.2, IC4.5 (+IN), R63.1, X3.1
unnamed: D11.C, R26.1
unnamed: D25.A, IC4.7 (OUT)
unnamed: IC2.6 (DT), R33.2
unnamed: D23.C, D25.C, R51.2, R61.1
unnamed: D14.C, R37.2
unnamed: C44.1, C45.1, IC3.1 (VIN), IC3.7 (VCC), R45.1
unnamed: C38.1, C39.1, C40.1, D13.C, IC2.11 (VDDB)
unnamed: D21.C, R54.1, R55.1
unnamed: C53.2, D24.A, R65.1
unnamed: D13.A, R36.1
unnamed: C47.1, Q4.2 (G), R51.1
unnamed: D17.C, D18.C, Q4.3 (A)
unnamed: D17.A, R41.2
PULL: D22.A, IC3.9 (PULL), R53.2
PUSH: D20.A, IC3.8 (PUSH), R49.2
REF: C37.2, IC2.3 (VDDI), IC2.8 (VDDI), R43.2
S1_DOT_OUT: TR3.S1_DOT; also elsewhere on the board
S1_OUT: TR3.S1; also elsewhere on the board
S2_DOT_OUT: TR3.S2_DOT; also elsewhere on the board
S2_OUT: TR3.S2; also elsewhere on the board
UVLO: C43.1, D18.A, R31.2, R44.2, R46.1, TP2.2; also elsewhere on the board

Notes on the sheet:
Licensed under the TAPR Open Hardware License (www.tapr.org/OHL)
Repository: https://github.com/eez-open/CF-DIC
More info at https://www.envox.hr/eez
Current-fed dual inductor converter (CF-DIC) OTP, OVP/short-circuit protection
OVP and OTP
2:1:1 (28/14/14 turns)
Pri: Ø 0.4 mm x 3 + CB-HFT2.4
Sec: Ø 0.4 mm x 6

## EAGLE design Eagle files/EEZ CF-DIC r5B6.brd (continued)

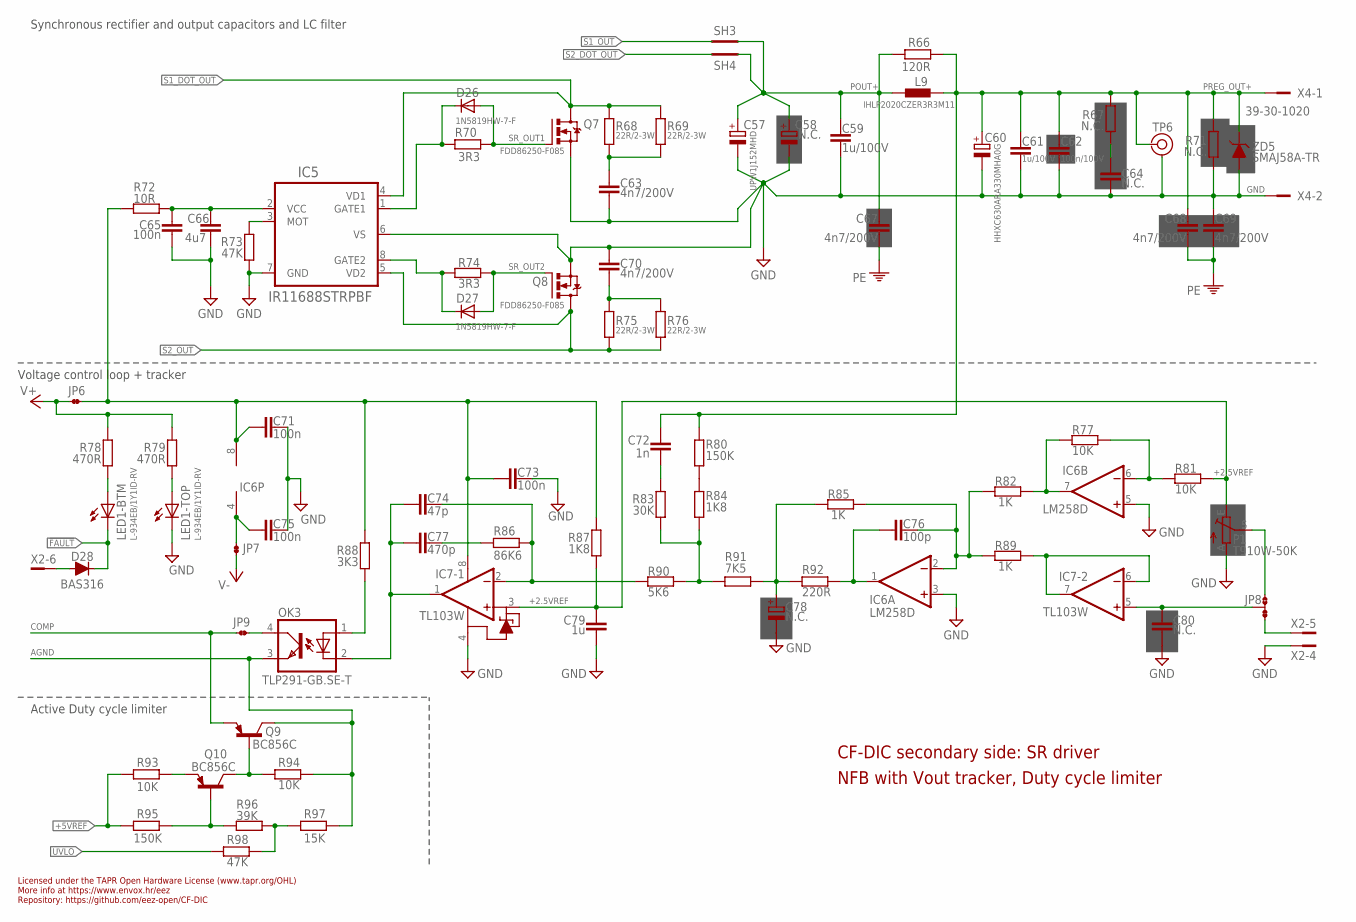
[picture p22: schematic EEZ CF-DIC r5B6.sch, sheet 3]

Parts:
C57: UPW1J152MHD; ECAP7.5/18-H35.5-2A
C58: N.C.; ECAP7.5/18
C59, C61: 1u/100V; C1206
C60: HHXC630ARA330MHA0G; CAPAE830X1050N
C62: 100n/100V; C1206
C63, C67, C68, C69, C70: 4n7/200V; C1206
C64: N.C.; C1206
C65, C71, C73, C75: 100n; C0603
C66: 4u7; C1206
C72: 1n; C0805
C74: 47p; C0805
C76: 100p; C0805
C77: 470p; C0805
C78: N.C.; EC1206
C79: 1u; C0805
C80: N.C.; C0805
D26, D27: 1N5819HW-7-F; SOD323-W
D28: BAS316; SOD323-R
IC5: IR11688STRPBF; SO8
IC6: LM258D; SOIC127P600X173-8N
IC7: TL103W; SOIC127P600X173-8N
JP6, JP7, JP9: JP2-NOCUT
JP8: JP3-CUT
L9: IHLP2020CZER3R3M11; IHLP-2020BZ-11
LED1: L-934EB/1Y1ID-RV; L-934EB
OK3: TLP291-GB.SE-T; SO4
P1: T910W-50K; S64W
Q7, Q8: FDD86250-F085; TO263
Q9, Q10: BC856C; SOT23-BEC
R66: 120R; R0805
R67: N.C.; R1210
R68, R69, R75, R76: 22R/2-3W; R2512
R70, R74: 3R3; R0805
R71: N.C.; R2512
R72: 10R; R0805
R73, R98: 47K; R0805
R77, R81, R93, R94: 10K; R0805
R78, R79: 470R; R0805
R80, R95: 150K; R0805
R82, R85, R89: 1K; R0805
R83: 30K; R0805
R84, R87: 1K8; R0805
R86: 86K6; R0805
R88: 3K3; R0805
R90: 5K6; R0805
R91: 7K5; R0805
R92: 220R; R0805
R96: 39K; R0805
R97: 15K; R0805
SH3, SH4: SHORTNOHOLE; SHORT_NOHOLE
TP6: TEST_POINT-2; TP_1.1MM_2
X2: 22-05-7095; SPOX_22-05-7095
X4: 39-30-1020; MINIFIT_39301020
ZD5: SMAJ58A-TR; DO214AC

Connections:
!FAULT: D28.C, LED1.BC (C); also elsewhere on the board
+2.5VREF: C79.1, IC7.3 (+IN1), P1.E, R81.2, R87.1
+5VREF: R93.1, R95.1; also elsewhere on the board
AGND: OK3.3 (EMIT), Q9.C, R94.2, R97.2; also elsewhere on the board
COMP: JP9.1, Q9.E; also elsewhere on the board
GND: C57.-, C58.-, C59.2, C60.-, C61.2, C62.2, C63.2, C64.1, C65.2, C66.2, C69.1, C70.2, C71.2, C73.2, C75.2, C78.-, C79.2, C80.2, IC5.6 (VS), IC5.7 (GND), IC6.3 (+IN), IC6.5 (+IN), IC7.4 (VCC-), LED1.TC (C), P1.A, Q7.2 (S), Q8.2 (S), R71.1, R73.2, TP6.GND, X2.4, X4.2, ZD5.A; also elsewhere on the board
unnamed: D28.A, X2.6
unnamed: C64.2, R67.1
unnamed: C77.2, R86.2
unnamed: C74.2, IC7.2 (-IN1), R86.1, R90.1
unnamed: LED1.TA (A), R79.2
unnamed: R80.1, R84.2
unnamed: LED1.BA (A), R78.2
unnamed: IC5.3 (MOT), R73.1
unnamed: C72.2, R83.2
unnamed: C75.1, IC6.4 (V-), JP7.1
unnamed: JP9.2, OK3.4 (COL)
unnamed: C71.1, C73.1, IC6.8 (V+), IC7.8 (VCC+), JP6.2, R72.1, R87.2, R88.2
unnamed: R83.1, R84.1, R90.2, R91.2
unnamed: IC6.7 (OUT), R77.1, R82.2
unnamed: C80.1, IC7.5 (+IN), JP8.COM
unnamed: JP8.NO, P1.S
unnamed: Q9.B, Q10.C, R94.1
unnamed: Q10.E, R93.2
unnamed: C76.2, IC6.2 (-IN), R82.1, R85.2, R89.1
unnamed: C63.1, R68.2, R69.2
unnamed: C70.1, R75.2, R76.2
unnamed: R96.2, R97.1, R98.1
unnamed: Q10.B, R95.2, R96.1
unnamed: D26.C, IC5.1 (GATE1), R70.2
unnamed: D27.C, IC5.8 (GATE2), R74.2
unnamed: C74.1, C77.1, IC7.1 (OUT1), OK3.2 (C)
unnamed: IC6.6 (-IN), R77.2, R81.1
unnamed: C76.1, IC6.1 (OUT), R92.2
NFB_OFFSET: C78.+, R85.1, R91.1, R92.1
OK_A: OK3.1 (A), R88.1
PE: C67.2, C68.2, C69.2; also elsewhere on the board
POUT+: C57.+, C58.+, C59.1, C67.1, L9.1, R66.1, SH3.P$2 (GND_B), SH4.P$1 (GND_A)
PREG_OUT+: C60.+, C61.1, C62.1, C68.1, C72.1, L9.2, R66.2, R67.2, R71.2, R80.2, TP6.TIP, X4.1, ZD5.C; also elsewhere on the board
S1_DOT_OUT: IC5.4 (VD1), Q7.3 (D), R68.1, R69.1; also elsewhere on the board
S1_OUT: SH3.P$1 (GND_A); also elsewhere on the board
S2_DOT_OUT: SH4.P$2 (GND_B); also elsewhere on the board
S2_OUT: IC5.5 (VD2), Q8.3 (D), R75.1, R76.1; also elsewhere on the board
SR_OUT1: D26.A, Q7.1 (G), R70.1
SR_OUT2: D27.A, Q8.1 (G), R74.1
SYNC_VCC: C65.1, C66.1, IC5.2 (VCC), R72.2
UVLO: R98.2; also elsewhere on the board
U_CTRL: JP8.NC, X2.5
U_MON1: IC7.6 (-IN), IC7.7 (OUT), R89.2
V+: JP6.1, R78.1, R79.1; also elsewhere on the board
V-: JP7.2; also elsewhere on the board

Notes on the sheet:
Licensed under the TAPR Open Hardware License (www.tapr.org/OHL)
Repository: https://github.com/eez-open/CF-DIC
More info at https://www.envox.hr/eez
CF-DIC secondary side: SR driver
NFB with Vout tracker, Duty cycle limiter
Voltage control loop + tracker
Synchronous rectifier and output capacitors and LC filter
Active Duty cycle limiter

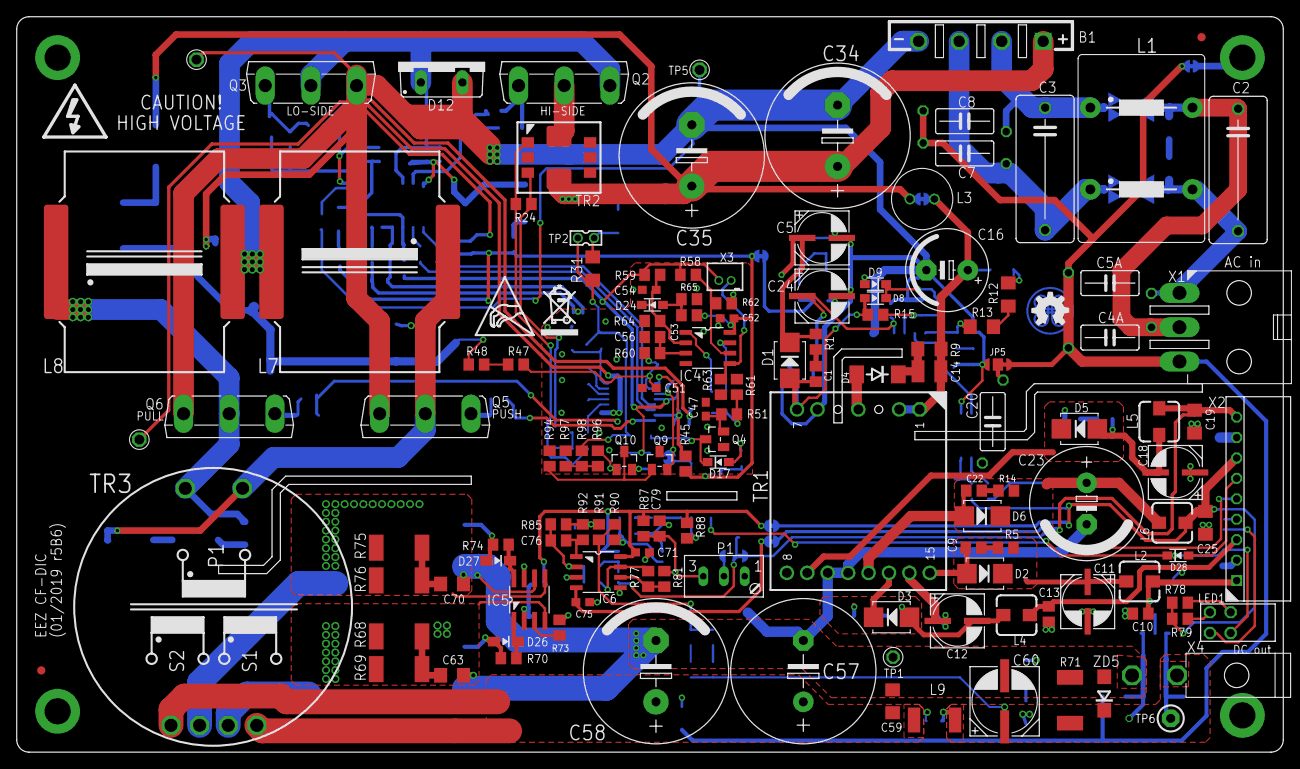
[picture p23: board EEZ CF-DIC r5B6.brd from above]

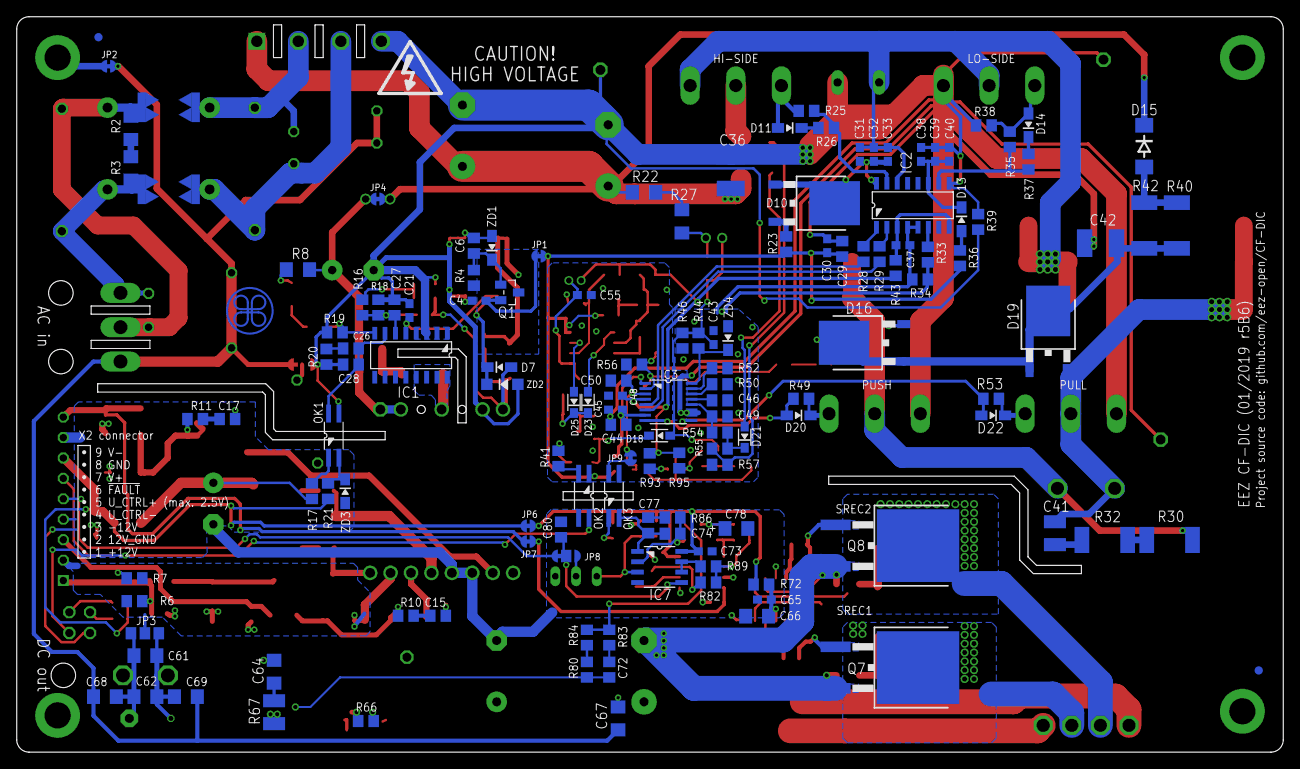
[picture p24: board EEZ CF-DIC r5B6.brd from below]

Board: 2 copper layers, 155.0 x 90.0 mm, 278 parts (137 on the bottom side), 147 nets.

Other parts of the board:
EEZ_SIGNATURE: SIGNATURESMALL; SIGNATURE_5MM
U$2: RECYCLE_BIN1/8
U$4: ESD_SYMBOL

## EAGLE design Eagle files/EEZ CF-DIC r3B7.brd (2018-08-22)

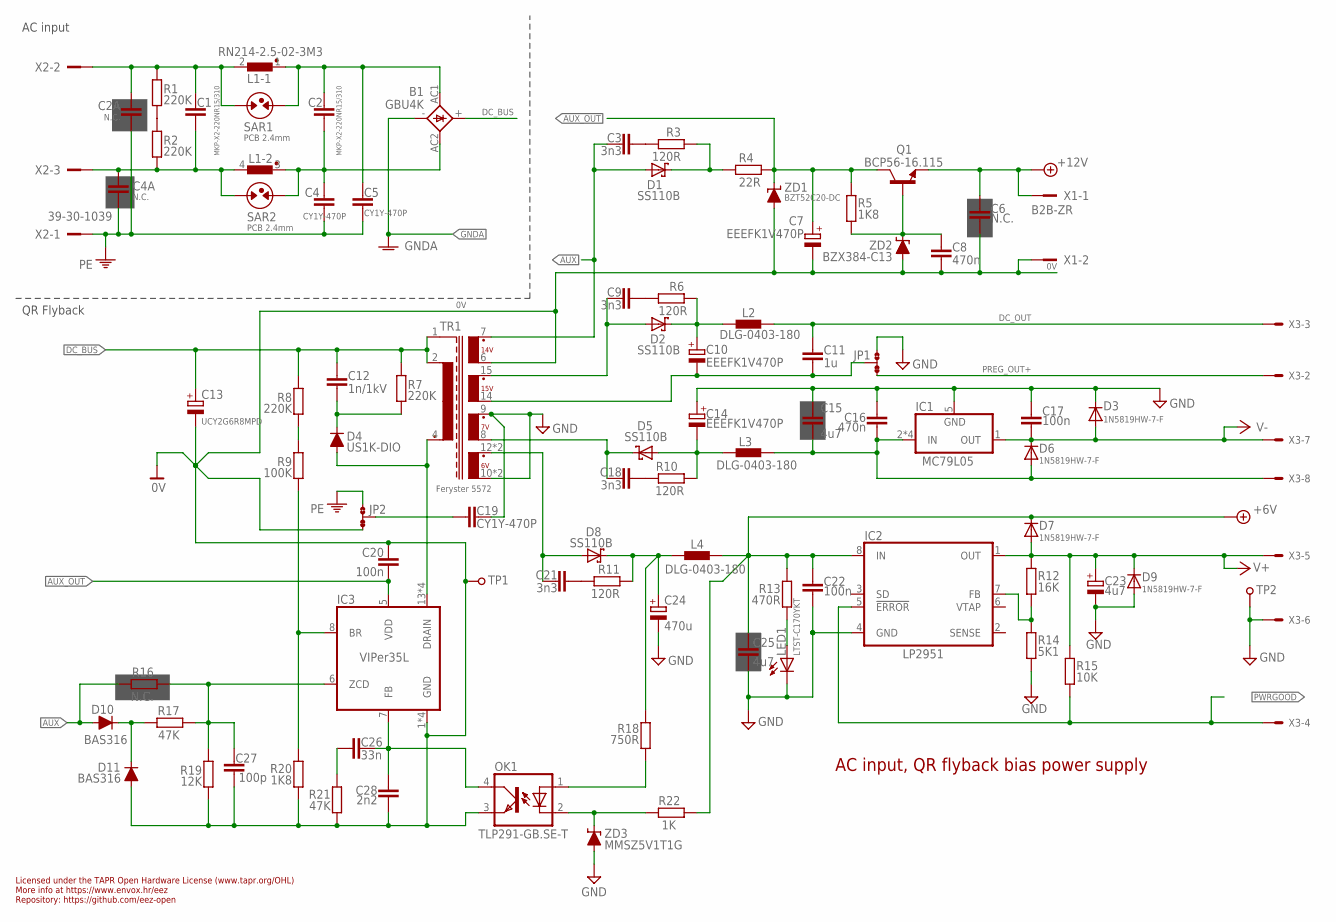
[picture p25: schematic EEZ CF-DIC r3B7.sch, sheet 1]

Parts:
B1: GBU4K; GBU4K_CRE
C1, C2: MKP-X2-220NR15/310; C150-072X183
C2A, C4A: N.C.; CY075-032X103
C3, C9, C18, C21: 3n3; C0805
C4, C5, C19: CY1Y-470P; CY075-032X103
C6: N.C.; C0603
C7, C10, C14: EEEFK1V470P; CAPAE660X610N
C8, C16: 470n; C0805
C11: 1u; C0805
C12: 1n/1kV; C1210
C13: UCY2G6R8MPD; ECAP5/10.5
C15, C25: 4u7; C1206
C17, C20, C22: 100n; C0603
C23: 4u7; EC1206
C24: 470u; ECAP5/10.5
C26: 33n; C0805
C27: 100p; C0805
C28: 2n2; C0805
D1, D2, D5, D8: SS110B; SMB
D3, D6, D7, D9: 1N5819HW-7-F; SOD323-W
D4: US1K-DIO; DO214AA
D10, D11: BAS316; SOD323-R
IC1: MC79L05; SOIC127P600X173-8N
IC2: LP2951; SOIC127P600X175-8N
IC3: VIPer35L; SOIC-16
JP1, JP2: JP3-CUT
L1: RN214-2.5-02-3M3; RN214; FARNELL 1191518
L2, L3, L4: DLG-0403-180; DE0403
LED1: LTST-C170YKT; LED_0805
OK1: TLP291-GB.SE-T; SO4
Q1: BCP56-16.115; SOT230P700X180-4N
R1, R2, R7, R8: 220K; R1206
R3, R6, R10, R11: 120R; R0805
R4: 22R; R0805
R5, R20: 1K8; R0805
R9: 100K; R0805
R12: 16K; R0805
R13: 470R; R0805
R14: 5K1; R0805
R15: 10K; R0805
R16: N.C.; R0805
R17, R21: 47K; R0805
R18: 750R; R0805
R19: 12K; R0805
R22: 1K; R0805
SAR1, SAR2: PCB 2.4mm; PCB-SAR_2.4MM
TP1, TP2: PCB_TEST_TABSHIELD; PCB_SHIELD_TAB
TR1: Feryster 5572; FERYSTER_5572
X1: B2B-ZR
X2: 39-30-1039; MINIFIT_39301039_CRE
X3: 90136-1208; 70543-08
ZD1: BZT52C20-DC; SOD123FL
ZD2: BZX384-C13; SOD323-W
ZD3: MMSZ5V1T1G; SOD323-W

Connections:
0V: C6.2, C7.2 (-), C8.2, C13.-, C20.1, C27.2, C28.2, D11.A, IC3.1 (GND), IC3.2 (GND), IC3.3 (GND), IC3.4 (GND), JP2.NC, OK1.3 (EMIT), R19.1, R20.2, R21.2, TP1.1, TR1.6 (S_BIAS), X1.2, ZD1.A, ZD2.A; also elsewhere on the board
6VAC: C21.2, D8.A, TR1.12 (S1_DOT), TR1.13 (S1_DOT)
7VAC: C18.2, D5.C, TR1.8 (S2)
15VAC: C9.2, D2.A, TR1.15 (S3_DOT)
+6V: C22.1, C25.1, D7.C, IC2.8 (IN), L4.2, R13.1, R22.2; also elsewhere on the board
+6V_REC: C24.+, D8.C, L4.1, R11.1, R18.1
+12V: C6.1, Q1.3 (E), X1.1; also elsewhere on the board
+15V_REC: C10.1 (+), D2.C, L2.1, R6.1
-7V_REC: C14.2 (-), D5.A, L3.1, R10.1
-9V: C15.2, C16.2, D6.A, IC1.2 (IN), IC1.3 (IN), IC1.6 (IN), IC1.7 (IN), L3.2, X3.8
-15V: C10.2 (-), C11.2, JP1.COM, TR1.14 (S3)
AUX: C3.2, D1.A, D10.A, R16.2, TR1.7 (S_BIAS_DOT)
AUX_OUT: C7.1 (+), C20.2, IC3.5 (VDD), Q1.2 (C), Q1.4 (C), R4.2, R5.1, ZD1.C
DC_BUS: B1.+, C12.1, C13.+, R7.1, R8.1, TR1.1 (SHIELD), TR1.2; also elsewhere on the board
DC_OUT: C11.1, L2.2, X3.3
FB2: OK1.2 (C), R22.1, ZD3.C
GND: C14.1 (+), C15.1, C16.1, C17.1, C19.2, C22.2, C23.-, C24.-, C25.2, D3.C, D9.A, IC1.5 (GND), IC2.4 (GND), JP1.NO, LED1.C, R14.2, TP2.1, TR1.9 (S2_DOT), TR1.10 (S1), TR1.11 (S1), X3.6, ZD3.A; also elsewhere on the board
GNDA: B1.-; also elsewhere on the board
unnamed: C19.1, JP2.COM
unnamed: LED1.A, R13.2
unnamed: B1.AC1, C2.1, C5.2, L1.1, SAR1.2
unnamed: IC3.8 (BR), R9.2, R20.1
unnamed: B1.AC2, C2.2, C4.2, L1.3 (1), SAR2.2
unnamed: D1.C, R3.1, R4.1
unnamed: C1.1, C2A.2, L1.2, R1.1, SAR1.1, X2.2
unnamed: C1.2, C4A.2, L1.4 (2), R2.2, SAR2.1, X2.3
unnamed: R1.2, R2.1
unnamed: R8.2, R9.1
unnamed: IC2.7 (FB), R12.2, R14.1
unnamed: C8.1, Q1.1 (B), R5.2, ZD2.C
unnamed: OK1.1 (A), R18.2
unnamed: C12.2, D4.C, R7.2
unnamed: C26.2, C28.1, IC3.7 (FB), OK1.4 (COL)
unnamed: C9.1, R6.2
unnamed: C3.1, R3.2
unnamed: C27.1, IC3.6 (ZCD), R16.1, R17.1, R19.2
unnamed: C18.1, R10.2
unnamed: C21.1, R11.2
unnamed: C26.1, R21.1
unnamed: D10.C, D11.C, R17.2
PE: C2A.1, C4.1, C4A.1, C5.1, JP2.NO, X2.1
PREG_OUT+: JP1.NC, X3.2; also elsewhere on the board
PWRGOOD: IC2.5 (!ERROR), R15.2, X3.4; also elsewhere on the board
V+: C23.+, D7.A, D9.C, IC2.1 (OUT), R12.1, R15.1, X3.5; also elsewhere on the board
V-: C17.2, D3.A, D6.C, IC1.1 (OUT), X3.7; also elsewhere on the board
VIPER_D: D4.A, IC3.13 (DRAIN), IC3.14 (DRAIN), IC3.15 (DRAIN), IC3.16 (DRAIN), TR1.4 (P2_DOT)

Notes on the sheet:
Licensed under the TAPR Open Hardware License (www.tapr.org/OHL)
Repository: https://github.com/eez-open
More info at https://www.envox.hr/eez
AC input, QR flyback bias power supply
QR Flyback
AC input

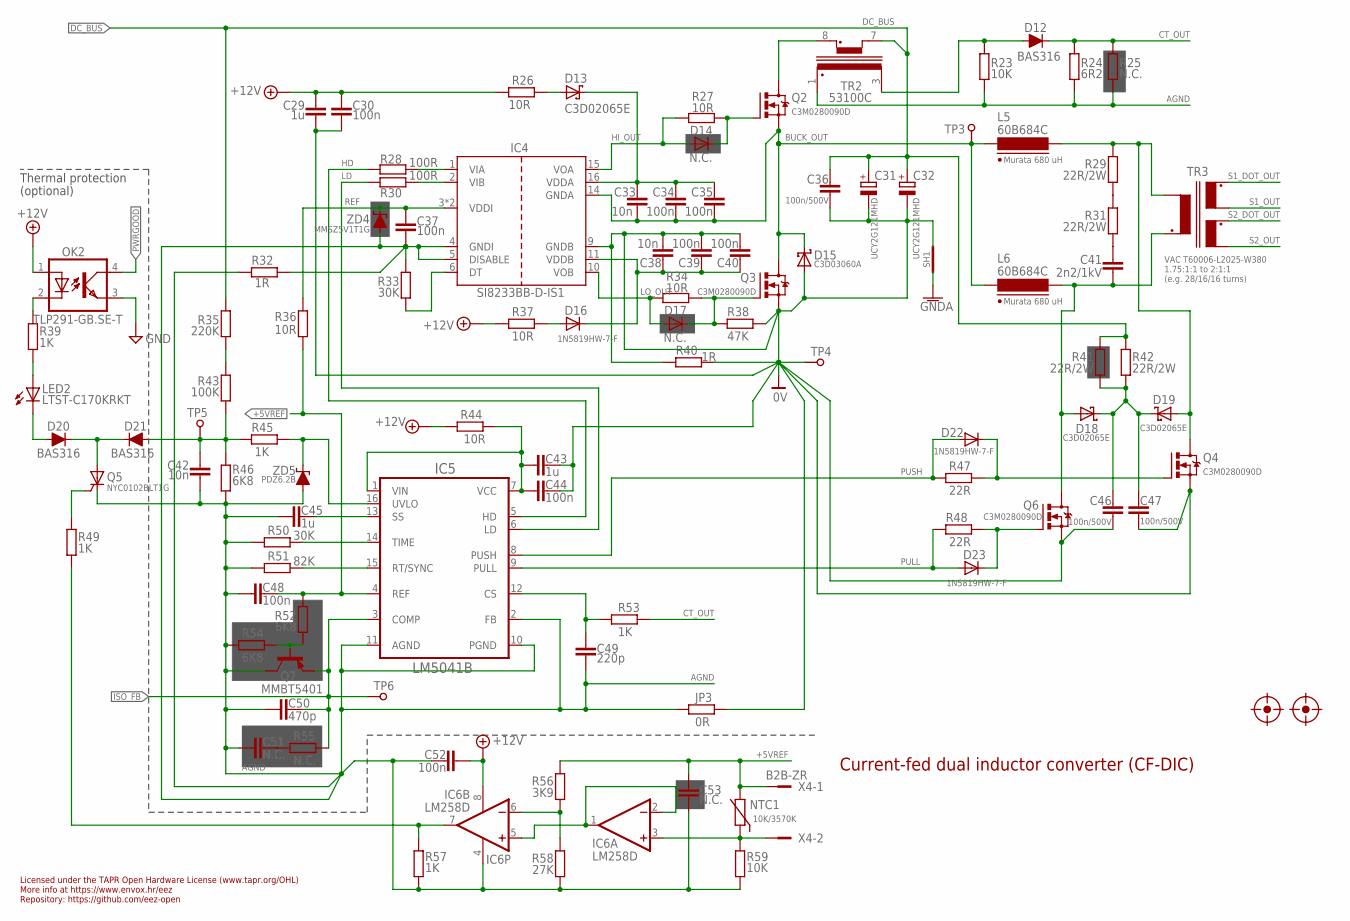
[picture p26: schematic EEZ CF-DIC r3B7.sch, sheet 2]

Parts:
C29, C43, C45: 1u; C0805
C30, C34, C35, C37, C39, C40, C44, C48, C52: 100n; C0603
C31, C32: UCY2G121MHD; ECAP7.5/18
C33, C38, C42: 10n; C0603
C36, C46, C47: 100n/500V; C1812
C41: 2n2/1kV; C1210
C49: 220p; C0805
C50: 470p; C0805
C51: N.C.; C0805
C53: N.C.; C0603
D12, D20, D21: BAS316; SOD323-R
D13, D18, D19: C3D02065E; TO252
D14, D17: N.C.; SOD323-W
D15: C3D03060A; TO220-2
D16, D22, D23: 1N5819HW-7-F; SOD323-W
FM1, FM2: FIDUCIAL_2; FIDUCIAL_DUAL
IC4: SI8233BB-D-IS1; SOIC-16
IC5: LM5041B; MTC16
IC6: LM258D; SOIC127P600X173-8N
JP3: 0R; R0805
L5, L6: 60B684C; MURATA_6000B
LED2: LTST-C170KRKT; LED_0805
NTC1: 10K/3570K; R_0805
OK2: TLP291-GB.SE-T; SO4
Q2, Q3, Q4, Q6: C3M0280090D; TO247BV
Q5: NYC0102BLT1G; SOT23
Q7: MMBT5401; SOT23-BEC
R23, R59: 10K; R0805
R24: 6R2; R0805
R25, R55: N.C.; R0805
R26, R27, R34, R36, R37, R44: 10R; R0805
R28, R30: 100R; R0805
R29, R31, R41, R42: 22R/2W; R2512
R32, R40: 1R; R0805
R33, R50: 30K; R0805
R35: 220K; R1206
R38: 47K; R0805
R39, R45, R49, R53, R57: 1K; R0805
R43: 100K; R0805
R46, R52, R54: 6K8; R0805
R47, R48: 22R; R0805
R51: 82K; R0805
R56: 3K9; R0805
R58: 27K; R0805
SH1: SHORTNOHOLE; SHORT_NOHOLE
TP3, TP4, TP5, TP6: PCB_TEST_TABSHIELD; PCB_SHIELD_TAB
TR2: 53100C; MURATA_5300
TR3: VAC T60006-L2025-W380; VAC_DUAL_SEC
X4: B2B-ZR
ZD4: MMSZ5V1T1G; SOD323-W
ZD5: PDZ6.2B; SOD323-W

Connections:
0V: C29.1, C30.1, C31.-, C32.-, C36.1, C38.2, C39.2, C40.2, C43.2, C44.2, C46.1, C47.1, D15.2 (A), IC4.9 (GNDB), JP3.1, Q3.S, Q4.S, Q6.S, R38.2, R40.1, R40.2, SH1.P$2 (GND_B), TP4.1; also elsewhere on the board
+5VREF: C48.2, C53.1, IC5.4 (REF), NTC1.1, R36.1, R52.1, R56.2, X4.1
+12V: C29.2, C30.2, C52.1, IC6.8 (V+), OK2.1 (A), R26.2, R37.2, R44.2; also elsewhere on the board
AGND: C37.1, C42.2, C45.1, C48.1, C49.1, C50.1, C51.1, C52.2, C53.2, IC4.4 (GNDI), IC4.5 (DISABLE), IC5.2 (FB), IC5.10 (PGND), IC5.11 (AGND), IC6.4 (V-), JP3.2, Q5.1 (C), Q7.C, R23.2, R24.2, R25.2, R32.1, R32.2, R33.1, R46.2, R50.2, R51.2, R54.2, R57.2, R58.2, R59.2, TR2.1 (S_DOT), ZD4.A, ZD5.A; also elsewhere on the board
BUCK_OUT: C33.2, C34.2, C35.2, D15.1 (C), IC4.14 (GNDA), L5.2, L6.2, Q2.S, Q3.D, TP3.1
CLAMP_C: C46.2, C47.2, D18.1 (C), D18.3 (C), D19.1 (C), D19.3 (C), R41.1, R42.1
CT_OUT: D12.C, R24.1, R25.1, R53.1
DC_BUS: C31.+, C32.+, C36.2, R35.1, R41.2, R42.2, TR2.7; also elsewhere on the board
GND: OK2.3 (EMIT); also elsewhere on the board
GNDA: SH1.P$1 (GND_A); also elsewhere on the board
HD: IC5.5 (HD), R28.2
HI_OUT: D14.A, IC4.15 (VOA), R27.2
ISO_FB: C50.2, IC5.3 (COMP), Q7.E, R55.1, TP6.1; also elsewhere on the board
LD: IC5.6 (LD), R30.2
LO_OUT: D17.A, IC4.10 (VOB), R34.1
L_PULL: C41.2, D18.2 (A), L6.1, Q6.D, TR3.P1_DOT (P_DOT)
L_PUSH: D19.2 (A), L5.1, Q4.D, R29.2, TR3.P1
unnamed: R35.2, R43.1
unnamed: C33.1, C34.1, C35.1, D13.1 (C), D13.3 (C), IC4.16 (VDDA)
unnamed: C41.1, R31.1
unnamed: IC6.3 (+IN), NTC1.2, R59.1, X4.2
unnamed: D22.C, Q4.G, R47.1
unnamed: D23.C, Q6.G, R48.1
unnamed: LED2.A, R39.2
unnamed: IC5.15 (RT/SYNC), R51.1
unnamed: D14.C, Q2.G, R27.1
unnamed: IC5.14 (TIME), R50.1
unnamed: C45.2, IC5.13 (SS)
unnamed: IC5.16 (UVLO), R45.1, ZD5.C
unnamed: IC6.6 (-IN), R56.1, R58.1
unnamed: D17.C, Q3.G, R34.2, R38.1
unnamed: D13.2 (A), R26.1
unnamed: OK2.2 (C), R39.1
unnamed: C51.2, R55.2
unnamed: IC4.1 (VIA), R28.1
unnamed: C49.2, IC5.12 (CS), R53.2
unnamed: IC6.7 (OUT), R49.2, R57.1
unnamed: IC4.2 (VIB), R30.1
unnamed: R29.1, R31.2
unnamed: IC6.1 (OUT), IC6.2 (-IN), IC6.5 (+IN)
unnamed: Q7.B, R52.2, R54.1
unnamed: IC4.6 (DT), R33.2
unnamed: D12.A, R23.1, TR2.3 (S)
unnamed: C43.1, C44.1, IC5.1 (VIN), IC5.7 (VCC), R44.1
unnamed: C38.1, C39.1, C40.1, D16.C, IC4.11 (VDDB)
unnamed: Q2.D, TR2.8 (P_DOT)
unnamed: D16.A, R37.1
unnamed: Q5.2 (G), R49.1
unnamed: D20.C, D21.C, Q5.3 (A)
unnamed: D20.A, LED2.C
PULL: D23.A, IC5.9 (PULL), R48.2
PUSH: D22.A, IC5.8 (PUSH), R47.2
PWRGOOD: OK2.4 (COL); also elsewhere on the board
REF: C37.2, IC4.3 (VDDI), IC4.8 (VDDI), R36.2, ZD4.C
S1_DOT_OUT: TR3.S1_DOT; also elsewhere on the board
S1_OUT: TR3.S1; also elsewhere on the board
S2_DOT_OUT: TR3.S2_DOT; also elsewhere on the board
S2_OUT: TR3.S2; also elsewhere on the board
ULVO: C42.1, D21.A, R43.2, R45.2, R46.1, TP5.1

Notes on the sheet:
Licensed under the TAPR Open Hardware License (www.tapr.org/OHL)
Repository: https://github.com/eez-open
More info at https://www.envox.hr/eez
Current-fed dual inductor converter (CF-DIC)
1.75:1:1 to 2:1:1
Murata 680 uH
(e.g. 28/16/16 turns)
(optional)
Thermal protection


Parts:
C54, C55, C56: UPW1J152MHD; ECAP7.5/18
C57, C60: 1u/100V; C1206
C58: HHXC630ARA330MHA0G; CAPAE830X1050N; TOLERANCE ±20 %; VOLTAGERATING 63 V; MPN EEE-FK1J470P
C59: HHXC630ARA330MHA0G; CAPAE830X1050N
C61: 100n/100V; C0805
C62: N.C.; C1206
C63, C67: 4n7/200V; C1206
C64, C66, C68, C69: 100n; C0603
C65: 10u; C1210
C70, C71: 100p; C0805
C72: 33n; C0805
C73: 4u7; EC1206
C74: 1u; C0805
C75, C76: N.C.; C0805
D24, D25: 1N5819HW-7-F; SOD323-W
IC7: IR11688STRPBF; SO8
IC8: TL072; SOIC127P600X173-8N
IC9: TL103W; SOIC127P600X173-8N
IC10: TL431; SOT103P240X110-3N
JP4: JP3-CUT
L7: IHLP2020CZER3R3M11; IHLP-2020BZ-11
OK3: TLP291-GB.SE-T; SO4
P1: T910W-50K; S64W
Q8, Q9: IRFS4321PBF; TO263
R60: 100R; R0805
R61: N.C.; R1210
R62, R63, R68, R69: 22R/3W; R2512
R64, R67: 3R3; R0805
R65: 10R; R0805
R66: 47K; R0805
R70, R72, R81: 10K; R0805
R71: 316K; R0805
R73, R75, R79: 750R; R0805
R74: 0R; R0805
R76: 470R; R0805
R77: 12K; R0805
R78: 3K3; R0805
R80: 30K; R0805
R82: 16K; R0805
R83: 220R; R0805
R84, R85, R86: N.C.; R0805
SH2, SH3: SHORTNOHOLE; SHORT_NOHOLE
TP7: TEST_POINT-2; TP_1.1MM_2
TP8: PCB_TEST_TABSHIELD; PCB_SHIELD_TAB
X3: 90136-1208; 70543-08
X5: 39-28-1023; MINIFIT_5566-02A
ZD6: SMAJ58A-TR; DO214AC

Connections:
+2.5VREF: C74.1, IC9.3 (+IN1), P1.E, R72.2, R78.1
+6V: R65.1; also elsewhere on the board
AGND: OK3.3 (EMIT); also elsewhere on the board
FB: C75.2, IC10.2 (REF), R77.1, R81.2, R82.2, R85.2, R86.2, TP8.1
GND: C54.-, C55.-, C56.-, C57.2, C58.2, C59.2, C60.2, C61.2, C62.1, C63.2, C64.2, C65.2, C66.2, C67.2, C68.2, C69.2, C73.-, C74.2, IC7.6 (VS), IC7.7 (GND), IC8.3 (+IN), IC8.5 (+IN), IC9.4 (VCC-), IC10.3 (A), P1.A, Q8.2 (S), Q9.2 (S), R66.2, R86.1, TP7.GND, X5.2, ZD6.A; also elsewhere on the board
ISO_FB: OK3.4 (COL); also elsewhere on the board
unnamed: C70.2, IC8.2 (-IN), R74.2, R75.1, R79.1
unnamed: C64.1, C65.1, IC7.2 (VCC), R65.2
unnamed: C62.2, R61.1
unnamed: C72.2, R80.2
unnamed: C71.2, IC9.2 (-IN1), R80.1, R81.1
unnamed: R71.1, R77.2
unnamed: C76.2, R85.1
unnamed: IC7.3 (MOT), R66.1
unnamed: IC8.7 (OUT), R70.1, R75.2
unnamed: IC9.5 (+IN), JP4.COM
unnamed: JP4.NO, P1.S
unnamed: R73.2, R74.1
unnamed: C63.1, R62.2, R63.2
unnamed: C67.1, R68.2, R69.2
unnamed: D24.C, IC7.1 (GATE1), R64.2
unnamed: D25.C, IC7.8 (GATE2), R67.2
unnamed: C71.1, C72.1, C75.1, C76.1, IC9.1 (OUT1), IC10.1 (C), OK3.2 (C), R84.2
unnamed: IC8.6 (-IN), R70.2, R72.1
unnamed: C70.1, IC8.1 (OUT), R83.2
NFB_OFFSET: C73.+, R73.1, R82.1, R83.1
OK_A: OK3.1 (A), R76.1, R84.1
POUT+: C54.+, C55.+, C56.+, C57.1, L7.1, R60.1, R71.2, SH2.P$2 (GND_B), SH3.P$1 (GND_A)
PREG_OUT+: C58.1, C59.1, C60.1, C61.1, L7.2, R60.2, R61.2, TP7.TIP, X5.1, ZD6.C; also elsewhere on the board
S1_DOT_OUT: IC7.4 (VD1), Q8.3 (D), R62.1, R63.1; also elsewhere on the board
S1_OUT: SH2.P$1 (GND_A); also elsewhere on the board
S2_DOT_OUT: SH3.P$2 (GND_B); also elsewhere on the board
S2_OUT: IC7.5 (VD2), Q9.3 (D), R68.1, R69.1; also elsewhere on the board
SR_OUT1: D24.A, Q8.1 (G), R64.1
SR_OUT2: D25.A, Q9.1 (G), R67.1
U_MON: JP4.NC, X3.1
U_MON1: IC9.6 (-IN), IC9.7 (OUT), R79.2
V+: C66.1, C69.1, IC8.8 (V+), IC9.8 (VCC+), R76.2, R78.2; also elsewhere on the board
V-: C68.1, IC8.4 (V-); also elsewhere on the board

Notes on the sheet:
Licensed under the TAPR Open Hardware License (www.tapr.org/OHL)
Repository: https://github.com/eez-open
More info at https://www.envox.hr/eez
CF-DIC secondary side: SR driver
NFB with Vout tracker
Voltage control loop + tracker
Synchronous rectifier and output capacitors and LC filter
Optional NFB if tracker is not used!



Board: 2 copper layers, 155.0 x 85.0 mm, 260 parts (168 on the bottom side), 127 nets.

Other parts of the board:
EEZ_SIGNATURE: SIGNATURESMALL; SIGNATURE_5MM
U$2: RECYCLE_BIN1/8
U$4: ESD_SYMBOL
U$5: PB_SMALL

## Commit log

2018-07-22 BOM and schematic preview
    [EEZ CF-DIC r3B2 BOM.ods]
2018-07-22 Eagle and Gerber files
    [EEZ CF-DIC r3B2.GBL, EEZ CF-DIC r3B2.GBO, EEZ CF-DIC r3B2.GBS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]
2018-07-22 X2 12V connector added
    [EEZ CF-DIC r3B2.brd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]
2018-07-22 BOM updated
    [EEZ CF-DIC r3B2 BOM.ods]
2018-07-28 small changes on PCB, added alternative sync MOSFET in BOM
    [EEZ CF-DIC r3B2 BOM.ods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]
2018-07-28 fixed .sch - .brd inconsistency reported by Eagle 7.x
    [EEZ CF-DIC r3B2 BOM.ods, EEZ CF-DIC r3B2.brd, EEZ CF-DIC r3B2.sch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]
2018-07-29 BOM update, optional RC added at the output terminals
    [EEZ CF-DIC r3B2 BOM.ods, EEZ CF-DIC r3B2.brd, EEZ CF-DIC r3B2.sch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]
2018-07-29 modified thermals for output bulk capacitors
    [EEZ CF-DIC r3B2.brd, EEZ CF-DIC r3B2.sch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]
2018-07-30 Bridge rectifier relocated, Y2 capacitors optional positions added
    [EEZ CF-DIC r3B2.GBL, EEZ CF-DIC r3B2.GBO, EEZ CF-DIC r3B2.GBS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]
2018-07-31 Optional temperature alarm
    [EEZ CF-DIC r3B2 BOM.ods, EEZ CF-DIC r3B4 BOM.ods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]
2018-07-31 New values for temp. comparator
    [EEZ CF-DIC r3B4 BOM.ods, EEZ CF-DIC r3B4.brd, EEZ CF-DIC r3B4.sch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]
2018-08-22 r3B7 files without updated BOM
    [EEZ CF-DIC r3B4.brd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]
2018-08-26 first r3B8 version (no BOM)
    [EEZ CF-DIC r3B7.GBL, EEZ CF-DIC r3B7.GBO, EEZ CF-DIC r3B7.GBS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]
2018-08-26 QR flyback schematic reorganized
2018-08-28 notice about r3B7 PCB
2018-09-14 r4B4 with updated BOM
    [EEZ CF-DIC r3B4 BOM.ods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]
2018-09-14 JP2 rotated
    [EEZ CF-DIC r4B4.brd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]
2018-09-14 PCB parts images added
2018-09-14 PCB bottom parts image flipped horizontally
2018-09-14 Update Q1 in BOM
    [EEZ CF-DIC r4B4 BOM.ods]
2018-09-15 PWRGOOD renamed to FAULT
    [EEZ CF-DIC r4B4 BOM.ods, EEZ CF-DIC r4B4.brd, EEZ CF-DIC r4B4.sch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]
2018-09-15 #1, power inductors rotated, shorter PUSH gate trace
    [EEZ CF-DIC r4B4.brd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]
2018-10-22 r5B1 without updated BOM
    [EEZ CF-DIC r4B4.GBL, EEZ CF-DIC r4B4.GBO, EEZ CF-DIC r4B4.GBS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]
2018-10-22 X2 rotated for easier cable insertion
    [EEZ CF-DIC r5B1.brd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]
2018-11-30 r5B5 version
    [EEZ CF-DIC r4B4 BOM.ods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]
2018-12-01 C4, C5, C17 value changed
    [EEZ CF-DIC r5B5.brd, EEZ CF-DIC r5B5.sch]
2018-12-03 Mechanical drawings, optional EMI parts
    [CF-DIC enclosure r5B5.brd, CF-DIC enclosure r5B5.dxf, EEZ CF-DIC r5B5 BOM.ods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]
2018-12-04 fix OTP trip note is schematics
2018-12-04 C46 increased to 2n2
    [EEZ CF-DIC r5B5 BOM.ods]
2018-12-04 C46 increased to 2n2 (Eagle files)
    [EEZ CF-DIC r5B5.brd, EEZ CF-DIC r5B5.sch]
2018-12-15 enclosure drawings
2019-01-05 r5B6 version
    [EEZ CF-DIC r5B5 BOM.ods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]
2019-01-05 7V secondary wiring fix
    [EEZ CF-DIC r5B6.brd, EEZ CF-DIC r5B6.sch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]
2019-01-07 BOM update
    [EEZ CF-DIC r5B5 BOM.ods, EEZ CF-DIC r5B6 BOM.ods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]
2019-01-30 small fixes
    [CF-DIC enclosure r5B6.brd, CF-DIC enclosure r5B6.dxf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]
2019-02-27 #4, #5, #6
    [EEZ CF-DIC r5B6.GBL, EEZ CF-DIC r5B6.GBO, EEZ CF-DIC r5B6.GBS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]
2019-03-01 changed SR mosfets package
    [EEZ CF-DIC r5B7.brd, EEZ CF-DIC r5B7.sch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]
2019-03-03 r5B7 BOM
    [EEZ CF-DIC r5B6 BOM.ods, EEZ CF-DIC r5B7 BOM.ods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]
2019-03-06 NFB compensation and Viper Rovp adjustment
    [EEZ CF-DIC r5B7 BOM.ods, EEZ CF-DIC r5B7.brd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]
2019-03-22 #7, #8
    [EEZ CF-DIC block diagram r5B7.sch, EEZ CF-DIC r5B7.brd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]
2019-03-22 BOM update for #7, #8
    [EEZ CF-DIC block diagram r5B7.sch, EEZ CF-DIC r5B7 BOM.ods, EEZ CF-DIC r5B7.brd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]
2019-03-29 new LED1 and primary side snubbers
    [EEZ CF-DIC r5B7 BOM.ods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]

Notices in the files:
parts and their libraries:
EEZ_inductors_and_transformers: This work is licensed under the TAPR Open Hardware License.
